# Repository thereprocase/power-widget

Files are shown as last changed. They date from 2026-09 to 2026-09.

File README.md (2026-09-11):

# Power Widget

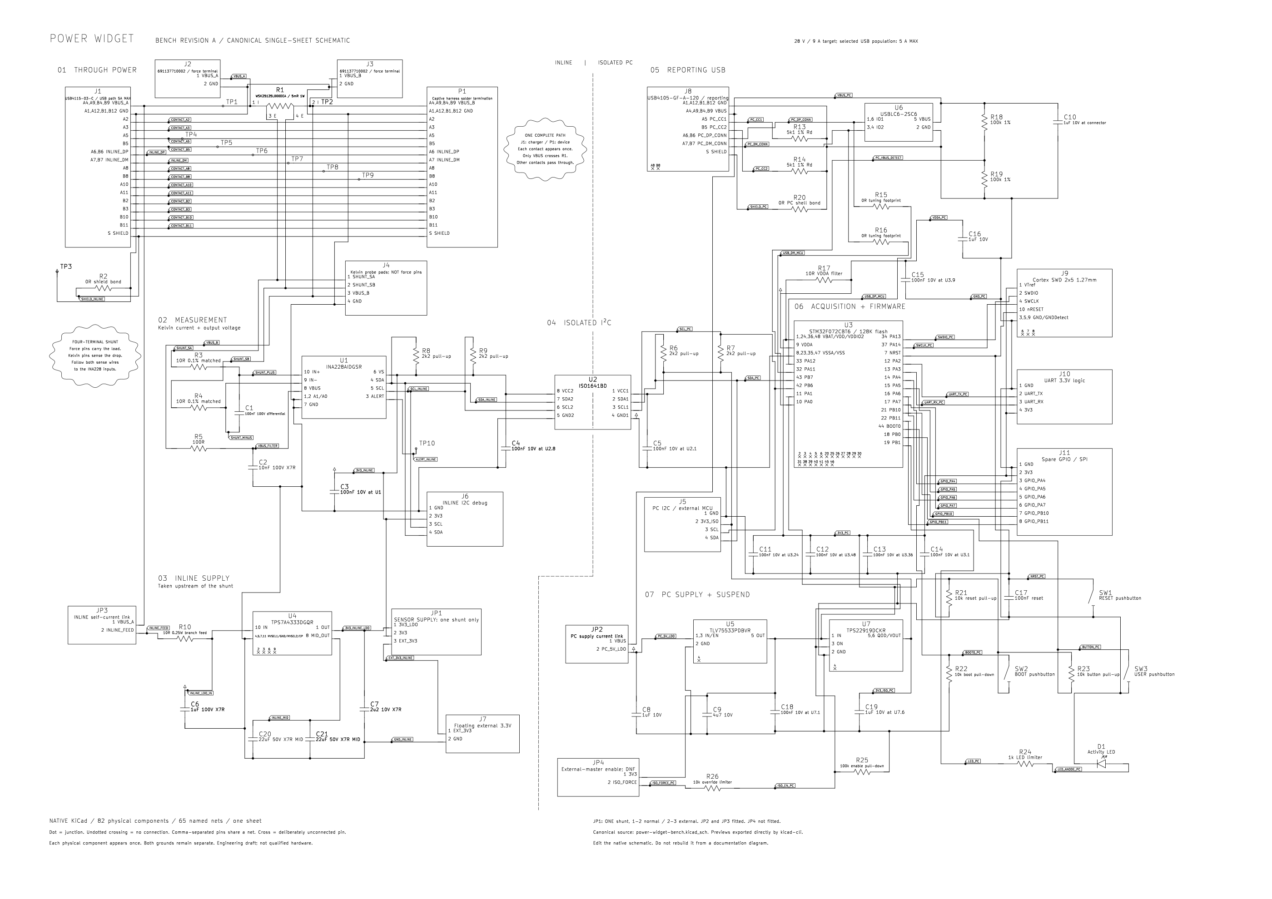
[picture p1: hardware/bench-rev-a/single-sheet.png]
Canonical single-sheet KiCad schematic: complete connectors, continuous wiring, Kelvin shunt and isolated USB reporting


**Canonical KiCad schematic.** This image is exported from the [native editable schematic](hardware/bench-rev-a/power-widget-bench.kicad_sch). The [earlier drawing was a layout mockup](hardware/bench-rev-a/layout-mockup.svg), not a KiCad export or the design authority.

**Reusable agent prompt, including the original inspiration:**

> think through the layout and topology from the perspective of a brilliant 1980s electrical engineer who stayed current on everything straight through to 2026. use his brain to architect the sheet and make it gorgeous
>
> Create a complete, flat, single-sheet schematic from this project's authoritative circuit data. Make the page explain the circuit: power and signal flow, measurement branches, isolation boundaries, supplies and service controls. Use traditional electrical symbols, continuous wires, explicit junction dots and unambiguous crossings: wire hops where supported, otherwise the native tool’s undotted-crossing convention. Keep every component and numbered pin accounted for; annotate wires with net names instead of replacing connections with labels. Preserve the circuit exactly. Use deliberate placement, readable typography and restrained color, with the clarity of a classic service-manual foldout. Verify connectivity against the source, export a zoomable SVG and printable PDF, put the image at the top of the README, and commit and push the result.
>
> Use conventional schematic symbols that engineers recognize on sight: ANSI-style zigzag resistors; parallel-plate nonpolarized capacitors and explicitly marked polarized capacitors; coil inductors; diode anode/cathode symbols with the cathode bar; LEDs with outward light arrows and photodiodes with inward light arrows; normally open or normally closed switch contacts shown in their unactuated state; connector pins, jumper links and test points; four-terminal Kelvin shunts with separate force and sense terminals; and, where present, BJT base/collector/emitter and emitter arrows, MOSFET gate/drain/source and body diodes, and op-amp triangles with +/− inputs. Use functional IC rectangles with named and numbered pins. Distinguish signal common, chassis ground and protective earth; preserve separate isolated returns. Use these symbols only for the devices and functions actually present. Verify each symbol's device type, terminal mapping, polarity, arrow direction and default state against the circuit data and the manufacturer's pinout. Rotate or mirror symbols only while preserving their electrical meaning. A wire crossing is not a junction unless explicitly dotted; a graphic must never imply an unintended connection. Check the rendered drawing as well as its underlying netlist.
>
> Implement the layout in the canonical, editable source of the design system this project actually uses: for KiCad, the native schematic in the existing KiCad project. Preserve component identities, footprints, pin mappings and PCB associations. Export the README image and PDF directly from that native source, and run the design system's electrical checks plus schematic-to-PCB consistency checks. Ensure the normal regeneration workflow cannot overwrite the native design with a competing source of truth. A separately drawn SVG or diagram is only a mockup, even if its netlist matches; label any intermediate mockup explicitly and do not present it as the canonical schematic.
>
> Make component identity and wire continuity obvious. Prefer one physical component in one location. If splitting a component improves the page, use the convention of a civil-engineering matchline: ghost the omitted portion at each location, mark the matchline, and add explicit reciprocal notes naming the other section and exactly where to look. Never leave the reader to infer that two symbols are one part or guess where a connection went. Use small cloud callouts to explain potentially confusing features; keep annotations visually distinct from electrical symbols and wires.
>
> Keep all lettering clear of conductors: never run a wire through a net name, reference, value, pin label or note. Place ordinary wire labels above or beside the wire with visible clearance; put boxed net tags on short annotation stubs in open space. Preserve the continuous main wire and use an explicit junction at each stub. Check the actual native export, not just the underlying coordinates or netlist. Visually inspect every functional section at readable magnification, including both ends of each connection, pin numbers, component values, junctions, crossings, polarity, symbol orientation and callouts. Then review the whole sheet for flow and consistency. Keep lettering clear of other lettering, symbol graphics (including LED arrows), and dashed graphical boundaries too. Add automated rendered-text/wire and text/text overlap checks where possible, and fix every collision before publishing.

**The whole circuit on one sheet:** [native SVG export](hardware/bench-rev-a/single-sheet.svg) · [printable A2 PDF](hardware/bench-rev-a/single-sheet.pdf) · [drawing notes and reproduction](hardware/bench-rev-a/README.md#single-sheet-schematic). All 82 physical components and 65 named nets. Each component appears once, including the complete J1 and P1 connectors. Dots identify connections; undotted crossings do not connect. Cloud notes explain the through path and Kelvin sensing.

An inline USB-C power monitor with isolated PC reporting. Preserve the original charger and cable negotiation while measuring voltage, current, watts and Wh.

**Newest design: [bench revision A native KiCad project](hardware/bench-rev-a/README.md).** It includes the sensing circuit, isolated USB reporting, STM32 firmware/debug access, assigned footprints and a routed bench PCB. Native KiCad checks report **zero ERC violations, DRC violations, unconnected items and schematic/PCB mismatches**. See the [layout review](docs/layout-review.md) for evidence and open gates. **The selected USB population is 5 A maximum; the project’s 9 A USB assembly is still a sourcing and qualification gate.**

## Board preview and drawings

Bench revision A: top copper, front silkscreen and board outline

Actual KiCad 2D plot of the **125 × 107 mm** bench PCB. The reporting USB-C port is on the lower long edge. This is an unbuilt prototype design; no 3D assembly render or hardware photographs are available yet.

| View | Contents |
|---|---|
| [PCB views](hardware/bench-rev-a/README.md#pcb-views) | Top and bottom copper plots from the routed board |
| [Circuit drawings](hardware/bench-rev-a/README.md#circuit-drawings) | Canonical single-sheet KiCad schematic, native exports and layout notes |
| [Architecture diagram](docs/architecture.md#two-power-domains-and-a-passive-main-path) | Transparent power path, sensing and isolated PC reporting |
| [Editable KiCad project](hardware/bench-rev-a/power-widget-bench.kicad_pro) | Schematic, PCB and local symbol/footprint libraries in the same directory |

## Design target

| Item | Requirement |
|---|---|
| Voltage | 28 V DC; at least 33.6 V component design margin |
| Continuous current | **9 A target: documented laptop maximum 8.5 A + 0.5 A** |
| Current design margin | **10.8 A: 1.20 × the 9 A target** |
| Inline data | USB 2.0; retain other contacts for charging transparency |
| Power accuracy | ±1% of reading at ≥5 W; ±5% from 0.5 W to below 5 W |
| Acquisition | About 58 fresh pairs/s, time-weighted one-second V/A/W reports and accumulated Wh |
| Reporting | Isolated USB-C on a long edge; timestamped serial, optional PC MQTT/HTTP forwarding |
| Product | Cheap but good; no display, battery or standalone logger required |

The selected [Apple/Dell/Lenovo laptop roster](docs/manufacturer-modes.md) drives the target. Extreme proprietary phone charging is excluded. The original 10 A/full-EPR and later 6 A specifications are superseded; voltage remains 28 V. No physical assembly is qualified yet.

## Early open question: captive male or two receptacles?

**Captive male is the bench baseline; final product topology remains open.** The original charger cable enters one receptacle, and a short custom captive plug extends its contacts to the device. The separate PC receptacle is on a long edge. OEM MagSafe/slim-tip cables may require charger-side placement and different energy accounting.

Two inline receptacles remain an allowed outcome if their orientation and cable-discovery behavior can be made transparent. Fixed CC wiring between two ordinary C-to-C cables fails some orientations; the [contact map and truth table](docs/connector-routing.md) explain the constraint. A generic cut cable is not a qualified captive assembly.

## Bench circuit and calculated feasibility

INA228 measures a 5 mΩ four-terminal high-side shunt. An inline LDO powers sensing; a PC-powered STM32F072CBT6 communicates through isolated I²C. The board includes SWD, UART, GPIO, force/Kelvin access and selectable floating sensor power. Dedicated links support measuring board consumption. Original charging contacts have no inline PD controller or substituted contract.

| Calculation | Preliminary result |
|---|---|
| Largest one-second DC error allocation, ≥5 W | **0.874%**, at 28 V / 5 W |
| Largest one-second DC error allocation, 0.5–<5 W | **4.539%**, at 28 V / 0.5 W |
| Sensor window / reporting | **17.28 ms / one second** |
| Added hot loop resistance, captive study | **14.879 mΩ** against a 15 mΩ target |
| Shunt heat at 9 A / 10.8 A | **0.405 W / 0.583 W** nominal |

These are engineering allocations, not measured specifications. One-second noise, dynamic energy accuracy, thermal behavior and connector performance require physical validation. A board-output reading needs a downstream cable correction before being called laptop-input energy.

## Design package

| Read | Purpose |
|---|---|
| [Design brief](docs/design-brief.md) | Current requirements and assumptions |
| [Bench hardware](hardware/bench-rev-a/README.md) | Circuit sheets, component schedule, jumpers and bring-up |
| [Manufacturer modes](docs/manufacturer-modes.md) | Primary laptop evidence and rating rule |
| [Connector wiring](docs/connector-routing.md) | Contact map and orientation proof |
| [Architecture](docs/architecture.md) / [decisions](docs/decisions.md) | Components, domains and unresolved gates |
| [Calculated budgets](analysis/results.md) / [method](docs/budgets.md) | Accuracy, loss, timing and assumptions |
| [Firmware contract](firmware/README.md) | MCU pins, sensor registers, timestamped serial and integration plan |
| [Energy comparison](docs/energy-comparison.md) | Matching intervals, board consumption, cable correction and uncertainty |
| [Validation](docs/validation-plan.md) / [cost and build](docs/cost-and-build.md) | Prototype qualification and planning allowances |
| [Research record](docs/sources.md) / [progress](docs/progress.md) | Sources, evidence gaps and checkpoints |

## Reproduce

```sh
python tools/budgets.py --check
python tools/orientations.py --check
python tools/capture_bench.py --check
python tools/draw_flat_schematic.py --check
```

Omit `--check` to regenerate. The budget and orientation tools use the Python standard library. Native schematic export/check commands require KiCad 9+ and librsvg; see [CAD reproduction](hardware/bench-rev-a/README.md#single-sheet-schematic). The budget sweep covers 19,635 settled operating points at the 9 A target. `capture_bench.py` exports and validates native pin/net data; `draw_flat_schematic.py` also runs KiCad ERC and PCB DRC with schematic parity.

## Next gate

Review the routed PCB against a fabricator's stack and capabilities, finalize the orderable BOM and captive strain relief, and resolve protection/overrange behavior before fabrication release. Source and qualify the required 9 A USB assembly; the selected USB parts support only the 5 A bench population. Firmware can start on the documented interfaces while these gates close. Physical validation must establish thermal capacity, measurement accuracy and OEM charging compatibility. Earlier designs remain in commit history.

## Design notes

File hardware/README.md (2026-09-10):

# Hardware status

The newest design is [bench revision A](bench-rev-a/README.md): a complete proposed circuit and routed **125 × 107 mm, four-layer PCB** with sensing, isolation, reporting USB, STM32F072, SWD/UART/GPIO, force terminals and selectable sensor power. It is intended for firmware work and connector experiments on one accessible board.

The package includes a root KiCad schematic, five child sheets, [connection-sheet previews](bench-rev-a/README.md#circuit-drawings), [top and bottom PCB plots](bench-rev-a/README.md#pcb-views), assigned footprints with local libraries, a draft component schedule and machine-readable connections. Native KiCad checks report **zero ERC violations, DRC violations, unconnected items and schematic/PCB mismatches**; see the [layout review](../docs/layout-review.md). There are no fabrication-release Gerbers, purchase-ready BOM, tested assembly or 3D assembly renders.

The design target is 28 V / 9 A continuous with 10.8 A margin. **The selected USB population is limited to 5 A; the 9 A USB assembly remains unsourced and unqualified.** Captive male is the bench baseline; the final product topology remains open. See the [connector map](../docs/connector-routing.md), [architecture](../docs/architecture.md), [open decisions](../docs/decisions.md) and [validation gates](../docs/validation-plan.md).

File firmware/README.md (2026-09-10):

# Firmware and PC reporting contract

Bench A uses **STM32F072CBT6, LQFP48, 128 KB flash / 16 KB RAM**, on the PC side of the isolation barrier. [board_contract.h](board_contract.h) provides register settings, pin constants and raw-value decoding to start implementation. There is no MCU application, USB stack, INA228 hardware driver, logger or tested binary yet.

## Board interface

| Function | MCU connection | Configuration |
|---|---|---|
| USB full-speed device | PA11 pin 32 D−, PA12 pin 33 D+ | HSI48 with USB CRS; native USB CDC ACM |
| INA228 I²C through U2 | PB6 pin 42 SCL, PB7 pin 43 SDA | I²C1 AF1, open drain, 100 kHz; external switched pull-ups |
| Isolator supply enable | PA1 pin 11 | High enables U7; default low via R25 |
| PC VBUS sense | PA0 pin 10 | 100k/100k divider; ADC input, no internal pull |
| Debug UART | PA2 pin 12 TX, PA3 pin 13 RX | USART2 AF1; start at 115200 8N1 |
| SWD | PA13 pin 34 / PA14 pin 37 | Leave debug active during bring-up |
| User button / LED | PB0 pin 18 / PB1 pin 19 | Button active low; LED active high |
| Boot / reset | BOOT0 pin 44 / NRST pin 7 | Physical buttons; boot defaults low |
| Spare headers | PA4–PA7, PB10–PB11 | Leave high impedance until configured |

VDDIO2 pin 36, VDD pins 24/48 and VBAT pin 1 all receive PC 3.3 V; VDDA pin 9 is filtered locally. Use a 64-bit monotonic microsecond clock, for example by extending a 1 MHz TIM2 counter. Handle rollover explicitly. Nominal 48 MHz is not a calibrated timebase: log host/device clock mapping and validate drift. USB suspend stops acquisition, preserves covered energy in RAM and records a gap on resume. A power reset starts a new session.

Before enabling I²C, enable U7 and allow its rail/isolator to settle; start with a conservative 5 ms bench delay and verify it physically. Before suspend, finish or cancel I²C, make PB6/PB7 high impedance with internal pulls disabled, turn PA1 off, extinguish the LED and enter an appropriate MCU low-power state. JP4 must be absent. Verify full reporting-port current; a software sleep call alone does not prove USB suspend compliance. The inline power and charging contacts do not depend on firmware execution.

## Acquisition contract

Use the INA228 at 7-bit address 0x40. Read and validate its identity before configuration. Register payloads are MSB-first; confirm whether the platform I²C API expects a 7-bit or shifted address. Read back configuration and surface discrepancies.

| Setting | Value / intent |
|---|---|
| CONFIG | 0x0000 after reset: wide shunt range, no temperature compensation |
| ADC_CONFIG, normal | 0xB922: continuous shunt + bus, 540 µs per channel, 16 averages |
| ADC_CONFIG, diagnostic | 0xBB6D: 1052 µs per channel, 256 averages |
| DIAG_ALRT configuration | 0x8000: latch status; poll CNVRF bit 1, require MEMSTAT bit 0 healthy |
| Raw VSHUNT | Register 0x04, signed 20-bit value in bits 23:4 of three bytes, 312.5 nV/count |
| Raw VBUS | Register 0x05, positive 20-bit value in bits 23:4, 195.3125 µV/count |

Normal sensor cadence is nominally 17.28 ms, about 57.87 fresh pairs/s. Poll readiness frequently enough to collect each result; begin with a roughly 2 ms poll interval and characterize overhead. Read ready/status, then both raw registers, then status again. If another completed conversion arrived during those reads, discard the potentially mixed pair and retry from the newly completed result; bound retries and flag overruns. A ready flag is not a sample counter, so delayed servicing cannot reveal exactly how many updates were missed. Retain an estimated missed count and mark uncertain coverage.

Calibrate shunt gain/offset and bus gain/offset against the declared PCB_B reference plane. Convert the signed shunt reading to current using calibrated resistance/gain, then multiply each calibrated voltage/current pair. Do not clamp small negative currents to zero or silently auto-zero against an attached laptop. Sensor absence, overflow, calibration failure and a legitimate zero-current reading are distinct states. The wide ADC span is not the board's physical rating.

The baseline uses MCU integration of calibrated readings. Do not treat the on-chip ENERGY register as meaningful without configuring SHUNT_CAL, reviewing its sign/overflow/timebase and applying compatible calibration. It is a useful dynamic-energy comparison during validation because its accumulation differs from multiplying output averages. Temperature conversion is disabled in normal mode; enabling it changes acquisition timing. Die temperature is not contact or shunt temperature.

## One-second reports and energy

Implement the time-weighted averaging, boundary splitting, coverage and integration rules in [energy-comparison.md](../docs/energy-comparison.md). Report V, I, the mean of per-pair watts and cumulative Wh. Keep signed net energy and separate to-B/from-B totals, splitting a reconstructed segment at a zero crossing when necessary. Use sufficient accumulator range and fractional precision; avoid repeated rounding of small energy increments. Never integrate through an unobserved sensor interval without an explicit, separately labeled estimate.

Use UTF-8 JSON Lines over USB CDC ACM. UART can expose the same protocol for bench debugging. Provisional protocol version 1 fields:

| Field | Meaning |
|---|---|
| `version`, `serial`, `boot_id`, `seq` | Protocol, instrument, session identity and monotonic record sequence |
| `mode` | Normally `logging_1s`; diagnostic modes have different noise/cadence |
| `window_start_us`, `window_end_us` | Monotonic one-second report boundaries |
| `covered_us`, `sample_count`, `missed_samples_est` | Coverage and acquisition health; estimated misses may be unknown |
| `plane` | `pcb_b` for primary measurements |
| `voltage_uV`, `current_uA`, `power_uW` | Time-weighted calibrated values; A-to-B current is positive |
| `energy_net_uWh`, `energy_to_b_uWh`, `energy_from_b_uWh` | Cumulative integrals over covered time, with fractional internal state |
| `uncovered_total_us`, `energy_complete` | Cumulative gaps and whether the total covers the whole session interval |
| `valid`, `status`, `calibration_id`, `time_uncertainty_us` | Quality, traceability and acquisition timing bound |
| `self_power_est_uW`, `self_model_id` | Optional characterized inline consumption estimate; otherwise null |

Use null values for unavailable measurements and explicit partial-window status for incomplete averages. A dropped host packet must not reset onboard energy. `reset_energy` starts a new energy epoch identified in records; MCU reset starts a new boot ID and never pretends to continue an old total. Store calibration identity, coefficients and checksum in protected flash; energy stays in RAM without frequent flash writes.

Proposed commands: `info`, `start`, `stop`, `set_mode`, `reset_energy`, `read_calibration`, and a request/reply clock-sync command returning device receive/transmit times. Calibration writes belong to an explicit fixture workflow. Use an authorized VID/PID arrangement before distributing a USB product; none is invented here.

## PC logger and implementation order

The first logger should preserve JSONL records, export CSV, show V/A/W/Wh and gaps, and reconnect by instrument and boot identity. Save host receive UTC plus device-to-UTC mapping and uncertainty. Optional MQTT publication or HTTP posting forwards records from the PC; transport latency must not replace acquisition timestamps. Keep wall-plug records and calibration metadata alongside the meter stream.

Bring up SWD/USB and the timer first, then U7/I²C/raw sensor reads, calibration and the one-second integrator, then serial logging and wall-energy comparison. Verify decoding/sign/range, constant-power integration, irregular timestamps, boundary splitting, power reversal, gaps, rollover and reboot behavior with deterministic vectors as implementation is added. Validate pulsed-load energy on hardware separately; synthetic tests cannot establish ADC fidelity.

Primary references: [ST STM32F072](https://www.st.com/resource/en/datasheet/stm32f072cb.pdf), [TI INA228](https://www.ti.com/lit/ds/symlink/ina228.pdf), [TI ISO1641](https://www.ti.com/lit/ds/symlink/iso1641.pdf), [TI TPS22919](https://www.ti.com/lit/ds/symlink/tps22919.pdf).

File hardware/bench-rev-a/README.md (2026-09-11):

# Bench revision A — native schematic and PCB

**28 V / 9 A continuous design target, 10.8 A design margin. No physical assembly is qualified.** This is the accessible prototype for connector experiments, calibration and MCU firmware development. It contains the complete proposed sensing, reporting, supply and debug circuits rather than a separate continuity fixture.

Open [power-widget-bench.kicad_pro](power-widget-bench.kicad_pro) in KiCad 9. The project includes the [native schematic](power-widget-bench.kicad_sch), [editable PCB](power-widget-bench.kicad_pcb), project symbols, and a snapshot of all 23 used footprint types. Native checks report **zero [ERC violations](erc.rpt), [DRC violations, unconnected items and schematic/PCB mismatches](drc.rpt)**. Read the [layout review](../../docs/layout-review.md) for board status and release gates. There are no fabrication-release Gerbers.

## PCB views

These are actual 2D plots exported from the checked-in KiCad PCB. No 3D assembly render or physical prototype photograph is available yet.

Top copper, front silkscreen and board outline

[Open top view](pcb-top.svg) — front copper with front silkscreen and outline.

<details>
<summary>Show bottom copper view</summary>

Bottom copper, front silkscreen and board outline, viewed from the top

[Open bottom copper view](pcb-bottom.svg) — bottom copper with front silkscreen and outline, **viewed from the top**. This is not a mirrored bottom assembly drawing.

</details>

## Circuit drawings

### Single-sheet schematic

Canonical single-sheet KiCad schematic

[Native SVG export](single-sheet.svg) · [A2 PDF](single-sheet.pdf) · [Editable schematic](power-widget-bench.kicad_sch) · [Native checks](single-sheet-check.json)

**This is the canonical KiCad schematic, not a separately drawn diagram.** The SVG and PDF are direct `kicad-cli` exports. The README PNG is only a white-background rasterization of that SVG so it remains readable in light and dark themes. The [earlier layout mockup](layout-mockup.svg) is retained as a reference, explicitly not the design authority. The former five-sheet schematic is superseded and remains available in Git history.

The force path runs left to right through R1, with its Kelvin measurement branch directly beneath it. Every J1 and P1 contact is visible in its **one complete connector symbol**. Isolated I²C crosses the marked boundary into the PC-powered reporting circuit. Cloud callouts explain the through path and the shunt's separate force and sense terminals. Every connection is wired continuously. Each net is named once on a short annotation stub, with visible clearance between the tag and conductors. The main wire remains continuous and the stub has an explicit junction. Dots mean junctions; undotted crossings are not connected. Unconnected pin numbers and their no-connect crosses appear inside the relevant packages. There are no off-sheet connections or split component units in this version.

KiCad reports **82 physical components, 65 named nets, 288 connected numbered pins and 30 unconnected numbered pins**. Six additional nonphysical power flags stay in the native schematic for ERC. The [migration comparison](native-migration-check.json) verifies unchanged pin/net connectivity, values, footprints and component UUIDs against the previous native design. PCB edits only flatten the 82 schematic association paths; copper, placement and all other PCB content are unchanged. Native [ERC](erc.rpt), [DRC and schematic/PCB parity](drc.rpt) pass with zero violations or unconnected items.

**Edit `power-widget-bench.kicad_sch` in KiCad.** The local `Bench.kicad_sym` library contains editable native symbol geometry; symbols are also embedded in the schematic. Reference, Value and Footprint are native fields. The auxiliary Domain, Section, CircuitKind, SourceFootprint and Notes fields supply metadata for the JSON and component-schedule exports. The historical JSON `sheet` field now identifies a functional placement group, not a separate schematic sheet.

The normal workflow flows in one direction: **native schematic → native netlist / JSON / schedule / SVG / PDF / PNG**. Neither export script writes a schematic, library or PCB. There is no separate Python circuit definition that can overwrite edits made in KiCad.

```sh
python tools/capture_bench.py             # export JSON and component schedule from KiCad
python tools/draw_flat_schematic.py       # run ERC/DRC/parity and export drawings
python tools/capture_bench.py --check     # verify native data exports are current
python tools/draw_flat_schematic.py --check
```

Use KiCad 9.0.9 and librsvg (`rsvg-convert`) to reproduce the checked-in exports. `KICAD_CLI` can name a local CLI executable. If no local KiCad CLI is found, the tools use Docker and the pinned [official KiCad container](https://gitlab.com/kicad/packaging/kicad-docker) for 9.0.9 in [kicad_native.py](../../tools/kicad_native.py); only the project directory is mounted, and the container runs as the invoking user without network access. `KICAD_DOCKER_IMAGE` can select another installed image. The exporter checks the actual plotted glyph bounds of all visible lettering—including all 65 net labels, references, values, pin labels and notes—against every native wire and against other lettering, rejecting wire/text and text/text collisions. Visual review additionally covers symbol graphics, dashed boundaries, and every functional section at readable magnification. The SVG check ignores only KiCad's export timestamp; the PDF, PNG and native reports have recorded hashes. Print the PDF at A2 or enlarge it, or zoom the vector files on screen.

These are CAD consistency results, not hardware qualification. The existing component, connector and fabrication gates still apply.

## Bench arrangement

The bench PCB is **125 × 107 mm**, four layers, with a candidate 2 oz outer / 1 oz inner stack. The force path runs across the upper portion. The PC receptacle sits on the bottom long edge, and a 3 mm copper keepout separates PC and inline domains across every layer. U2 bridges the gap; the ground plane is split by domain. This is functional isolation, not a certified insulation rating. Fabricator capability, thermal behavior and USB signal integrity require qualification.

J1 is the selected GCT inline receptacle; P1 is the board-side solder termination for a custom captive harness. Its individual contact wiring is defined in [connector-routing.md](../../docs/connector-routing.md). All CC-contact, SBU and SuperSpeed contact paths are retained; only USB 2.0 data performance is in scope. No inline PD controller, new e-marker, or charger-identification termination is fitted. The selected GCT USB population is limited to **5 A**. See [connector selection](../../docs/connector-selection.md); the 9 A USB assembly remains unsourced. Final product topology remains open.

| Access | Connections / use |
|---|---|
| J2 / J3 | Two-pin force connections: 1 = VBUS_A / VBUS_B, 2 = GND_INLINE. Electrically parallel with USB ports; use qualified terminals and short heavy leads. |
| J4 | 1 = upstream shunt Kelvin, 2 = downstream shunt Kelvin, 3 = PCB_B voltage, 4 = quiet inline ground. Sense only. |
| TP4 / TP5 | Separate A5 / B5 contact probes. Use suitable high-impedance, low-capacitance isolated probes; no grounded PC wire. |
| J5 | PC-side I²C: 1 = GND_PC, 2 = switched 3.3 V reference, 3 = SCL, 4 = SDA. External open-drain master supported with U3 held in reset and JP4 fitted. |
| J6 | Inline I²C: 1 = GND_INLINE, 2 = 3V3_INLINE, 3 = SCL, 4 = SDA. Floating instruments only. |
| J7 | Floating external supply: 1 = 3.3 V input, 2 = GND_INLINE. Current limit for initial bring-up; never tie to PC ground. |
| J9 | Cortex 10-pin SWD, 1.27 mm, keyed pin 7 absent. Pin 1 is target-voltage reference; pin 6 has no SWO. |
| J10 | 3.3 V UART: 1 = GND_PC, 2 = board TX, 3 = board RX, 4 = supply reference. |
| J11 | GPIO: GND_PC, 3V3_PC, PA4, PA5, PA6, PA7, PB10, PB11 in pin order. |

Header supply pins are references/outputs except the explicitly identified J7 input. External debug probes must not inject supply power. Grounded bench supplies, scopes and electronic loads can externally join the domains even when the board itself is isolated.

## Jumpers and power accounting

| Link | Normal state | Bench purpose |
|---|---|---|
| JP1 | One shunt on 1–2 | Selects inline LDO. Move the single shunt to 2–3 for floating external J7 supply; never fit both. |
| JP2 | Fitted | Replace with an ammeter to characterize PC-domain consumption. Input capacitor, ESD and VBUS divider are ahead of this link; use a USB input-current measurement for total PC-port draw. |
| JP3 | Fitted | Replace with a floating ammeter to measure the inline regulator/sensor branch. R10 remains in circuit. |
| JP4 | Not fitted | Forces isolator PC supply on for an external I²C master. Remove for normal firmware/suspend testing. R26 limits conflict with PA1. |

U4 derives sensor power from VBUS_A before the shunt. JP3 measures the main self-consumption branch; output-sense loading remains a separate small burden. The current 8 mA allocation is **not** a measured correction. Characterize actual draw over voltage, activity and temperature, including the measuring instrument's burden. See [energy comparison](../../docs/energy-comparison.md).

U7 switches U2 side 1 and its pull-ups using MCU PA1. The ISO1641 side-1 high-state maximum is 3.2 mA at 3.3 V, so simply sleeping the MCU would leave an excessive suspend burden. Before disabling U7, firmware releases PB6/PB7 and removes internal pull-ups; resume enables the rail and waits for settling before I²C. This circuit addresses the identified load; total USB suspend current still needs measurement.

## Bring-up sequence on this board

1. Close the documented PCB/connector/protection release gates, then inspect the assembly unpowered. Verify PC/inline isolation, both independent CC paths and no supply shorts. Leave OEM equipment disconnected.
2. Power J8 only. Establish 3V3_PC, reset/boot/SWD and USB enumeration. Verify PA1 can switch the isolator rail and that suspend removes its load. Sensor absence is a valid diagnostic state.
3. Use current-limited floating 3.3 V at J7 with JP1 on 2–3. Verify INA228 ID, raw readings, calibration commands and logging while VBUS is zero. This permits firmware work before an inline charger is attached.
4. Apply current-limited 5 V through qualified J2/J3 force wiring and a small known load. Verify polarity, the B voltage reference, one-second statistics and energy. Return JP1 to 1–2 and repeat with normal sensor power. Compare the JP3 measurement with the supply budget.
5. Sweep voltage and load for calibration. Increase core current toward 9 A only with rated force connections, monitored temperatures and an appropriately limited supply/load. The 10.8 A point needs an explicit continuous-capacity thermal test; it is not a brief survival pulse.
6. Qualify the actual captive assembly electrically and thermally, then compare direct versus inserted OEM charging across all orientations. Keep the controlled bench at known ≤28 V until overrange handling is resolved.

## Before PCB release

J1 and the force terminals now have selected parts and footprints; P1 has a board-side captive-harness termination. The shunt's four terminals and native pad/net mapping have been reviewed. Complete the orderable BOM, passive voltage/power and capacitor bias/stability review, actual captive assembly and strain relief. The selected USB parts remain limited to 5 A; sourcing a qualified 9 A USB assembly is a separate open gate.

Review the routed board against the fabricator's stack, copper weight, fine clearances and USB impedance requirements. Resolve inline ESD/overrange protection without compromising CC or low-power leakage. Review unpowered behavior, USB timing/current and regulator thermals; physical tests must establish measurement accuracy, current capacity and charging compatibility. See the [layout](../../docs/layout-review.md), [connector](../../docs/connector-selection.md) and [protection](../../docs/protection-review.md) reviews for the remaining work.

Export circuit data from the native schematic with `python tools/capture_bench.py`; use `--check` to detect stale exports. Its assertions check independent CC nets, no shared PC/inline nets and the MCU supply pins. These checks do not replace ERC, impedance/thermal layout work or hardware tests.

## Physical-design reproduction

With KiCad 9 Python `pcbnew` available:

```sh
python tools/capture_bench.py
python tools/footprint_bench.py
python tools/layout_bench.py
python tools/fanout_bench.py
# Route the generated DSN with a compatible Specctra router; use one optimization thread.
python tools/finish_bench.py --session hardware/bench-rev-a/power-widget-bench.ses
# The retained session requires these reviewed manual repairs:
python tools/review_route_bench.py
python tools/finish_bench.py
kicad-cli sch erc --exit-code-violations -o hardware/bench-rev-a/erc.rpt hardware/bench-rev-a/power-widget-bench.kicad_sch
kicad-cli pcb drc --schematic-parity --exit-code-violations -o hardware/bench-rev-a/drc.rpt hardware/bench-rev-a/power-widget-bench.kicad_pcb
```

`layout_bench.py` rebuilds the initial placement and constrained power routes; it overwrites the PCB. Preserve hand edits before regenerating. The checked-in PCB is the review artifact. The routing session and reports record subsequent routing/review, not hardware test results. Set `KICAD_FOOTPRINT_DIR` when the KiCad library is outside `/usr/share/kicad/footprints`. See [footprint provenance](footprint-provenance.md), [connector selection](../../docs/connector-selection.md), and [protection review](../../docs/protection-review.md).

Current native results: **ERC 0; DRC 0; unconnected items 0; schematic/PCB parity mismatches 0.** These are CAD results, not a current/voltage or charging-compatibility rating. [Top PCB view](pcb-top.svg) · [Bottom copper view](pcb-bottom.svg).

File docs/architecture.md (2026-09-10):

# Bench architecture

2026-09-10 — [bench A schematic and routed PCB](../hardware/bench-rev-a/README.md), not a fabrication release.

## Two power domains and a passive main path

```mermaid
flowchart TD
  A["Inline port A"] -->|VBUS| R["5 mΩ Kelvin shunt"]
  R --> B["Inline port B"]
  A <-->|"CC contacts / USB 2.0 / other contacts"| B
  A --> L["85 V regulator"]
  L --> S["INA228 sensor"]
  R -. "Kelvin voltage" .-> S
  B -. "Output voltage" .-> S
  S <-->|"Isolated I²C"| I["ISO1641 barrier"]
  I <-->|I²C| M["USB MCU"]
  P["PC reporting USB-C"] -->|"5 V and USB data"| M
```

Inline ground and appropriate inline shielding continue between A and B. The PC ground, PC shield network, supply, and USB data remain on their own island. The diagram is functional; the [bench circuit](../hardware/bench-rev-a/circuit.json) gives numbered connections. A fault-disconnect circuit remains unresolved.

## Charging and data path

| Signal group | Design intent | Required proof |
|---|---|---|
| VBUS contacts | Parallel rated power contacts into wide copper, through the shunt, to output contacts | Current sharing, contact rise, drop, overload behavior |
| GND contacts | Continuous low-resistance return; no sensing shunt | Return-path resistance; no reporting ground connection |
| CC/VCONN contacts | Preserve endpoint and original-cable signaling without added PD terminations | All orientations, attach/detach, e-marker discovery, VCONN and power-role changes |
| D+/D− | DC-coupled USB 2.0 differential path, no MCU tap, no charger-identification resistors | USB 2.0 data plus analog charging signatures; correct handling of duplicated receptacle pins |
| SBU | Preserve A8 and B8 as separate contact paths through the captive assembly | Determine whether any target charger/device needs them; no unexplained short or termination |
| SuperSpeed contacts | High-speed data/video outside required scope | Retain individual contact continuity in this bench assembly; qualify charging without claiming USB 3/video performance |
| Shields | Inline shields stay in the inline domain | Enclosure, screws, test points, and PC receptacle shell must not bridge the isolation barrier |

Manufacturer precedent exists for passive observation: Infineon's [CY4500](https://www.infineon.com/evaluation-board/CY4500) passes power and signal traffic while observing CC. It is an older, discontinued reference, not evidence that our topology supports EPR, the revised current envelope, or every OEM.

Favor a short custom pigtail with explicitly documented contact continuity. Do not select a stock USB 2.0 cable solely because it is thick or advertised for high power. Its internal e-marker and VCONN wiring can change the circuit we are trying to observe. The captive contact map is the bench baseline; final topology remains open through procurement and physical validation.

## Measurement circuit candidate

| Block | Candidate | Design purpose |
|---|---|---|
| U1 | TI INA228, DGS 10-pin | High-side shunt and bus-voltage conversion |
| R1 | Vishay WSK2512, 5 mΩ, 0.5% grade; candidate code WSK25125L000DEA | 9 A / 10.8 A target; thermal and footprint qualification pending |
| U2 | TI ISO1641BD, SOIC-8 | Bidirectional SDA, PC-to-sensor SCL |
| U3 | ST STM32F072CBT6, LQFP48 | USB device, I²C master, calibration, timing, reporting |
| U4 | TI TPS7A4333DGQR, fixed 3.3 V | Inline-side low-current supply |
| U5 | TI TLV75533PDBVR | MCU and isolator PC side |
| U6 | ST USBLC6-2SC6 | Reporting USB ESD network |
| U7 | TI TPS22919DCKR | Switch PC isolator supply and pull-ups for suspend |
| J1 / P1 | Selected 5 A bench receptacle / custom captive termination | Required 9 A USB assembly remains a procurement gate |

INA228 input limits and resolution come from its [datasheet](https://www.ti.com/lit/ds/symlink/ina228.pdf). The [WSK2512 specification](https://www.vishay.com/docs/30108/wsk2512.pdf) supports the four-terminal 5 mΩ candidate; use the **35 ppm/°C finished-part TCR**, not the lower resistive-alloy headline. Calibrate after assembly because a 0.5% nominal shunt is not a 0.1% calibrated system.

Provisional U1 nets, subject to schematic review:

| U1 pin | Net/function |
|---|---|
| 10 IN+ | Upstream shunt Kelvin sense through symmetric input filter |
| 9 IN− | Downstream shunt Kelvin sense through symmetric input filter |
| 8 VBUS | Output-side PCB voltage sense |
| 7 GND | Quiet reference at output-side PCB ground sense point |
| 6 VS | 3V3_INLINE; local decoupling |
| 5 SCL / 4 SDA | Isolator side 2 with local pull-ups |
| 3 ALERT | Inline test pad; poll status initially, no direct PC wire |
| 1 A1 / 2 A0 | Local ground; candidate I²C address 0x40 |

Start input-filter evaluation at two matched 10 Ω sense resistors and 100 nF differential capacitance. This is about 79.6 kHz differential RC bandwidth before ADC filtering. Check transient behavior and any gain correction from loading; calibration and the layout residual budget include this network. Keep Kelvin traces away from power-current constrictions. Choose voltage-rated capacitors and protection from the eventual fault envelope, not normal differential voltage alone.

The revised current rule requires the wider ±163.84 mV ADC range. At 5 mΩ it permits approximately ±32.8 A of conversion range; that is not the hardware current rating. The model recalculates quantization and noise for this range. At 9 A the shunt dissipates 0.405 W; at a 10.8 A design point it dissipates 0.583 W. The excluded phone-current scenario no longer sizes this build.

Use raw shunt voltage and bus voltage for signed calculations: current = calibrated shunt voltage / calibrated resistance; power = current × calibrated bus voltage. This keeps the reference plane explicit and avoids mistaking an IC full-scale error specification for percent-of-reading accuracy. Treat the on-chip power/energy registers as optional cross-checks until signed behavior, scale, and timebase are reviewed.

## Isolation and self-consumption

[ISO1641](https://www.ti.com/lit/ds/symlink/iso1641.pdf) is the provisional barrier. Side 1 faces the PC MCU; side 2 faces U1. Both sides use their own 3.3 V rail and 2.2 kΩ pull-ups. The side-1 output-low maximum of 0.710 V fits the selected MCU's conservative 0.3 × VDD input-low limit at 3.3 V; verify actual levels and timing. Start at 100 kHz. Validate hot-plug and unpowered states. U7 and PA1 switch side 1 plus its pull-ups off during USB suspend; PB6/PB7 must first become high impedance. The isolator's 3.2 mA maximum idle PC-side current motivates this switch; total USB-port suspend draw still needs testing.

Power U1 and isolator side 2 from an **A-side tap before the shunt** through the [TPS7A43 regulator](https://www.ti.com/lit/ds/symlink/tps7a43.pdf). PC VBUS powers U3, U5, and isolator side 1. Independent local supplies provide supply isolation without a transformer. Budget 8 mA inline draw initially, or 224 mW at 28 V. This is a planning allocation including bus activity, not a measured or guaranteed worst-case consumption figure. Heat and source perturbation remain validation items.

In the normal A-to-B direction, the A-side supply tap is excluded from the shunt reading. Output-voltage sensing and output-side leakage still contribute a small measured burden and are included in the low-power error model. With reverse current, the meter supply becomes part of what the B-side source delivers toward A. Report signed power at the fixed B measurement plane; do not relabel it as pure external-load power in both directions. If symmetric external-load accounting becomes mandatory, reconsider isolated PC-fed sensing or separately measure self-consumption.

JP3 permits a floating ammeter to measure the inline supply branch; JP2 measures the main PC supply branch. Full PC-port consumption also includes the circuits ahead of JP2. JP1 selects normal inline power or a floating external 3.3 V input for zero-VBUS firmware work. Use measured consumption or a characterized model with uncertainty in the [energy comparison](energy-comparison.md).

The routed bench board places the PC receptacle on the lower long edge with a physically separate ground area and a **3 mm all-layer copper keepout** between domains. This supersedes the initial 4 mm layout allocation; see the [layout review](layout-review.md). Verify package, board, pollution assumptions and test voltage. Isolation here is for the low-voltage measurement application; a component's kV withstand rating is not an instrument mains rating. A system can also connect the two domains externally—for example when the same laptop is both load and reporting host.

## Reference plane and mechanics

The primary reported voltage is at the B-side PCB sense pads. After the current-rule change, the resistance study uses a 75 mm captive cable and approximately 18 AWG copper area per polarity; neither is a final cable specification. Its resistance lies beyond that plane. Do not silently estimate laptop-terminal power from those pads: either label the plane clearly, add remote Kelvin sense conductors, or qualify a correction and its uncertainty.

The routed bench board is **125 × 107 mm**, expanded from the initial 100 × 80 mm allocation for accessible headers and routing. Its candidate four-layer stack uses 2 oz outer and 1 oz inner copper. Production miniaturization is deferred. Power entry, shunt and exit occupy the upper portion, with the sensor near the shunt and the MCU near the reporting edge. Review thermal gradients at Kelvin junctions and validate widths, copper weights, necks and vias against the resistance and temperature-rise budget. Mechanical strain relief must carry pigtail loads independently of solder pads.

## Remaining circuit gates

A numbered bench circuit, logical connector map and native KiCad board now exist. KiCad 9 ERC passes with zero violations. See the current bench review for PCB DRC and the remaining connector, protection and qualification gates. The same board's force and floating-supply connections support core testing while connector qualification proceeds. Resolve these gates before fabrication release.

## Sampling and firmware

The STM32 reads fresh INA228 results at nominal 17.28 ms cadence and forms time-weighted one-second V/A/W reports and cumulative Wh. The older 0.54 s precision mode remains diagnostic only. The final one-second noise allocation and dynamic energy response must be measured. USB CDC serial is the baseline; a PC logger can bridge to MQTT/HTTP. See the [firmware pin/register contract](../firmware/README.md) and [measurement/time boundaries](energy-comparison.md).

The user's [TPS25751 reference](https://www.ti.com/product/TPS25751) describes a negotiating PD controller. It is background for CC/PD behavior, not a component inserted into our transparent path; the original endpoints retain negotiation.

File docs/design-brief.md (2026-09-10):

# Design brief

Revision 0.5 — 2026-09-10. Laptop scope, full firmware-capable bench prototype and matched-interval energy logging.

## Purpose

Measure power flowing between an original USB-C charger and device, and report it to a PC through a separate, galvanically isolated USB-C connection. Preserve the charging behavior that would occur with the original charger and cable. Target a small, inexpensive, reliable instrument.

## Requirements

| ID | Requirement | Status |
|---|---|---|
| R01 | 28 V DC; 9 A continuous target = documented laptop maximum 8.5 A + 0.5 A | Selected for the dated Apple/Dell/Lenovo roster; physical rating unqualified |
| R02 | At least 20% electrical margin: 33.6 V and 10.8 A | Retained; the 0.5 A allowance is added before the 20% multiplier |
| R03 | Original source and load negotiate directly; no substitute PD contracts, charger identity, or cable-capability claims | User requirement |
| R04 | Preserve standard and vendor-specific charging communications, including Apple, Dell, Lenovo, and other relevant combinations | User requirement; compatibility must be demonstrated |
| R05 | USB 2.0 inline data; no requirement for higher-speed data or video | User requirement |
| R06 | Separate USB-C reporting receptacle on a long edge | User requirement |
| R07 | Galvanic isolation of reporting data, supply, ground, and unintended shield paths from the inline circuit | User requirement |
| R08 | Measured voltage/current, calculated watts and accumulated Wh; prefer signed bidirectional readings | User requirement |
| R09 | Power error within ±1% of reading at 5 W and above; ±5% from 0.5 W to below 5 W, within the rated envelope | User requirement |
| R10 | Measurement may require both inline power and a PC connection | User requirement |
| R11 | Cheap but good; no display, battery, or standalone logging required | User requirement |
| R12 | Checkpoint requirements, analysis, decisions, and progress to this repository | User requirement |
| R13 | Frequent fresh acquisitions feeding time-weighted one-second averages, with explicit coverage and gaps | Latest user requirement; nominal 57.87 fresh pairs/s candidate |
| R14 | Timestamped serial output; MQTT/HTTP can be PC-side bridges | Latest user requirement; USB serial baseline |
| R15 | Low insertion loss and accounted board consumption; compare wall and laptop-input energy over matching intervals | Latest user requirement; define measurement plane and combined uncertainty |
| R16 | First board includes onboard MCU, isolated sensing, force connections and accessible firmware/debug interfaces | User replaces the small fixture with a complete bench prototype |

The original 10 A/full-EPR request and subsequent 6 A/168 W requirement were superseded. Voltage remains 28 V. The rectangular design envelope is 252 W, without implying an OEM offers 28 V / 9 A. R02 is design reserve, not an operating rating. Extreme proprietary phone modes are excluded. See the [manufacturer survey](manufacturer-modes.md) for the evidence and remaining physical tests.

## Early open question: connector topology

**Keep both outcomes available. The user leans toward a short captive male pigtail on the load side.**

| Option | Physical arrangement | Decision basis |
|---|---|---|
| A — preferred candidate | Original charger cable into one receptacle; short captive USB-C male output; PC receptacle on long edge | Known added wiring, one external charger cable, fewer mating interfaces |
| B — allowed alternative | Two inline receptacles on opposing short edges; PC receptacle on long edge | Serviceability and no captive lead, weighed against two independent cable/marker/orientation states |

Captive male is the bench baseline after the [logical contact/orientation analysis](connector-routing.md); final product topology remains open through assembly sourcing and physical tests. A generic cut USB-C cable is not automatically a suitable pigtail: its second CC/VCONN contact, marker, terminations, and other conductors must be known. Do not freeze pin routing on the assumption that matching pin labels are sufficient.

## Engineering assumptions to validate

- Initial accuracy qualification: 5–28 V, 0.5 W up to rated current × voltage, 15–35°C ambient, after warm-up. Operation elsewhere may be explored, but is not yet an accuracy promise.
- The initial OEM survey focuses on Apple, Dell, Lenovo, and other laptop chargers identified for compatibility. The user's wording is broad; extreme proprietary phone modes are now excluded. The initial laptop roster is now bounded and documented; physical compatibility remains unqualified.
- The 9 A / 10.8 A design target follows the documented 8.5 A laptop maximum. Excluded phone-current studies remain in history.
- Accuracy applies initially to settled one-second DC reports at the defined plane. Frequent sampling and integration are required; pulsed-load energy accuracy and one-second noise need separate validation.
- Initial measurement plane is the output-side PCB Kelvin points. A captive cable adds loss beyond that plane; laptop-terminal power requires additional sensing or a qualified correction.
- Power pass-through should remain available during MCU reset or PC disconnection. This is a proposed transparency target, distinct from standalone measurement.
- 28 V is a nominal charging level; permitted source tolerance, overshoot, and the eventual overvoltage threshold need explicit treatment.
- Budget figures are planning allowances until actual suppliers, quantities, and assembly charges are checked.

Use matched energy intervals, clock/coverage metadata, characterized self-consumption and an explicit downstream cable correction; see [energy-comparison.md](energy-comparison.md).

## Required design outputs

1. Connector and charging feasibility assessment with explicit decision gates.
2. Provisional architecture, candidate parts, and measurement reference plane.
3. Reproducible error, voltage-drop, heating, and cost calculations.
4. PC reporting, calibration, prototype, and acceptance-test plans.
5. A complete bench circuit draft and firmware pin/register contract, with force, calibration and debug access.
6. A maintained next-step handoff. PCB/fabrication release follows schematic/ERC, footprint, connector and protection review.

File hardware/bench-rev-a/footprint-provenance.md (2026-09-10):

# Footprint provenance

Upstream KiCad footprint snapshots are licensed CC-BY-SA 4.0 with the KiCad library exception. See https://www.kicad.org/libraries/license/. Custom bench terminations are project designs. No USB assembly is rated above its manufacturer rating by this file.

- **USB_C_Receptacle_GCT_USB4115-03-C**: KiCad 9.0.9 snapshot: Connector_USB:USB_C_Receptacle_GCT_USB4115-03-C; shell pads renamed S where applicable
- **Captive_Termination**: Custom board-side wire solder pads; harness signal map mandatory; no claimed mating-connector footprint
- **WSK2512_5mR**: KiCad 9.0.9 snapshot: Resistor_SMD:R_Shunt_Vishay_WSK2512_6332Metric_T1.19mm; pad remap {'1': '1', '4': '2', '2': '3', '3': '4'}
- **Force_5mm_2pin**: Custom: Wurth 691137710002, 5.00 mm pitch / 1.30 mm drill; body clearance conservative, mechanical first article required
- **PinHeader_1x04_P2.54mm_Vertical**: KiCad 9.0.9 snapshot: Connector_PinHeader_2.54mm:PinHeader_1x04_P2.54mm_Vertical; shell pads renamed S where applicable
- **TestPoint_Pad_D2.0mm**: KiCad 9.0.9 snapshot: TestPoint:TestPoint_Pad_D2.0mm; shell pads renamed S where applicable
- **R_0805_2012Metric**: KiCad 9.0.9 snapshot: Resistor_SMD:R_0805_2012Metric; shell pads renamed S where applicable
- **VSSOP-10_3x3mm_P0.5mm**: KiCad 9.0.9 snapshot: Package_SO:VSSOP-10_3x3mm_P0.5mm; shell pads renamed S where applicable
- **SOIC-8_3.9x4.9mm_P1.27mm**: KiCad 9.0.9 snapshot: Package_SO:SOIC-8_3.9x4.9mm_P1.27mm; shell pads renamed S where applicable
- **C_0805_2012Metric**: KiCad 9.0.9 snapshot: Capacitor_SMD:C_0805_2012Metric; shell pads renamed S where applicable
- **HVSSOP10_DGQ**: KiCad 9.0.9 snapshot: Package_SO:HVSSOP-10-1EP_3x3mm_P0.5mm_EP1.83x1.89mm_ThermalVias; shell pads renamed S where applicable
- **PinHeader_1x02_P2.54mm_Vertical**: KiCad 9.0.9 snapshot: Connector_PinHeader_2.54mm:PinHeader_1x02_P2.54mm_Vertical; shell pads renamed S where applicable
- **C_1210_3225Metric**: KiCad 9.0.9 snapshot: Capacitor_SMD:C_1210_3225Metric; shell pads renamed S where applicable
- **PinHeader_1x03_P2.54mm_Vertical**: KiCad 9.0.9 snapshot: Connector_PinHeader_2.54mm:PinHeader_1x03_P2.54mm_Vertical; shell pads renamed S where applicable
- **SOT-23-5**: KiCad 9.0.9 snapshot: Package_TO_SOT_SMD:SOT-23-5; shell pads renamed S where applicable
- **SOT-363_SC-70-6**: KiCad 9.0.9 snapshot: Package_TO_SOT_SMD:SOT-363_SC-70-6; shell pads renamed S where applicable
- **USB_C_Receptacle_GCT_USB4105-xx-A_16P_TopMnt_Horizontal**: KiCad 9.0.9 snapshot: Connector_USB:USB_C_Receptacle_GCT_USB4105-xx-A_16P_TopMnt_Horizontal; shell pads renamed S where applicable
- **LQFP-48_7x7mm_P0.5mm**: KiCad 9.0.9 snapshot: Package_QFP:LQFP-48_7x7mm_P0.5mm; shell pads renamed S where applicable
- **SOT-23-6**: KiCad 9.0.9 snapshot: Package_TO_SOT_SMD:SOT-23-6; shell pads renamed S where applicable
- **PinHeader_2x05_P1.27mm_Vertical**: KiCad 9.0.9 snapshot: Connector_PinHeader_1.27mm:PinHeader_2x05_P1.27mm_Vertical; shell pads renamed S where applicable
- **PinHeader_1x08_P2.54mm_Vertical**: KiCad 9.0.9 snapshot: Connector_PinHeader_2.54mm:PinHeader_1x08_P2.54mm_Vertical; shell pads renamed S where applicable
- **SW_SPST_TL3342**: KiCad 9.0.9 snapshot: Button_Switch_SMD:SW_SPST_TL3342; shell pads renamed S where applicable
- **LED_0805_2012Metric**: KiCad 9.0.9 snapshot: LED_SMD:LED_0805_2012Metric; shell pads renamed S where applicable

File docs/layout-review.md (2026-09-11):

# Bench A physical-design review

**2026-09-11 schematic presentation update:** the [canonical schematic](../hardware/bench-rev-a/power-widget-bench.kicad_sch) is now one continuously wired native KiCad sheet. The [migration comparison](../hardware/bench-rev-a/native-migration-check.json) verifies identical pin/net sets, values, footprints and component UUIDs. Only the 82 schematic association paths changed in the PCB; all other PCB bytes are identical. Fresh native ERC, DRC and schematic/PCB parity checks pass with zero issues. See the [native export report](../hardware/bench-rev-a/single-sheet-check.json).

The repository now contains an editable, routed **125 × 107 mm, four-layer bench PCB**, the native KiCad project, project symbol/footprint libraries, and reproduction scripts. It is an engineering prototype design, **not a fabrication release or a qualified 9 A USB product**.

## Native check results

KiCad **9.0.9**, checked with errors, warnings and exclusions included:

| Check | Result |
|---|---|
| Schematic ERC | **0 errors, 0 warnings** |
| PCB DRC | **0 violations** |
| PCB connectivity | **0 unconnected items** |
| Schematic/PCB parity | **0 mismatches** |
| Independent pin/net comparison | All **82 circuit footprints / 65 named circuit nets** agree with `circuit.json` |
| Retained routing replay | Import retained SES, apply documented manual repairs, refill: native DRC/parity remain clean |

Evidence: [ERC](../hardware/bench-rev-a/erc.rpt), [DRC including schematic parity](../hardware/bench-rev-a/drc.rpt), [pin/net review](../hardware/bench-rev-a/board-connectivity-review.json). Six mechanical footprints are board-only mounting/strain-relief holes. Six schematic supply flags are nonphysical. No electrical or physical rule violations are hidden by exclusions.

The native schematic was opened/exported and visually reviewed. Fixes included escaped root-sheet text, on-grid pin/wire endpoints, project library resolution and left-side net-label alignment. The PCB's top and bottom plots were inspected after routing. These checks establish CAD consistency; they do not measure accuracy, insertion loss, temperature or charging compatibility.

## Board arrangement and routing

- The upper domain contains the inline receptacle, captive-wire termination, 5 mΩ four-terminal shunt, force terminals, INA228 and its local supply. Force connections allow core testing without USB equipment.
- The lower domain contains USB reporting, STM32F072, SWD, UART/GPIO headers and RESET/BOOT/USER buttons. Current links and floating sensor-power selection remain accessible.
- A **3 mm copper keepout across every copper layer** separates the two domains. U2 is the only signal bridge. Ground pours remain separate; this is a functional isolation design, without a certified creepage/withstand claim.
- Candidate stack: 70 µm outer copper, 35 µm inner copper, nominal 1.6 mm total including mask. In1 carries the split reference plane with routed exceptions; B has separate ground pours, and the inline F layer has ground fill. The fabricator must approve the actual stack and tolerances.
- The force/shunt VBUS routes use 3 mm trunks with 1.8 mm transitions into the current pads. The return has a 4 mm trunk plus ground pours. The USB branch uses independent short fanouts from all four VBUS contacts; its narrower copper is for the **5 A populated USB variant**, not permission to operate the selected connector at 9 A.
- J1's communication signals use explicit 0.4 mm / 0.2 mm drilled via escapes. Their net class permits **0.1 mm inter-signal clearance**; ordinary nets retain 0.15 mm clearance and 0.15 mm tracks. Hole-to-copper clearance is 0.2 mm and copper-to-edge clearance 0.25 mm. Confirm these capabilities specifically with **2 oz outer copper** before ordering. This is a real fabrication constraint, not a DRC exemption.
- Four 3.2 mm mounting holes and two 3 mm captive-cable strain-relief holes are provided. Cable restraint and the selected force-terminal body still require mechanical first-article checks.

The retained routing session was produced with Freerouting 1.9.0 and single-threaded optimization. Native KiCad checks, rather than the router's completion message, determined acceptance. Manual repairs move two signal routes clear of J1's locating hole and remove a redundant ground-via stub; ground fills complete that connection. The commands are recorded in the [bench README](../hardware/bench-rev-a/README.md).

## Open release gates

1. **9 A USB assembly sourcing:** the selected GCT socket and candidate captive plug are rated 5 A aggregate VBUS. No primary-source-backed 9 A mating assembly has been selected. The exact captive plug drawing, both CC/VCONN paths, wiring and strain relief need review. See [connector selection](connector-selection.md).
2. **Power and measurement qualification:** test the force path at 9 A and its 10.8 A margin, including shunt derating, contact sharing and copper temperature. Reconcile measured insertion loss with the budget; the existing 14.879 mΩ hot-loop figure is an allocation, not extracted PCB resistance or a measurement. Establish the defined voltage plane, downstream conductor loss and board self-consumption.
3. **Voltage/protection and passive BOM:** the 85 V sensing regulator removes the former supply-voltage concern, but there is no qualified universal surge clamp, hardware current cutoff or full-EPR rating. Select actual capacitor MPNs using DC-bias/tolerance data and verify regulator stability, start-up and thermal performance. See [protection review](protection-review.md).
4. **USB behavior and fabricator review:** conductor continuity is captured and routed. USB 2.0 impedance, skew, return paths, hot-plug/ESD and actual OEM negotiation are not qualified by DRC. Review/tune the routing against the fabricator's stack and test USB performance and all required orientations before release.

The firmware pin contract is now tied to a native board suitable for further bench development planning. Firmware implementation, fabrication, assembly and physical tests have not been performed in this checkpoint.

## Views

[Top copper with component labels](../hardware/bench-rev-a/pcb-top.svg) and [bottom copper with top-side labels for location reference](../hardware/bench-rev-a/pcb-bottom.svg). Both views look from the top; the bottom plot is not mirrored and is not an assembly drawing.

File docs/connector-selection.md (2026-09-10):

# Bench connector and harness selection

The project target remains **28 V / 9 A continuous, 10.8 A current design margin**. The selected catalog USB population is a **5 A maximum bench variant**. It does not meet the project's 9 A USB assembly requirement. Force terminals permit separate current-limited core testing with all USB power equipment disconnected.

| Interface | Selection | Published rating / decision |
|---|---|---|
| J1 inline receptacle | GCT USB4115-03-C | 24 contacts, vertical SMT, 48 V DC / 5 A aggregate VBUS; use at 5 A maximum |
| Captive plug candidate | GCT USB4155-03-C | Full-contact PCB-edge plug, 48 V DC / 5 A aggregate VBUS; drawing and harness construction are procurement gates |
| P1 on bench PCB | Custom wire solder termination | Board-side interface only; **not** the mating plug footprint or a purchased cable assembly |
| J8 reporting | GCT USB4105-GF-A-120 | USB 2.0, 16 contacts, 48 V DC / 5 A catalog rating; reporting port uses ordinary USB power limits |
| J2/J3 force connections | Würth 691137710002 | Two poles, **5.00 mm** pitch, 1.30 mm recommended holes, 16 A UL / 24 A VDE; 0.4 Nm terminal torque |

Primary sources: [GCT USB4115](https://gct.co/connector/usb4115), [GCT USB4155](https://gct.co/connector/usb4155), [GCT USB4105](https://gct.co/connector/usb4105), [Würth terminal drawing and ratings](https://www.we-online.com/components/products/datasheet/691137710002.pdf).

## Captive assembly drawing requirements

P1 uses four separate plated wire holes for VBUS and four for return, plus 15 smaller signal/shield holes. The cavity/pad labels in `circuit.json` are the electrical reference. Wire each correspondingly named plug contact; omit the plug's duplicate B6/B7 contacts as specified in the logical plug map. Maintain A5 and B5 independently. Preserve SBU, the eight other signal contacts and shield continuity. No new CC pull resistors, PD controller, e-marker or inline D+/D− charger-signature network is fitted.

The small pads form three rows of five: A2 A3 A5 A6 A7; A8 A10 A11 B2 B3; B5 B8 B10 B11 S. The two larger columns carry VBUS A4/A9/B4/B9 and GND A1/A12/B1/B12 respectively. This is a wiring interface, not permission to swap USB pin labels based on a visual plug view. Verify contact continuity against the actual plug drawing before power. Keep USB 2.0 D+/D− as a short pair, maintain shielding and add independent cable strain relief; solder joints must not take cable pull loads.

No orderable 9 A USB mating assembly has been established from primary manufacturer evidence. A 240 W advertisement establishes neither 9 A nor adequate contact temperature. Larger wires and parallel PCB copper cannot increase the mating contacts' published rating. Qualification must cover both possible CC/VCONN paths, contact current sharing, insertion loss, repeated mating, temperature and the target OEM chargers/laptops. The final topology question remains open, with captive male preferred. The vertical J1 is an accessible bench choice, not a commitment to the final enclosure.

## Force fixture limitations

The terminal's 20 mΩ maximum contact-resistance specification means fixture losses cannot be assumed negligible. Measure at the PCB Kelvin planes and de-embed terminal/wire losses when comparing instruments. The low insertion-loss allocation for the USB product does not include force-fixture terminal loss. Perform 9 A and 10.8 A core tests only with current-limited bench source/load, sized leads and independently monitored contact/PCB temperature; the PCB's current rating is not yet established by measurement.

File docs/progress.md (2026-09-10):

# Progress and handoff

## 2026-09-10 — Requirements and design planning

The user requested questions first, then a design brief before research. They replaced the original 10 A/full-EPR scope with 28 V / 6 A plus 20% margin, specified USB 2.0, isolated PC reporting, low-power accuracy, and a cheap-but-good build. They added vendor-specific charging transparency. Connector topology remains open: they lean toward captive male and explicitly allow either that or two receptacles.

The user authorized initialization and ongoing checkpoints in this repository. The existing repository was empty. Its visibility was private and has been retained.

- Requirements checkpoint: `3717ae99631b06e8b059001d02c9f6f5ece083c5`.
- Primary-source checks established a provisional INA228 / 5 mΩ / isolated-I²C architecture.
- Connector topology, higher-current OEM modes, and overrange behavior remain release gates.
- Initial research could not establish exact OEM proprietary signaling or source connector assemblies. Those gaps are explicitly recorded in `sources.md`.

## Requirement change during planning

The user replaced the 6 A rating with **half an amp above the applicable manufacturer current modes**. The retained 20% margin is applied after adding 0.5 A. Numeric OEM maximum remains unresolved; current manufacturer retrieval did not establish it. The analysis now uses explicit scenarios, principally 9 A continuous / 10.8 A design, without presenting that as a verified requirement.

The larger current scenarios changed the proposed ADC range to ±163.84 mV, prompted a shorter/thicker pigtail resistance allocation, and exposed the 1 W shunt's limit in the 12.5 A / 15 A-design scenario. The current sensor and isolated-I²C architecture remain provisional.

Architecture checkpoint: `3a62ac91781fd497afed0c893fcbd64117126e75`.

## Planning package

- Deterministic budget tool and generated Markdown/JSON/CSV results; all assumptions are explicit.
- Manufacturer-current rule and evidence gaps; both connector outcomes remain available.
- Calibration, qualification, prototype sequence, protocol draft, and cost allowances.
- No schematic, PCB, firmware binary, or tested hardware exists at this stage.
- Numerical verification: 19,635 points in the provisional 9 A study; worst allocated precision errors 0.874% at 5 W and 4.539% at 0.5 W, both at 28 V. Deterministic outputs reproduce; local document links resolve; no whitespace errors found.
- A lower-than-5 V measurement range remains an explicit supply/qualification question; the initial sweep does not claim to cover every programmable charger voltage.

## Historical handoff after checkpoint 3 (superseded below)

1. Obtain current-mode evidence for exact target OEM combinations and close the numeric rating; no global maximum has been claimed.
2. Build the connector feasibility fixture and verify CC/VCONN/e-marker behavior across orientations. Prefer captive male if it passes; retain two receptacles as an allowed outcome.
3. Resolve fault handling and measurement-plane choices.
4. Evaluate the sensing core with a current-limited source/load, then capture a schematic after the gates close.

## Checkpoint 4 — Laptop scope and contact routing

2026-09-10: user requested a full firmware-capable bench prototype in place of the tiny test coupon, then explicitly excluded extreme proprietary phone charging. Verified Dell 165 W output modes, Lenovo 140 W embedded output specification, and Lenovo C170's official 8.5 A maximum. Selected 28 V / 9 A continuous target with 10.8 A design margin for the laptop roster. Apple still needs an actual unit label/trace; no universal compatibility is claimed.

Added the captive contact map and reproducible four-case CC topology model. Fixed two-receptacle wiring fails two local orientations. Captive is the bench baseline; procurement, cable-discovery traces, current qualification, and final topology remain open. Next: capture the full bench sensing/MCU/debug circuit and bring-up plan.

## Checkpoint 5 — Full bench draft and interval energy measurement

2026-09-10: captured the complete bench circuit with 82 components and 65 named nets across five child sheets. Added native KiCad draft files, independently generated SVG connection sheets, component schedule, machine-readable connectivity and a reproducible generator. No native KiCad/ERC, PCB layout, physical build or hardware test is claimed.

The board now specifies STM32F072CBT6, SWD/UART/GPIO, reset/boot/user controls, isolated INA228 sensing, force/Kelvin access and floating external sensor power. Separate current links support board-consumption characterization. Added TPS22919 switching of the PC isolator supply after its idle-current maximum exposed a USB suspend problem; total suspend behavior remains a bench gate.

The user added frequent sampling, one-second averages, timestamped serial/MQTT/HTTP output and a matched wall-versus-laptop energy diagnostic. Normal logging now uses nominal 17.28 ms sensor windows and one-second software reports. The ±1 µV final-average noise allocation is provisional; no automatic averaging improvement or dynamic energy accuracy is claimed. Serial is the board baseline; MQTT/HTTP are optional host bridges.

Added a firmware pin/register contract and raw signed decoding, plus time-weighted power/Wh, coverage, clock mapping, board self-consumption and downstream cable-correction rules. Native firmware/USB drivers and the PC logger are still to be implemented. The current numerical envelope stays 28 V / 9 A with 10.8 A margin; removed excluded phone scenarios from active calculation outputs.

Verification: all three generators reproduce their outputs; 19,635 DC budget points retain 0.874% / 4.539% worst allocations. Circuit domain/CC assertions pass, all five SVG previews were visually inspected, local document links resolve, and JSON parses. The C header compiles with strict host-GCC warnings and passes signed decoding endpoint vectors. These are design-file/software checks, not KiCad ERC or physical validation.

Next physical-design work: review native schematic/footprints/ERC, source the captive and force assemblies, resolve inline overrange/ESD behavior and route the accessible PCB. Begin firmware on the documented interfaces, then validate DC/noise/energy through force connections before qualifying OEM cables and orientations.

## 2026-09-10 — Native circuit review and routed firmware bench

Selected GCT USB4115-03-C inline receptacle, USB4155-03-C captive plug candidate and USB4105-GF-A-120 reporting receptacle, with Würth 691137710002 force terminals. The GCT USB population is explicitly 5 A maximum; a qualified 9 A USB assembly is still a sourcing gate, not a downgraded project target.

Replaced the inline supply with TPS7A4333DGQR (85 V), revised branch resistance/capacitors and documented the overrange/clamp decision and its limits. All 82 circuit footprints are assigned; project symbols and 23 footprint types are included with provenance. Native schematic parsing, label orientation, grid and supply declarations were corrected.

Created and routed a 125 × 107 mm four-layer bench PCB with force connections, captive termination/strain relief, isolated long-edge PC USB, MCU, SWD/UART/GPIO, current links and buttons. Explicit power buses and connector fanouts, split ground pours and all-layer isolation keepout are included. Smaller signal vias and 0.1 mm signal-net clearance require fabricator approval for the proposed 2 oz copper.

KiCad 9.0.9: **ERC 0 errors/0 warnings; PCB DRC 0 violations, 0 unconnected items, 0 schematic-parity mismatches**. Independent pad/net mapping agrees for 82 circuit footprints and 65 circuit nets. Replaying the retained routing session and manual clearance repairs reproduces a clean native DRC. Native schematic and PCB plots were inspected. Budget/orientation/circuit generation checks still pass.

See [layout review](layout-review.md), [connector selection](connector-selection.md), and [protection review](protection-review.md) for remaining gates. No fabrication, firmware implementation, physical current rating or OEM interoperability result is claimed.

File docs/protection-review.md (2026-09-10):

# Bench voltage and protection review

## Decision

Use an **85 V TPS7A4333DGQR fixed 3.3 V regulator** for the inline sensing branch instead of TPS7A1601. Preserve a passive main power path. Do not fit a 33 V/36 V TVS across VBUS: it can conduct during an otherwise valid higher-voltage PD contract, which this monitor must not interfere with. No main-path cutoff or PD renegotiation circuit is introduced.

This resolves the schematic architecture choice; it does **not** establish qualified surge protection or full EPR operation. The target for accuracy/continuous operation remains 5–28 V. The selected USB connector population's published 48 V rating must not be treated as a verified 50.4 V or transient rating. Higher-contract, hot-plug and source-fault testing remain release gates.

## Circuit changes and checks

- U4: TPS7A4333DGQR, 4–85 V input, fixed 3.3 V output. EN is intentionally floating, using the datasheet's internal pull-up. **Do not connect EN directly to high VBUS**; its operating limit is lower than IN.
- MVSEL1 and MVSEL2 tied to inline ground select a nominal 15 V intermediate rail. Both NC pins and the unused PG output remain unconnected. Exposed pad 11 is inline ground.
- R10: 10 Ω / 0.25 W branch resistor. At the provisional 8 mA inline draw its drop is 80 mV and dissipation is 0.64 mW, leaving supply headroom at a 5 V input.
- C6: 1 µF / 100 V X7R input reservoir; C2: 10 nF / 100 V VBUS-filter capacitor. These see the high-voltage supply. C1 is 100 nF / 100 V differential, without a connection to PC ground.
- C7: 2.2 µF / 10 V output. C20/C21: two 22 µF / 50 V X7R intermediate-rail capacitors. The datasheet requires effective intermediate capacitance at least three times the effective total OUT-connected capacitance. Verify chosen capacitor tolerance/DC-bias curves, all downstream decoupling and start-up behavior before BOM release. Nominal capacitance alone is insufficient evidence.
- INA228's bus/common-mode operating range is up to 85 V. All ordinary MCU/reporting components remain on their own low-voltage PC domain.
- The 8 mA inline self-consumption allowance remains provisional. At 28 V it implies approximately 198 mW dissipated between the inline regulator stages, plus sensor/isolator dissipation. At 50.4 V the regulator estimate rises to approximately 377 mW. These are allocation calculations, not thermal qualification or permission to operate the USB assembly above its rating.

Primary references: [TI TPS7A43 datasheet, including DGQ package drawing](https://www.ti.com/lit/ds/symlink/tps7a43.pdf), [TI INA228 datasheet](https://www.ti.com/lit/ds/symlink/ina228.pdf).

## Why no blanket TVS claim

The [Vishay SMBJ table](https://www.vishay.com/docs/88392/smbj.pdf) lists SMBJ48A at 48 V stand-off and 77.4 V clamp at the specified 7.8 A pulse. That does not prove an 85 V device is protected under arbitrary cable inductance, source current, temperature or overshoot. A 48 V contract's allowed source tolerance also needs coordination with stand-off/leakage and connector ratings. SMBJ51A leaves still less clamp margin. Neither is fitted or presented as a resolved universal solution.

For the first bench build, use controlled, current-limited sources within the qualified range; no hardware overcurrent cutoff is present. No source-independent hot-plug, ESD, reverse-polarity or surge rating is claimed. Test those conditions with fixtures before OEM equipment is attached. The PC port retains USBLC6-2SC6 data/5 V protection. Verify supply sequencing, USB suspend behavior and both isolation domains before firmware bring-up with external instruments.

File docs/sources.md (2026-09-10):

# Research record

Checked 2026-09-10. Primary manufacturer and standards-body material only. Links are references, not redistributed copies of third-party documents. Calculated budgets and architecture choices are our engineering analysis.

| ID | Source | What it establishes / limitation |
|---|---|---|
| S01 | [USB-IF Type-C release 2.5 landing page](https://www.usb.org/document-library/usb-type-cr-cable-and-connector-specification-release-25) | Current page identifies release 2.5, dated April 2026. The full downloadable text was not retrieved; exact current normative topology clauses remain an open research item. |
| S02 | [TI Type-C and PD primer, SLYY109B](https://www.ti.com/lit/wp/slyy109b/slyy109b.pdf) | CC orientation and termination roles, VCONN powering cable electronics, and USB 2.0/PD paths. Legacy discussion is not the source for current EPR limits. |
| S03 | [TI TPS26750 datasheet](https://www.ti.com/lit/ds/symlink/tps26750.pdf) | EPR includes 28, 36, and 48 V and AVS. This negotiating controller is a protocol reference, not a selected inline component. |
| S04 | [TI INA228 datasheet, SLYS021A](https://www.ti.com/lit/ds/symlink/ina228.pdf) | Tables/sections 6.5, 8.1.3, 8.1.4: offset and drift, bus error, quantization, noise versus timing, and input filtering. |
| S05 | [TI INA228 product page](https://www.ti.com/product/INA228) | Active product, packaging, INA238/INA229 alternatives. No usable current unit-price quote was returned. |
| S06 | [TI INA238 datasheet](https://www.ti.com/lit/ds/symlink/ina238.pdf) | Lower-cost performance comparison; larger offset and coarser resolution must be re-budgeted. |
| S07 | [TI INA226 datasheet](https://www.ti.com/lit/ds/symlink/ina226.pdf) | 36 V sensor alternative; little voltage headroom above 33.6 V and less attractive low-power budget. |
| S08 | [Vishay WSK2512 datasheet, document 30108](https://www.vishay.com/docs/30108/wsk2512.pdf) | Four-terminal resistor, value/tolerance ordering, finished-part TCR, derating and land-pattern ranges. Supplier stock for the proposed code is not verified. |
| S09 | [TI ISO164x datasheet, SLLSFC2D](https://www.ti.com/lit/ds/symlink/iso1641.pdf) | Supply separation, channel direction, I²C logic constraints, supply-current data, and package-specific insulation. |
| S10 | [TI TPS7A16 datasheet](https://www.ti.com/lit/ds/symlink/tps7a16.pdf) | 60 V regulator family, adjustable output, supply current, thermal and stability constraints. |
| S11 | [ST STM32F042x4/x6 datasheet](https://www.st.com/resource/en/datasheet/stm32f042f6.pdf) | Earlier MCU study, superseded by the F072 bench choice in S20. |
| S12 | [TI SN6505B datasheet](https://www.ti.com/lit/ds/symlink/sn6505b.pdf) | Transformer-driver alternative if sensing is powered across an isolation barrier; not the baseline. |
| S13 | [Infineon CY4500](https://www.infineon.com/evaluation-board/CY4500) | Historical passive PD-observer design precedent. Product page identifies end-of-life status; this is not an EPR/6 A qualification source. |
| S14 | [TI USB PD power negotiations, SLVA842](https://www.ti.com/lit/an/slva842/slva842.pdf) | Source/sink negotiation and trace comparison methodology; predates EPR. |
| S15 | [Lenovo Legion Slim 140W GX21M50625](https://www.lenovo.com/us/en/p/accessories-and-software/chargers-and-batteries/chargers/gx21m50625) | Public HTML's embedded specification was subsequently retrieved: 20 V / 7 A, 19.95 V / 5 A, and 5/9/15 V / 3 A. |
| S16 | [Lenovo Legion 5 15IRX10 PSREF](https://psref.lenovo.com/syspool/Sys/PDF/Legion/Legion_5_15IRX10/Legion_5_15IRX10_Spec.pdf) | Separates USB-C input from higher-power slim-tip adapter offerings; do not infer USB-C current from bundled adapter wattage. |
| S17 | [Bourns CSS4J-4026](https://www.bourns.com/docs/product-datasheets/css4j-4026.pdf) | Higher-power four-terminal shunt alternative; 5 mΩ is on-request and has a different TCR. Not selected; the active design retains WSK2512 for laptop scope. |
| S18 | [Dell 165 W USB-C GaN 450-BFTY](https://www.dell.com/zh-cn/shop/-165w-usb-c-gan-/apd/450-bfty/) | Manufacturer output table: 28 V / 5.893 A and 20 V / 6.5 A; separate fault current limit is not an operating mode. |
| S19 | [Lenovo C170 / LA170 official description](https://www.lenovo.com.cn/wiki/product-doc-46691.html) | 20 V / 8.5 A maximum and marked C-Slim cable; verify regional unit/AC-input conditions. |
| S20 | [ST STM32F072 datasheet DS9826 Rev 6](https://www.st.com/resource/en/datasheet/stm32f072cb.pdf) | F072CB LQFP48 pinout, USB/HSI48, I²C/UART/debug and 128 KB flash / 16 KB RAM. Bench pin map checked against figure 8 and alternate-function tables. |
| S21 | [TI TLV755P](https://www.ti.com/lit/ds/symlink/tlv755p.pdf) | PC 3.3 V regulator candidate and DBV pinout. |
| S22 | [ST USBLC6-2](https://www.st.com/resource/en/datasheet/usblc6-2.pdf) | SC6 paired USB data pins and reporting-port ESD topology. |
| S23 | [TI TPS22919](https://www.ti.com/lit/ds/symlink/tps22919.pdf) | SC70-6 load switch, ON control, output discharge and low off current; switches PC isolator supply. |
| S24 | [TI TPS25751](https://www.ti.com/product/TPS25751) | User-provided PD reference; this is a negotiating controller, not a selected transparent inline part. |
| S25 | [KiCad schematic format](https://dev-docs.kicad.org/en/file-formats/sexpr-schematic/) | Native draft serialization reference; native KiCad 9 loading and ERC now pass; see bench reports. |
| S26 | [Apple 140 W adapter MW2M3AM/A](https://www.apple.com/shop/product/mw2m3am/a/140w-usb-c-power-adapter) | Adapter/cable recommendation; retrieved page did not expose an output-mode table. |

## Unresolved evidence

- Dell and Lenovo primary current-mode evidence now establishes the bounded laptop design target; exact Apple output modes need a unit label/trace. No OEM compatibility or private signaling implementation has been physically verified.
- Obtain exact charger/device/cable identifiers and original connection baselines. Label photographs plus OEM documentation and analyzer captures should establish the current and voltage actually in use.
- No connector or cable assembly has been qualified for the revised manufacturer-current rule and its margin. Generic 5 A parts remain unqualified for larger-current scenarios.
- No supply-chain price, inventory, or assembly quote is presented as verified. Cost tables are explicit planning allowances.
- No full current USB-C standard, OEM private schematic, physical-unit test, waveform capture, thermal image or calibration result is present. Manufacturer component datasheets were consulted for circuit capture. Model outputs and connection sheets are not bench evidence.

## Bench physical-design source additions

- [TI TPS7A43](https://www.ti.com/lit/ds/symlink/tps7a43.pdf): selected 85 V regulator, pin table, stability and DGQ land pattern. Supersedes S10 for U4.
- [GCT USB4115](https://gct.co/connector/usb4115), [USB4155](https://gct.co/connector/usb4155), [USB4105](https://gct.co/connector/usb4105): 48 V / 5 A ratings; **not 9 A**. Individual plug drawing retrieval was unsuccessful, so no mating-plug footprint is claimed.
- [Würth 691137710002](https://www.we-online.com/components/products/datasheet/691137710002.pdf): force-terminal ratings, pitch and drill.
- [Vishay SMBJ](https://www.vishay.com/docs/88392/smbj.pdf): clamp-coordination review; no TVS selected as universally protective.
- [Vishay WSK2512](https://www.vishay.com/docs/30108/wsk2512.pdf): 5 mΩ uses 1.19 mm termination variant; project pin mapping separates current and Kelvin pads.

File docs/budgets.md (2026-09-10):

# Budget method and limits

The [generated results](../analysis/results.md) and [input assumptions](../analysis/assumptions.json) are the numerical design record. Run `python tools/budgets.py` to reproduce them; `--check` verifies that committed outputs match the inputs. Python's standard library is sufficient.

The documented laptop-roster maximum is 8.5 A, setting a **9 A continuous design target / 10.8 A margin**. The sweep checks that target. A physical assembly rating and vendor compatibility remain unqualified.

## Low-power accuracy

The demanding point is low power at high voltage: at 28 V / 0.5 W, current is 17.857 mA and a 5 mΩ shunt produces only 89.286 µV. The 5 W transition requires a stricter relative error while its signal is ten times larger. This is why offset, noise, and calibration matter more than the nominal number of ADC bits.

The model uses a conservative arithmetic sum of terms, followed by the multiplicative voltage/current cross-term. It does not use root-sum-square statistics to make the budget smaller:

`E_power = (1 + E_current) × (1 + E_voltage) − 1 + bounded_output_burden / P × (1 + E_voltage)`

| Term | Treatment |
|---|---|
| Current gain after calibration | 0.10% allocated residual, including initial shunt/sensor/filter gain; not the nominal resistor tolerance |
| Voltage gain after calibration | 0.05% allocated residual |
| Sensor offset | Retain the factory maximum conservatively even though calibration is planned |
| Temperature | Allocate up to 25°C sensor change and 35°C shunt change from calibration; these need thermal evidence |
| Shunt TCR | Finished-part 35 ppm/°C for the provisional WSK2512 value |
| Gain drift, offset drift, common-mode and supply effects | Explicit terms from the sensor data; test endpoints do not eliminate these terms |
| Quantization | Half-LSB bounds using the revised wider ADC range |
| Noise | ±1 µV shunt allocation after one-second software averaging, plus a bus-voltage noise allocation |
| Thermal EMF / offset from layout | ±0.5 µV allocation, not a measured value |
| Residual layout gain | 0.05% current and 0.02% voltage allocations |
| Loading and leakage | Full bus-input load plus an additional 10 µA output-leakage allocation; pre-shunt electronics supply excluded in forward use |

Initial factory gain terms are not added again after they have been included in calibrated gain residuals. The model intentionally retains several factory offset and drift terms, so it does not assume perfect calibration. A sensitivity case retains an additional original shunt tolerance to show why unit calibration matters.

See [TI INA228](https://www.ti.com/lit/ds/symlink/ina228.pdf), particularly its electrical and noise tables, and [Vishay WSK2512](https://www.vishay.com/docs/30108/wsk2512.pdf). The noise table is typical characterization, not a system-level guarantee. The selected allocations must be demonstrated across units; a typical ENOB figure cannot certify our product.

## Timing

Normal logging: 540 µs per channel, two channels, 16 averages, giving nominal 17.280 ms sensor windows and about 57.87 fresh pairs/s. Software forms time-weighted one-second reports. The ±1 µV shunt-noise allocation applies to the final one-second result, not each pair. Correlated noise, drift and offsets do not automatically average away. Diagnostic precision remains 1052 µs per channel with 256 averages, or 538.624 ms. Adding temperature conversions changes cadence.

Bus voltage and current are converted sequentially. The budget covers settled DC, not instantaneous multiplication during a load edge or PD voltage transition. Changes within or between windows require characterization. Mark transition-contaminated records where detectable; simple settled endpoint agreement cannot rule out every in-window event. Do not claim guaranteed transient power accuracy from this sensor arrangement.

Reporting more often does not create new independent measurements. Every record needs its actual sample window, sequence number, and validity status. The raw trend stream uses a separately modeled ±3 µV noise allowance and does not meet the low-power precision target; the one-second aggregation allocation remains a hardware validation gate. See [energy-comparison.md](energy-comparison.md) for integration and timestamp rules.

## Loss and temperature

The captive-pigtail study targets **15 mΩ maximum added hot loop resistance**, including positive and return paths, relative to the same charger cable plugged directly into the device. The model allocates PCB copper, one additional mating interface, shunt, and a short pigtail separately. Contact resistance is an assumed procurement/qualification target; it is not a known part rating.

The revised study uses 75 mm of cable with 0.823 mm² copper per polarity, 1.5 mΩ PCB loop resistance, and a 3 mΩ extra mating-interface loop at the cold reference. Ordinary copper temperature scaling and a separate contact-aging/hot multiplier produce the study's hot estimate. Exact cable stranding, crimping, contacts, copper weights, vias, and terminations will replace these allocations.

Loss follows `P = I²R`. This predicts generated heat, **not temperature rise**. Do not convert watts into a claimed connector or enclosure temperature without a thermal model or measurements. The 8 mA inline electronics allowance adds 224 mW at 28 V, most of it in the regulator. It is outside the forward shunt reading but still affects the source and thermal budget.

The two-receptacle topology requires a new resistance model using the actual second cable. It cannot inherit the captive-pigtail result. A longer output cable also moves actual load voltage farther from the PCB measurement plane.

## What the calculations do not establish

- Physical current capacity, charging transparency, cable identity or 28 V overrange behavior. The numeric current target comes from the separate OEM roster.
- Actual noise tails, thermoelectric offsets, assembly variation, long-term drift, contact wear, and temperature-rise limits.
- Transient current fidelity, AC power accuracy, or dynamic energy accuracy with sequential voltage/current sampling.
- Fault clearing, TVS coordination, EMI/ESD performance, or USB signal integrity.
- A mains isolation category or an independent safety protection function.

The modeling gate passes only **conditional feasibility of the measurement budget and selected resistance allocations**. Hardware remains unqualified.

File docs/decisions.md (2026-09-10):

# Decisions and open questions

2026-09-10. “Provisional” means a design candidate; “open” means the outcome is deliberately uncommitted.

## D01 — Captive baseline selected for bench; final topology OPEN

| Consideration | Captive male output | Two inline receptacles |
|---|---|---|
| Added cable | Controlled short assembly | Second user-selected cable |
| Cable discovery | Preserve the original cable's behavior; do not add an unexamined marker | Two cable identities and their power paths must be reconciled |
| Orientation | Carry both relevant CC/VCONN contact paths through the added assembly | Active CC contacts on the two cables may land on different receptacle contacts |
| Resistance | One fewer mating interface than the two-cable arrangement | Additional contacts and cable contribute loss |
| Service | Replace complete pigtail or its internal termination | Replace an external cable |
| Present preference | First bench prototype | Retained if proven practical and economical |

TI describes the roles of CC orientation, Rp/Rd, Ra, and VCONN in its [Type-C primer](https://www.ti.com/lit/wp/slyy109b/slyy109b.pdf). **Engineering inference:** joining two standard C-to-C cables is more involved than extending the contacts of one plug. Fixed CC1-to-CC1 routing cannot be assumed to connect the active CC conductor through every two-cable orientation. Sharing a CC bus between two independent marked cables also needs a cable-discovery analysis; do not presume there is a transparent way to merge their responses.

Close D01 only after producing an orientation truth table, checking actual pigtail wiring, comparing source/sink/cable PD traces with a direct baseline, and finding a buildable connector assembly. No shorting CC1 to CC2 as a workaround. No new inline Rp/Rd/Ra networks or e-marker impersonation. If option B needs a PD proxy that replaces the original negotiation, it fails the transparency requirement rather than quietly redefining it.

## D02 — Laptop current ceiling: 9 A TARGET / 10.8 A DESIGN

The user excluded extreme proprietary phone charging. The [dated laptop roster](manufacturer-modes.md) includes Lenovo's documented C170 20 V / 8.5 A mode. Apply the accepted rule: 8.5 + 0.5 = 9 A continuous; ×1.20 = 10.8 A design margin. Do not confuse Dell's separate fault current-limit figure with a charging mode.

This closes the numeric target for this roster, not physical qualification or universal brand compatibility. The 5 mΩ / 1 W shunt remains the baseline; 12.5 A phone-derived sizing is excluded. No generic USB-C connector receives a 9 A rating through this decision.

## D03 — Overrange behavior: OPEN before final hardware

A transparent device does not get to tell the endpoints its 28 V/current limit. EPR includes higher voltages; see TI's [TPS26750 EPR support](https://www.ti.com/lit/ds/symlink/tps26750.pdf). The instrument may encounter a higher contract without having requested it.

Evaluate an independent analog disconnect for overvoltage/overcurrent/overtemperature against the loss, cost, and power-role implications. Alternatively, qualify a wider survival envelope and document controlled bench use. A software alert is not protection; a shunt fuse rating is not a precise current ceiling. A low-voltage TVS must not become a sustained crowbar on a legitimate higher-voltage contract. No arbitrary protection component values are frozen yet. R01 remains unchanged in either case.

## D04 — Measurement: PROVISIONAL

INA228 with one 5 mΩ four-terminal shunt on VBUS. Use the **±163.84 mV ADC range** after the current-rule change; the narrower range clips at about 8.2 A and does not cover the larger design scenarios. Direct raw conversion and per-unit calibration retain useful low-current margin without autoranging. The 1 W WSK2512 candidate must be thermally qualified at 9 A and the 10.8 A margin point. INA238 remains a cost-down comparison conditional on a new error budget. No low-side shunt: keep inline ground continuous.

## D05 — Isolation and supply: PROVISIONAL

PC-powered USB MCU; inline-powered sensor; isolate I²C between them with ISO1641. No supply conductor crosses the barrier, so a dedicated isolated DC/DC is not required. An isolated PC-fed sensor supply remains an alternative if inline self-consumption, reverse-power accounting, or sequencing proves troublesome. No USB isolator in the main charging/data path.

## D06 — Accuracy and bandwidth: PROVISIONAL

Use nominal 17.28 ms fresh acquisitions and one-second software averages for normal logging, as requested. Allocate ±1 µV shunt noise at the final one-second DC result; demonstrate this on hardware without assuming correlated errors average away. The 0.54 s mode remains a calibration/diagnostic option. Validate pulsed-load energy separately because voltage and current are sequentially sampled. Confirm ambient range and the PCB_B reference plane before release.

## D07 — Product scope: PROVISIONAL

No built-in PD decoder or trigger. A separate suitably rated analyzer is a development instrument for compatibility validation. Preserve low-frequency/DC charging signatures as well as digital messages; do not attach the MCU to inline D+/D−. The bench retains SBU and each high-speed contact's continuity without claiming USB 3/video performance. Include USB-C-to-other-connector OEM cables in the survey: a captive USB-C output cannot physically mate with a MagSafe end, so some assemblies may require placing the monitor at the charger side. Recheck reference-plane and self-consumption accounting in that placement.

## D08 — Minimum VBUS / low-voltage programmable modes: OPEN

The 5–28 V accuracy study is an engineering assumption, not a user-imposed 5 V minimum. If the qualified charger roster includes operation below 5 V, extend the accuracy and supply-startup study. The present 3.3 V inline LDO output cannot be assumed to remain regulated down to an equally low VBUS. Evaluate a lower sensor-side rail within INA228/isolator limits, a different supply, or isolated PC-fed sensing. Passive communications may continue while sensing is unavailable; that does not satisfy a promised measurement range. Close this before releasing the operating-voltage specification.

## D09 — Full bench prototype: SELECTED

Replace the standalone continuity coupon with an accessible board containing the passive inline path, INA228, isolated I²C, PC reporting USB, an onboard USB MCU, SWD/UART/I²C access, force terminals, Kelvin probe points, and a selectable floating sensor supply. Firmware can start with a current-limited supply/load before high-current USB assemblies are qualified. Production size and enclosure constraints do not apply to this board. See the [captured bench circuit and bring-up sequence](../hardware/bench-rev-a/README.md).

## D10 — Energy diagnostic and transport: SELECTED baseline

Report measured V/I, calculated W and Wh using frequent samples and one-second time-weighted reports over USB serial. The PC may bridge to MQTT or HTTP. Preserve boot identity, time mapping, gaps and calibration provenance. Compare wall and laptop-input energy over matching intervals, accounting for downstream cable loss, board consumption and wall-plug uncertainty. PCB_B energy must not be mislabeled laptop-terminal energy. See [energy-comparison.md](energy-comparison.md).

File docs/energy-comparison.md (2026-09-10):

# Measuring the upstream losses

The instrument will report measured voltage and current, calculated watts, and accumulated Wh. Frequent acquisitions feed one-second reports over timestamped USB serial; a PC logger can forward those same records to MQTT or HTTP. There is no network radio on the bench board.

## Define the boundary before subtracting energy

For a normal A-to-B setup, use the same interval [t0, t1] for every term:

`E_wall − E_laptop_input = E_charger_loss + E_cables_loss + E_board_loss`

This is the user's intended diagnostic. A difference large enough to resolve after uncertainty places the missing energy upstream of the laptop input. It does not separate charger loss from cable loss without further measurements. Use intervals long enough that changes in stored energy in the charger and measurement circuit are negligible, or include those boundary terms during startup/voltage changes.

The present board measures **PCB_B**, before the captive lead. Its uncorrected subtraction is:

`E_wall − E_pcb_b ≈ charger + upstream cable + board losses before PCB_B`

Consequently, `E_laptop_input = E_pcb_b − E_path_after_b`. The latter correction includes both positive and return conductor losses and contacts between the B sense pads and the laptop terminals. For a short captive assembly it can be characterized as the integral of `I² × R_path(T)`, with uncertainty for contact variation, temperature and load-dependent effects. Prefer a reference measurement at the actual laptop input for calibration. If the board must sit at the charger end of an OEM MagSafe/slim-tip cable, the entire downstream OEM cable is beyond PCB_B. Do not silently apply the short-pigtail correction there.

The shunt also sees the small B-side sensing burden. Include its measured/calibrated contribution or its uncertainty when translating the board reading to external load energy. The simple equations assume positive A-to-B operation; reverse or charger-side placement needs an explicit boundary diagram and accounting before using them.

| Quantity | How obtained | Reporting rule |
|---|---|---|
| `energy_pcb_b` | Calibrated sensor samples integrated by elapsed time | Primary measured-plane estimate |
| `energy_path_after_b` | Separate reference or qualified resistance model | Identify assembly, temperature assumption and correction uncertainty |
| `energy_laptop_input` | PCB_B energy less downstream path/burden corrections | Publish only when the correction is available; otherwise leave unavailable |
| Inline electronics energy | Characterize JP3 branch plus separate sense/leakage burdens | An 8 mA design allowance is not a measurement |
| PC/reporting energy | Measure full reporting-port current separately | Outside the inline shunt; do not hide it inside charger efficiency |

The board's upstream self-consumption and resistance losses already appear in wall-minus-PCB_B. **Do not subtract them twice.** Characterizing them lets us assign the difference among the board, charger and cable. Keep the reporting PC and unrelated equipment outside the wall meter's circuit, or meter their contribution separately. The same laptop acting as the PC host can also create an external ground path and alter the energy boundary.

## Frequent samples, one-second results

Normal `logging_1s` mode uses nominal 17.28 ms acquisition windows, about 57.87 fresh voltage/current pairs per second. Firmware timestamps conversion readiness with a monotonic timer and records its timing uncertainty. Polling/I²C/USB work must keep pace; reading the same conversion twice does not count as two samples.

Compute calibrated `p_i = v_i × i_i` for each valid pair. Report time-weighted mean V, mean I and mean P separately. **Mean P is not the product of one-second mean V and mean I.** Accumulate `E_Wh = integral(P dt) / 3600`, using real elapsed time rather than a nominal loop period. Preserve fractional energy in the accumulator so small increments do not round to zero.

Assign each pair an estimated acquisition midpoint from successive ready timestamps, retaining the observation interval and uncertainty. A proposed software integrator joins adjacent valid midpoint samples with linear power segments, splits segments at exact one-second boundaries, and emits a completed window once the next bracketing sample arrives. Integrate V and I similarly for their displayed means. Interpolation is a reconstruction assumption, not an additional measurement. Initial/final unbracketed portions and outages stay uncovered; do not extend a sample indefinitely.

On a missed acquisition, sensor reset, supply loss or communication fault, mark the affected interval incomplete. Do not fill it with zero power, silently carry stale readings forward, or claim complete session energy. Keep cumulative energy over covered time and cumulative uncovered time. For a partial second, report averages over covered time plus coverage; do not imply that partial mean describes a full second. Host packet loss is distinct from sensor loss: onboard totals can survive the former, but only while the MCU remains powered and acquiring.

The INA228 converts voltage and shunt sequentially and averages them internally. Software multiplication of the 16-sample means cannot recover their within-window covariance. Load pulses and PD voltage changes therefore need energy-reference testing; the settled DC error calculation does not guarantee dynamic energy accuracy. If this fails the diagnostic's uncertainty requirement, compare the calibrated on-chip energy accumulator or revise acquisition before claiming performance.

## Timestamp and interval contract

Records carry instrument ID, boot/session ID, sequence, monotonic window start/end, covered microseconds, sample count, calibration ID and quality flags. The host estimates a device-time-to-UTC mapping with repeated request/reply timestamps, retains round-trip bounds and clock drift, and stores receive time separately. Host arrival time alone is not the measurement timestamp. The wall plug's reporting latency, integration boundaries and cumulative-counter resolution need their own characterization.

Prefer differences in cumulative wall-energy counters at matched boundaries if the plug exposes them. If it only reports watts, retain each source timestamp and integrate according to its documented sampling semantics; occasional snapshots can miss pulses. Do not claim the plug's display precision as its measurement accuracy.

Compute the residual together with an uncertainty interval. A conservative bound is:

`u_residual ≤ u_wall + u_board_energy + u_downstream_correction + u_time_alignment`

Use uncertainty quantities in Wh with consistent coverage/definitions. Add calibration bias, counter quantization, clock-scale error, start/end alignment and gap handling explicitly. Root-sum-square is appropriate only where statistical independence and uncertainty type are justified. Longer intervals reduce the relative impact of quantization and uncertain boundaries; they do not remove calibration bias or missing samples. If the residual is no larger than its uncertainty, the location of the missing watts remains unresolved.

## Validation cases

Use a steady reference load, a two-level pulsed load and a controlled voltage transition, then compare energy over identical intervals. Include the 0.5 W and 5 W regions, clock drift, one-second boundary crossings, dropped host records, sensor outages and reconnects. Characterize JP3 current at 5/9/15/20/28 V with idle and active I²C and after warm-up. Validate the downstream resistance correction cold/hot and after mating/flex cycles. Record actual wall-plug specifications before assigning a numerical combined energy-accuracy claim.

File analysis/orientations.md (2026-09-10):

# CC orientation connectivity

Generated by `python tools/orientations.py`. Contact mapping only; no PD, VCONN supply, e-marker, or analog simulation.

| Cable flip a | Endpoint / second-cable flip b | Active J_A CC | Captive endpoint CC | Fixed F-F CC path | Crossed F-F CC path |
|---|---|---|---|---|---|
| 0 | 0 | CC1 | CC1 | yes | NO |
| 0 | 1 | CC1 | CC2 | NO | yes |
| 1 | 0 | CC2 | CC2 | NO | yes |
| 1 | 1 | CC2 | CC1 | yes | NO |

An F-F CC path does not establish cable-identity or VCONN correctness. Each fixed F-F map fails two local orientations. The captive extension keeps both contacts separate in all four cases.

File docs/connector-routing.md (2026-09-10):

# Connector routing for bench revision A

## Decision

Use **one inline receptacle and a short custom captive male assembly** as the bench baseline. Keep the two-receptacle outcome open for a later proven topology. A fixed passive two-receptacle board with two ordinary C-to-C cables fails the independent-orientation requirement; it is not an interchangeable assembly option for this revision.

This resolves the logical baseline, not procurement or USB qualification. The pigtail needs two independent CC-contact conductors, no new marker, and no local CC terminations. An ordinary cut C-to-C cable is not a substitute: its VCONN contacts and marker circuitry need not form the required contact extension.

Contact functions and orientation are documented in [TI's Type-C primer, figures 13–14](https://www.ti.com/lit/wp/slyy109b/slyy109b.pdf). The map and conclusions below are our circuit analysis. No current USB-IF extension-cable compliance claim is made.

## Contact map

`J_A` is the inline receptacle; `P_B` the captive plug. Names are connector contact designations, **not mirrored solder-pad coordinates**. Verify mating-face drawings before assigning PCB pads.

| J_A contacts | Path | P_B contacts |
|---|---|---|
| A4, A9, B4, B9 | VBUS_A → four-terminal shunt → VBUS_B; parallel power contacts | A4, A9, B4, B9 |
| A1, A12, B1, B12 | Continuous low-resistance inline ground | A1, A12, B1, B12 |
| A5 / CC1 | Independent `CONTACT_A5` | A5 |
| B5 / CC2 | Independent `CONTACT_B5` | B5 |
| A6 and B6 | Join locally at receptacle; `INLINE_DP` | A6 / D+ |
| A7 and B7 | Join locally at receptacle; `INLINE_DM` | A7 / D− |
| A8 / SBU1 | Separate conductor | A8 |
| B8 / SBU2 | Separate conductor | B8 |
| A2, A3 | Preserve each contact as a pair | A2, A3 |
| A10, A11 | Preserve each contact as a pair | A10, A11 |
| B2, B3 | Preserve each contact as a pair | B2, B3 |
| B10, B11 | Preserve each contact as a pair | B10, B11 |
| Shell | Inline shield; separate from PC shell | Shell |

A normal plug has one USB 2.0 pair; P_B B6/B7 are not extra signal wires. Document any proposed nonstandard assembly before substituting it. Retaining the four SuperSpeed pairs preserves contact continuity; USB 3.x, video, and USB4 signal integrity are not promised. Route USB 2.0 at 90 Ω differential and keep observation pads small.

Neither `CONTACT_A5` nor `CONTACT_B5` has a permanently assigned CC-versus-VCONN role: original-cable orientation can exchange them. Route both for VCONN current and PD signaling. Do not connect them together, to VBUS, to an MCU, or to new Rp/Rd/Ra resistors. Do not add an e-marker. Original cable electronics and DC-coupled D+/D− signatures remain in circuit.

## Orientation analysis

Let `a` be the original cable plug's flip at J_A, and `b` the captive plug's flip at the endpoint. The active CC reaches endpoint CC1 if `a XOR b = 0`, otherwise CC2. The other contact remains separate; both endpoint CC positions are legitimate attachment orientations.

| a | b | Active J_A | Active endpoint | Other contact |
|---|---|---|---|---|
| 0 | 0 | CC1 | CC1 | Separate |
| 0 | 1 | CC1 | CC2 | Separate |
| 1 | 0 | CC2 | CC2 | Separate |
| 1 | 1 | CC2 | CC1 | Separate |

A detachable source-end plug adds another independent flip: eight physical combinations for a detachable C-to-C cable plus extension; four for a fixed charger lead. At charger-side placement, interchange endpoint roles and repeat VCONN-source and power-role checks. This proves connectivity only, not attach thresholds, marker power paths, cable discovery, or proprietary behavior.

For fixed F-F CC1→CC1 and CC2→CC2 wiring, both ordinary cable plugs must land their longitudinal CC conductors on the same contact. Two of four local flip combinations fail. A crossed map exchanges the failures. Manually switching them does not solve duplicated marked-cable identities or VCONN paths. No automatic mux or PD proxy is silently inserted.

The reproducible [orientation model](../analysis/orientations.md) enumerates the cases. It is not a USB-PD simulator.
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

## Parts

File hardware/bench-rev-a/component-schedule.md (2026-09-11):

# Bench component schedule

**Exported from the canonical native KiCad schematic. Draft, not an orderable BOM.**
The group column is a functional placement group, not a separate schematic sheet.

| Reference | Value / candidate | Domain | Group |
|---|---|---|---|
| C1 | 100nF 100V differential | INLINE | 02-sensing |
| C2 | 10nF 100V X7R | INLINE | 02-sensing |
| C3 | 100nF 10V at U1 | INLINE | 02-sensing |
| C4 | 100nF 10V at U2.8 | INLINE | 02-sensing |
| C5 | 100nF 10V at U2.1 | PC | 02-sensing |
| C6 | 1uF 100V X7R | INLINE | 03-supplies |
| C7 | 2u2 10V X7R | INLINE | 03-supplies |
| C8 | 1uF 10V | PC | 03-supplies |
| C9 | 4u7 10V | PC | 03-supplies |
| C10 | 1uF 10V at connector | PC | 03-supplies |
| C11 | 100nF 10V at U3.24 | PC | 04-usb-mcu |
| C12 | 100nF 10V at U3.48 | PC | 04-usb-mcu |
| C13 | 100nF 10V at U3.36 | PC | 04-usb-mcu |
| C14 | 100nF 10V at U3.1 | PC | 04-usb-mcu |
| C15 | 100nF 10V at U3.9 | PC | 04-usb-mcu |
| C16 | 1uF 10V | PC | 04-usb-mcu |
| C17 | 100nF reset | PC | 05-debug |
| C18 | 100nF 10V at U7.1 | PC | 03-supplies |
| C19 | 1uF 10V at U7.6 | PC | 03-supplies |
| C20 | 22uF 50V X7R MID | INLINE | 03-supplies |
| C21 | 22uF 50V X7R MID | INLINE | 03-supplies |
| D1 | Activity LED | PC | 05-debug |
| J1 | USB4115-03-C / USB path 5A MAX | INLINE | 01-inline |
| J2 | 691137710002 / force terminal | INLINE | 01-inline |
| J3 | 691137710002 / force terminal | INLINE | 01-inline |
| J4 | Kelvin probe pads; NOT force pins | INLINE | 01-inline |
| J5 | PC I2C / external MCU | PC | 02-sensing |
| J6 | INLINE I2C debug | INLINE | 02-sensing |
| J7 | Floating external 3.3V | INLINE | 03-supplies |
| J8 | USB4105-GF-A-120 / reporting | PC | 04-usb-mcu |
| J9 | Cortex SWD 2x5 1.27mm | PC | 05-debug |
| J10 | UART 3.3V logic | PC | 05-debug |
| J11 | Spare GPIO / SPI | PC | 05-debug |
| JP1 | SENSOR SUPPLY: one shunt only | INLINE | 03-supplies |
| JP2 | PC supply current link | PC | 03-supplies |
| JP3 | INLINE self-current link | INLINE | 03-supplies |
| JP4 | External-master enable; DNF | PC | 03-supplies |
| P1 | Captive harness solder termination | INLINE | 01-inline |
| R1 | WSK25125L000DEA / 5mR 1W | INLINE | 01-inline |
| R2 | 0R shield bond | INLINE | 01-inline |
| R3 | 10R 0.1% matched | INLINE | 02-sensing |
| R4 | 10R 0.1% matched | INLINE | 02-sensing |
| R5 | 100R | INLINE | 02-sensing |
| R6 | 2k2 pull-up | PC | 02-sensing |
| R7 | 2k2 pull-up | PC | 02-sensing |
| R8 | 2k2 pull-up | INLINE | 02-sensing |
| R9 | 2k2 pull-up | INLINE | 02-sensing |
| R10 | 10R 0.25W branch feed | INLINE | 03-supplies |
| R13 | 5k1 1% Rd | PC | 04-usb-mcu |
| R14 | 5k1 1% Rd | PC | 04-usb-mcu |
| R15 | 0R tuning footprint | PC | 04-usb-mcu |
| R16 | 0R tuning footprint | PC | 04-usb-mcu |
| R17 | 10R VDDA filter | PC | 04-usb-mcu |
| R18 | 100k 1% | PC | 04-usb-mcu |
| R19 | 100k 1% | PC | 04-usb-mcu |
| R20 | 0R PC shell bond | PC | 04-usb-mcu |
| R21 | 10k reset pull-up | PC | 05-debug |
| R22 | 10k boot pull-down | PC | 05-debug |
| R23 | 10k button pull-up | PC | 05-debug |
| R24 | 1k LED limiter | PC | 05-debug |
| R25 | 100k enable pull-down | PC | 03-supplies |
| R26 | 10k override limiter | PC | 03-supplies |
| SW1 | RESET pushbutton | PC | 05-debug |
| SW2 | BOOT pushbutton | PC | 05-debug |
| SW3 | USER pushbutton | PC | 05-debug |
| TP1 | VBUS_A | INLINE | 01-inline |
| TP2 | VBUS_B | INLINE | 01-inline |
| TP3 | GND_INLINE | INLINE | 01-inline |
| TP4 | CONTACT_A5 | INLINE | 01-inline |
| TP5 | CONTACT_B5 | INLINE | 01-inline |
| TP6 | INLINE_DP | INLINE | 01-inline |
| TP7 | INLINE_DM | INLINE | 01-inline |
| TP8 | CONTACT_A8 | INLINE | 01-inline |
| TP9 | CONTACT_B8 | INLINE | 01-inline |
| TP10 | ALERT: floating scope only | INLINE | 02-sensing |
| U1 | INA228AIDGSR | INLINE | 02-sensing |
| U2 | ISO1641BD | BARRIER | 02-sensing |
| U3 | STM32F072CBT6 / 128K flash | PC | 04-usb-mcu |
| U4 | TPS7A4333DGQR | INLINE | 03-supplies |
| U5 | TLV75533PDBVR | PC | 03-supplies |
| U6 | USBLC6-2SC6 | PC | 04-usb-mcu |
| U7 | TPS22919DCKR | PC | 03-supplies |

## Assembly notes

- **J1:** 24 contacts, 48 V / 5 A manufacturer rating. This bench population is limited to 5 A via USB; a 9 A assembly remains a procurement gate.
- **J2:** Wurth 16 A UL / 24 A VDE, 5.00 mm pitch, 1.30 mm drills. Force path capacity still requires PCB thermal testing.
- **J3:** Wurth 16 A UL / 24 A VDE, 5.00 mm pitch, 1.30 mm drills. Force path capacity still requires PCB thermal testing.
- **J4:** Use small pads near the defined B-plane. No main current through this header.
- **J5:** 3V3 is switched reference/output. Hold onboard MCU in reset and fit JP4 for another open-drain master; no external pull-ups to an always-on rail.
- **J6:** Only a floating or isolated instrument here; never jumper to J5.
- **J7:** For zero-VBUS/low-voltage bench testing; not connected to PC supply.
- **J8:** Long board edge. USB 2.0 receptacle may omit unused SS/SBU contacts after exact footprint selection.
- **J9:** Key pin 7 absent. No SWO on Cortex-M0. Debug probe must not power this board.
- **J10:** TX/RX named from board viewpoint; 3V3 reference only. Not RS-232 voltage levels.
- **JP1:** Normal 1-2; floating external 3.3 V 2-3. Do not install two shunts.
- **JP2:** Fit shunt normally. Remove to measure reporting-domain supply current; no external power injection.
- **JP3:** Fit shunt normally; insert a floating ammeter to characterize sensor-side self-consumption. Not a main-current connection.
- **JP4:** Fit only for external-master bench use with U3 held reset; remove for USB suspend testing.
- **P1:** Board-side termination, not a USB mating footprint. Candidate USB4155-03-C plug is 48 V / 5 A only; custom harness drawing/qualification remains open.
- **R1:** Project pad numbering 1=I1, 2=I2, 3=E1, 4=E2. 5 mOhm uses T=1.19 mm termination variant; current pads and Kelvin pads mapped from Vishay drawing.
- **TP10:** No pull-up fitted; open drain requires a local pull-up if probing logic. Firmware polls status.
- **U1:** Address 0x40. Wide ADC range. Footprint candidate still requires package drawing review.
- **U2:** Side 1 PC, side 2 inline. SCL is unidirectional; INA228 does not require clock stretching.
- **U3:** Pinout checked against ST DS9826 Rev 6 figure 8. 16 KB RAM. HSI48/CRS USB clock.
- **U4:** 85 V fixed 3.3 V regulator. EN intentionally floating per internal pull-up; never tie EN to high VBUS. MID selected 15 V, with capacitors sized >=3x total OUT capacitance.
- **U6:** Route lines through paired pads with short ground return. PC port only.
- **U7:** Switch U2 side 1 and its pull-ups off in USB suspend. Set PB6/PB7 high impedance first. QOD tied to output.

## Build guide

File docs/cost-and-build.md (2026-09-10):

# Cost and build plan

These are rounded engineering allowances for a small bench batch, **not supplier quotes or verified stock prices**. Custom cable tooling/minimum orders and the unresolved fault circuit can dominate cost.

| Block | Bench candidate | Allowance per board, USD |
|---|---|---|
| Sensor | INA228 | 3.50–7.00 |
| Shunt | Four-terminal WSK2512, 5 mΩ | 1.00–3.00 |
| Isolation | ISO1641 | 2.00–4.00 |
| USB MCU | STM32F072CBT6 | 2.00–5.00 |
| Two local supplies | TPS7A43 / TLV75533 (allowance needs requote) | 1.50–4.00 |
| Isolator supply switch | TPS22919 | 0.20–1.00 |
| Reporting receptacle | USB-C, USB 2.0 | 0.50–1.50 |
| Inline connector and pigtail | Assembly not sourced/qualified | 3.00–12.00 |
| Force/debug connectors and controls | Terminals, SWD, UART, GPIO, jumpers, buttons | 4.00–12.00 |
| ESD and passives | Final packages pending | 2.00–5.00 |
| PCB share | Accessible four-layer bench board | 6.00–15.00 |
| Assembly/rework share | Small prototype batch | 8.00–30.00 |
| Base/strain relief | Simple printed base and hardware | 2.00–6.00 |
| Fault-circuit allowance | Architecture open | 2.00–8.00 |
| **Rounded planning total** | **Conditional on suitable assemblies** | **38–114** |

Exclude shipping, taxes, engineering and calibration labor, reference equipment, analyzer/debug probe, and custom cable tooling. No promise is made that a qualified high-current assembly is available in single quantities within its allowance. Obtain quotes after the component schedule becomes an orderable BOM.

Use one precision shunt path and independent local supplies with isolated I²C. Spend on contacts, Kelvin routing and calibration. The F072's flash/RAM and exposed debug access support firmware iteration. Miniaturize and consider a cheaper sensor only after noise, thermal and energy behavior are measured.

## Work sequence

| Milestone | Deliverable | Completion gate |
|---|---|---|
| M0 — definition | Laptop roster, current rule, logical contact map and budgets | Checkpointed; physical compatibility remains open |
| M1 — bench capture | Complete sensing/MCU/debug circuit, connector specification and firmware contract | Native ERC clean; selected 5 A USB bench population; 9 A assembly sourcing remains open |
| M2 — bench PCB and firmware | Accessible board, INA228 driver, serial logger and calibration workflow | Low-voltage force-input bring-up; one-second/Wh behavior verified |
| M3 — measurement and assemblies | Noise/accuracy/energy results, qualified captive hardware | DC targets and declared dynamic limits supported; added loss and current tested |
| M4 — qualification | Protection, OEM orientations, USB and isolation records | Declared rating and compatibility backed by evidence |
| M5 — practical build | Tagged source, BOM and manufacturing package | Reproducible, reviewed fabrication release linked prominently in README |

The tiny continuity-board milestone is replaced by the full bench prototype. Connector tests and firmware work proceed on that platform; no production enclosure constraint applies yet. Checkpoint each meaningful change and retain previous designs in git history.

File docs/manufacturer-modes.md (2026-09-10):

# Laptop charging envelope

2026-09-10. The user narrowed the scope to practical laptop charging after the phone survey exposed a 12 A mode. **Extreme proprietary phone charging is excluded.** Apple, Dell, and Lenovo laptop setups drive this revision.

## Selected electrical target

**28 V nominal maximum, 9 A continuous design target, 10.8 A current qualification margin.** Voltage component margin remains at least 33.6 V. These are instrument requirements; no connector assembly or built instrument has been qualified yet.

The highest documented mode in this laptop roster is 8.5 A: 8.5 + 0.5 = 9 A; 9 × 1.20 = 10.8 A. At 28 V the rectangular instrument envelope is 252 W. That does not imply an OEM offers 28 V / 9 A. Source tolerance and transients need separate treatment.

## Primary evidence

| Setup | Documented output / evidence | Cable and placement consequence |
|---|---|---|
| Apple 140 W USB-C, MW2M3AM/A | [Apple](https://www.apple.com/shop/product/mw2m3am/a/140w-usb-c-power-adapter) specifies 140 W and recommends MagSafe 3 or a 240 W C-to-C cable. The retrieved page does **not** give its voltage/current table; obtain the actual unit label and PD trace. | Preserve the original cable. Insert at the charger for MagSafe; either end is physically possible for C-to-C. Do not infer proprietary current from watts alone. |
| Dell 165 W USB-C GaN, 450-BFTY, China listing | [Dell output table](https://www.dell.com/zh-cn/shop/-165w-usb-c-gan-/apd/450-bfty/): 28 V / 5.893 A, 20 V / 6.5 A, and 5/9/15 V / 3 A. Its separate <10.5 A current-limit entry is **not** a continuous charging mode. | Retain the original output assembly and negotiation; test charger identification and both higher-current modes with a listed compatible laptop. |
| Lenovo Legion Slim 140 W USB-C, GX21M50625 | [Lenovo product page](https://www.lenovo.com/us/en/p/accessories-and-software/chargers-and-batteries/chargers/gx21m50625), embedded product specification: 20.0 V / 7.0 A; 19.95 V / 5 A; 5/9/15 V / 3 A. Verified from the publicly returned HTML; the text-only page omits the field. | Include a matching Legion laptop and its original output assembly. |
| Lenovo C170 / LA170, Black Myth edition, product 1047372 | [Official Lenovo description](https://www.lenovo.com.cn/wiki/product-doc-46691.html), linked to the [official SKU](https://item.lenovo.com.cn/product/1047372.html): 20 V / 8.5 A maximum, also 20 V / 7 A; matching C-Slim cable contains an E-Mark chip. | Monitor the USB-C **charger end** of the C-to-Slim path. Verify the regional adapter label, AC-input-dependent limits, and exact cable before powered qualification. |

This is a dated, bounded design roster, not an exhaustive guarantee for every product under these brands. The C170 entry is a published maximum, not evidence of continuous laptop draw; the monitor is deliberately sized continuously above it. Physical labels, cable identities, and traces remain acceptance evidence.

## Scope interpretation

- The researched 12 A phone mode no longer drives this design. The excluded phone-current calculations remain in git history.
- Exclude demonstrations, battery-side currents, total multiport wattage, and ordinary barrel/slim-tip adapters whose path contains no USB-C connection.
- Include standards-based laptop PD and the documented Dell/Lenovo modes above. Add exact charger/cable/device entries before extending coverage.
- A USB-C-to-Slim cable still carries its input current through the USB-C source connector. This differs from a fixed slim-tip adapter with no USB-C connection.
- Brand compatibility is a test result; contact continuity alone does not prove authentication, EPR entry, cable identity, or full charging power.

## Bench evidence

Photograph output labels and cable markings; record device and region; compare direct and inserted source capabilities, accepted contracts, cable-discovery responses, charger identification, attained power under equivalent load/battery conditions, orientations, voltage drop, and temperatures. Save captures against the hardware revision. Do not force OEM modes with a substitute trigger.

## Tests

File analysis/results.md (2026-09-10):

# Calculated budgets

Generated by `python tools/budgets.py` from `analysis/assumptions.json`.

**Provisional allocations, not measured performance.** See [method and limitations](../docs/budgets.md).

Current rule: verified OEM maximum + 0.5 A, followed by 20% design margin. **The documented laptop-roster maximum is 8.5 A. The selected continuous design target is 9 A; hardware qualification is pending.**

## One-second logging DC error allocation

| Voltage | Power | Current | Shunt signal | Calculated error bound | Target |
|---|---|---|---|---|---|
| 5 V | 0.5 W | 100.000 mA | 500.000 µV | 1.310% | 5% |
| 5 V | 1 W | 200.000 mA | 1000.000 µV | 0.914% | 5% |
| 5 V | 5 W | 1000.000 mA | 5000.000 µV | 0.598% | 1% |
| 5 V | 45 W | 9000.000 mA | 45000.000 µV | 0.528% | 1% |
| 9 V | 0.5 W | 55.556 mA | 277.778 µV | 1.894% | 5% |
| 9 V | 1 W | 111.111 mA | 555.556 µV | 1.192% | 5% |
| 9 V | 5 W | 555.556 mA | 2777.778 µV | 0.631% | 1% |
| 9 V | 81 W | 9000.000 mA | 45000.000 µV | 0.499% | 1% |
| 15 V | 0.5 W | 33.333 mA | 166.667 µV | 2.765% | 5% |
| 15 V | 1 W | 66.667 mA | 333.333 µV | 1.621% | 5% |
| 15 V | 5 W | 333.333 mA | 1666.667 µV | 0.706% | 1% |
| 15 V | 135 W | 9000.000 mA | 45000.000 µV | 0.485% | 1% |
| 20 V | 0.5 W | 25.000 mA | 125.000 µV | 3.468% | 5% |
| 20 V | 1 W | 50.000 mA | 250.000 µV | 1.970% | 5% |
| 20 V | 5 W | 250.000 mA | 1250.000 µV | 0.771% | 1% |
| 20 V | 180 W | 9000.000 mA | 45000.000 µV | 0.480% | 1% |
| 28 V | 0.5 W | 17.857 mA | 89.286 µV | 4.539% | 5% |
| 28 V | 1 W | 35.714 mA | 178.571 µV | 2.503% | 5% |
| 28 V | 5 W | 178.571 mA | 892.857 µV | 0.874% | 1% |
| 28 V | 252 W | 9000.000 mA | 45000.000 µV | 0.475% | 1% |

The sweep evaluates 19,635 points. Largest precision allocation at ≥5 W: **0.874%** (28 V, 5 W). Below 5 W: **4.539%** (28 V, 0.5 W).

## Timing and noise

| Mode | Sensor window | Fresh updates | Report window | Noise allocation |
|---|---|---|---|---|
| precision | 538.624 ms | 1.86/s | 0.538624 s | ±1 µV |
| trend | 17.280 ms | 57.87/s | 0.01728 s | ±3 µV |
| logging_1s | 17.280 ms | 57.87/s | 1 s | ±1 µV |

Trend-mode allocation at 28 V / 0.5 W: **6.782%**; it does not meet the low-power precision target.

Logging mode uses frequent 17.28 ms sensor windows and one-second software aggregation. Its ±1 µV noise allocation applies to the final one-second average and requires bench validation; do not assume correlated errors average away. The older precision mode remains a calibration/diagnostic option. These DC budgets do not bound transient energy error.

## Added resistance and losses: captive-pigtail candidate

| Current | Shunt drop | Shunt heat | Hot added loop | Hot added drop | Hot passive loss |
|---|---|---|---|---|---|
| 5 A | 25.00 mV | 0.1250 W | 14.879 mΩ | 74.40 mV | 0.372 W |
| 9 A | 45.00 mV | 0.4050 W | 14.879 mΩ | 133.91 mV | 1.205 W |
| 10.8 A | 54.00 mV | 0.5832 W | 14.879 mΩ | 160.69 mV | 1.736 W |

These are sizing scenarios, not qualified cable ratings or instructions to overload generic USB connectors.

Inline supply allocation at 28 V: **0.224 W**, including about 0.198 W in the linear regulator. Add this to passive losses when estimating total heat; it is excluded from the forward shunt reading.

## Manufacturer-current rule sensitivity

| Hypothetical OEM max | Hypothetical rating | Design current | Shunt heat at design current | Within 75% of 1 W allocation? |
|---|---|---|---|---|
| 6.5 A | 7 A | 8.4 A | 0.355 W | Yes |
| 7 A | 7.5 A | 9 A | 0.408 W | Yes |
| 8.5 A | 9 A | 10.8 A | 0.587 W | Yes |

The 75% allocation is an engineering derating target assuming the resistor remains within its 70°C full-power condition. It does not replace thermal qualification.

## Range and calibration sensitivity

- ADC current range with 5 mΩ: ±32.768 A nominal, ±32.565 A at the modeled high resistance.
- Retaining an additional 0.5% shunt tolerance raises the 28 V / 5 W allocation to 1.375%; per-unit calibration is a real requirement.
- Connector qualification, thermal gradients, transient response, and long-term drift remain outside this calculator.

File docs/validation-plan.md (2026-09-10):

# Prototype and validation plan

No physical tests have been run. Keep every result tied to board revision, firmware revision, calibration ID, cable IDs, fixtures, and ambient conditions.

## Stage 0 — Close the requirements that drive hardware

| Gate | Work | Evidence to close |
|---|---|---|
| G0.1 | Numeric laptop target closed: 8.5 + 0.5 = 9 A; ×1.20 = 10.8 A | Primary roster documented; actual unit labels and physical capacity still require checks |
| G0.2 | Compare captive male and two-receptacle topology | Pin/contact map, orientation table, marker/VCONN analysis, purchasable assembly |
| G0.3 | Define overvoltage, overcurrent, and hot-connector response | Concrete protection/survival architecture and component coordination |
| G0.4 | Fix accuracy plane, ambient range, and timing | Clear calibration and acceptance limits; cable loss explicitly assigned |
| G0.5 | Establish minimum VBUS and programmable charging coverage | Regulator/sensor operation and accuracy at the required low-voltage endpoint |

## Stage 1 — Integrated bench board and transparent path

Use the [full bench A circuit](../hardware/bench-rev-a/README.md), including MCU, isolated sensor, force terminals and debug headers. Review native schematic/footprints/ERC before PCB release. Develop firmware with floating sensor power and current-limited force wiring while connector sourcing proceeds. Verify all contact wiring with power absent, then use qualified assemblies for USB/OEM tests.

Capture a direct charger/cable/device baseline, then insert the bench monitor. An external PD analyzer must be rated for the voltage/current under test; older reference analyzers are not automatically suitable. Do not add a trigger board that negotiates in place of the device.

| Test family | Cases | Acceptance |
|---|---|---|
| Orientation | Every independently reversible plug at every receptacle; label each position | Same usable power modes and required data operation as baseline |
| Cable identification | Unmarked low-current cable, appropriate marked cable, EPR cable, OEM-specific cable | Expected identities/responses preserved; no false increase in cable capability |
| Startup | PC before/after power, source before/after sink, dead-battery device | No new attach failure or unintended VBUS source |
| PD behavior | Discovery, contract selection, reset, detach; supported power and VCONN swaps | No altered identity or contract, no introduced persistent failures |
| OEM charging | Exact Apple/Dell/Lenovo and other qualified roster combinations | Original intended charger identification and charging mode retained |
| USB 2.0 | Low/full/high-speed devices as relevant; bulk transfer integrity | Enumeration and transfers comparable to baseline at tested lengths |
| D+/D− charging signatures | Relevant legacy/proprietary charging sources | Analog signatures and successful charging behavior preserved |
| Alternate cable ends | OEM USB-C-to-MagSafe or other power cables, if in roster | Correct physical placement; no unsupported adapter chain |
| Reporting | PC connect/disconnect, MCU reset, USB suspend/resume | Normal inline charging/data continue; logging state changes are explicit |

For a C-to-C source cable plus captive plug there can be three independently reversible mating locations; test all eight binary combinations when each is independently accessible. Two separate C-to-C cables can create four locations and up to sixteen combinations. Derive the actual fixture matrix rather than testing only one “flipped” state. A topology that works only in some orientations does not close G0.2.

## Stage 2 — Sensing core and calibration

Evaluate the same board through J2/J3 current-limited force connections while connector work proceeds; keep USB power paths disconnected during independent injection. Use Kelvin references at the declared B-side plane. Select reference equipment with a combined uncertainty small enough to resolve the target; aim for ≤0.2% reference power uncertainty for the 1% acceptance region. Record actual equipment specifications and ranges.

1. Inspect soldering and sense routing; verify no reporting-to-inline conductive path. Check the main return is continuous and the PC port cannot backfeed VBUS.
2. Verify regulator startup, no-input state, sensor ID, I²C levels, and PC enumeration. Test each domain powered alone; “input unavailable” must not be reported as a valid zero-watt reading.
3. Warm the instrument and calibrate voltage at 5 V and 28 V. Fit and store offset/gain with reference readings.
4. Establish current offset with the external output genuinely open at multiple VBUS values. Account for meter input/protection leakage. Never silently tare while a real load is attached.
5. Calibrate current at low and high reference levels; verify intermediate points rather than fitting every acceptance point. Include both signs if signed operation is released.
6. Verify 0.5 W, 1 W, just below 5 W, exactly 5 W, intermediate load, and rated current at 5/9/15/20/28 V. Do not demand rated power at a lower voltage if it exceeds rated current.
7. Repeat at proposed ambient extremes and after high-current warm-up. Record shunt, sensor, regulator, contact, and enclosure temperatures independently; sensor die temperature is not contact temperature.

Acceptance uses absolute error relative to the reference: ≤1% at ≥5 W; ≤5% from 0.5 W to below 5 W, for settled one-second logging records within the qualified envelope. Guardband for reference uncertainty. Characterize a population of units before turning a design allocation into a guaranteed specification.

## Stage 3 — Current, thermal, and fault qualification

Use connectors/fixtures qualified for the intended test current. Increase current in controlled steps while monitoring each power-contact region. Test normal rated current continuously to thermal equilibrium at the proposed upper ambient. Suggested equilibrium definition: less than 1°C change over ten minutes; extend the run if conditions are still drifting. Record actual criteria rather than claiming a fixed soak time always suffices.

Verify the additional hot loop resistance against the selected topology budget. For the present captive scenario the target is 15 mΩ. Retest after mating cycles and cable flexing. Establish acceptance limits from connector, wire, PCB, resistor, and enclosure specifications, including touch temperature and solder-joint limits.

The 20% current point is a **design-capacity qualification gate**, with duration and component derating set explicitly. A short survival pulse does not establish continuous margin. Fault testing must verify the chosen hardware response with the PC disconnected and MCU stalled. Do not test an unqualified generic USB cable above its rating.

## Stage 4 — Isolation, reporting, and energy

- Check barrier continuity with every shield, enclosure fastener, debug lead, and PC connector installed. Set working/withstand tests after the final insulation geometry and parts are chosen.
- Test USB suspend, reconnect, dropped records, application exit, sensor NACK, and MCU reset. No backfeed or silent energy accumulation across missing intervals.
- Compare steady and pulsed-load energy against a calibrated reference over matched intervals. Test boundary crossings and voltage transitions; characterize sequential-sampling and internal-averaging error.
- Verify approximately 58 fresh pairs/s, one-second time-weighted V/I/P reports, mean-of-products power, fractional Wh integration, complete/partial coverage and signed reversals.
- Measure JP3 self-consumption over voltage/activity/temperature. Use full reporting-port current for PC-domain accounting and suspend validation; JP2 alone excludes front-end loads.
- Verify any downstream cable correction with actual cold/hot assembly resistance and a terminal-level reference. Include the wall plug's energy quantization, sampling behavior and timestamp uncertainty.
- Keep firmware elapsed time independent of host scheduling. Confirm the timebase and timestamp uncertainty. Wh logging and matched-interval comparison are required; no separate numerical dynamic-energy guarantee is yet established.

Follow the [energy accounting and uncertainty method](energy-comparison.md); no subtraction result is conclusive unless it exceeds the combined uncertainty.

## Release conditions

All Stage 0 gates closed; schematics and layout reviewed; reproducible build artifacts; calibration method and compatibility roster published; power/thermal/isolation results attached. Only then label a hardware revision orderable. There are currently no Gerbers, manufacturing files, or purchase-ready BOM.

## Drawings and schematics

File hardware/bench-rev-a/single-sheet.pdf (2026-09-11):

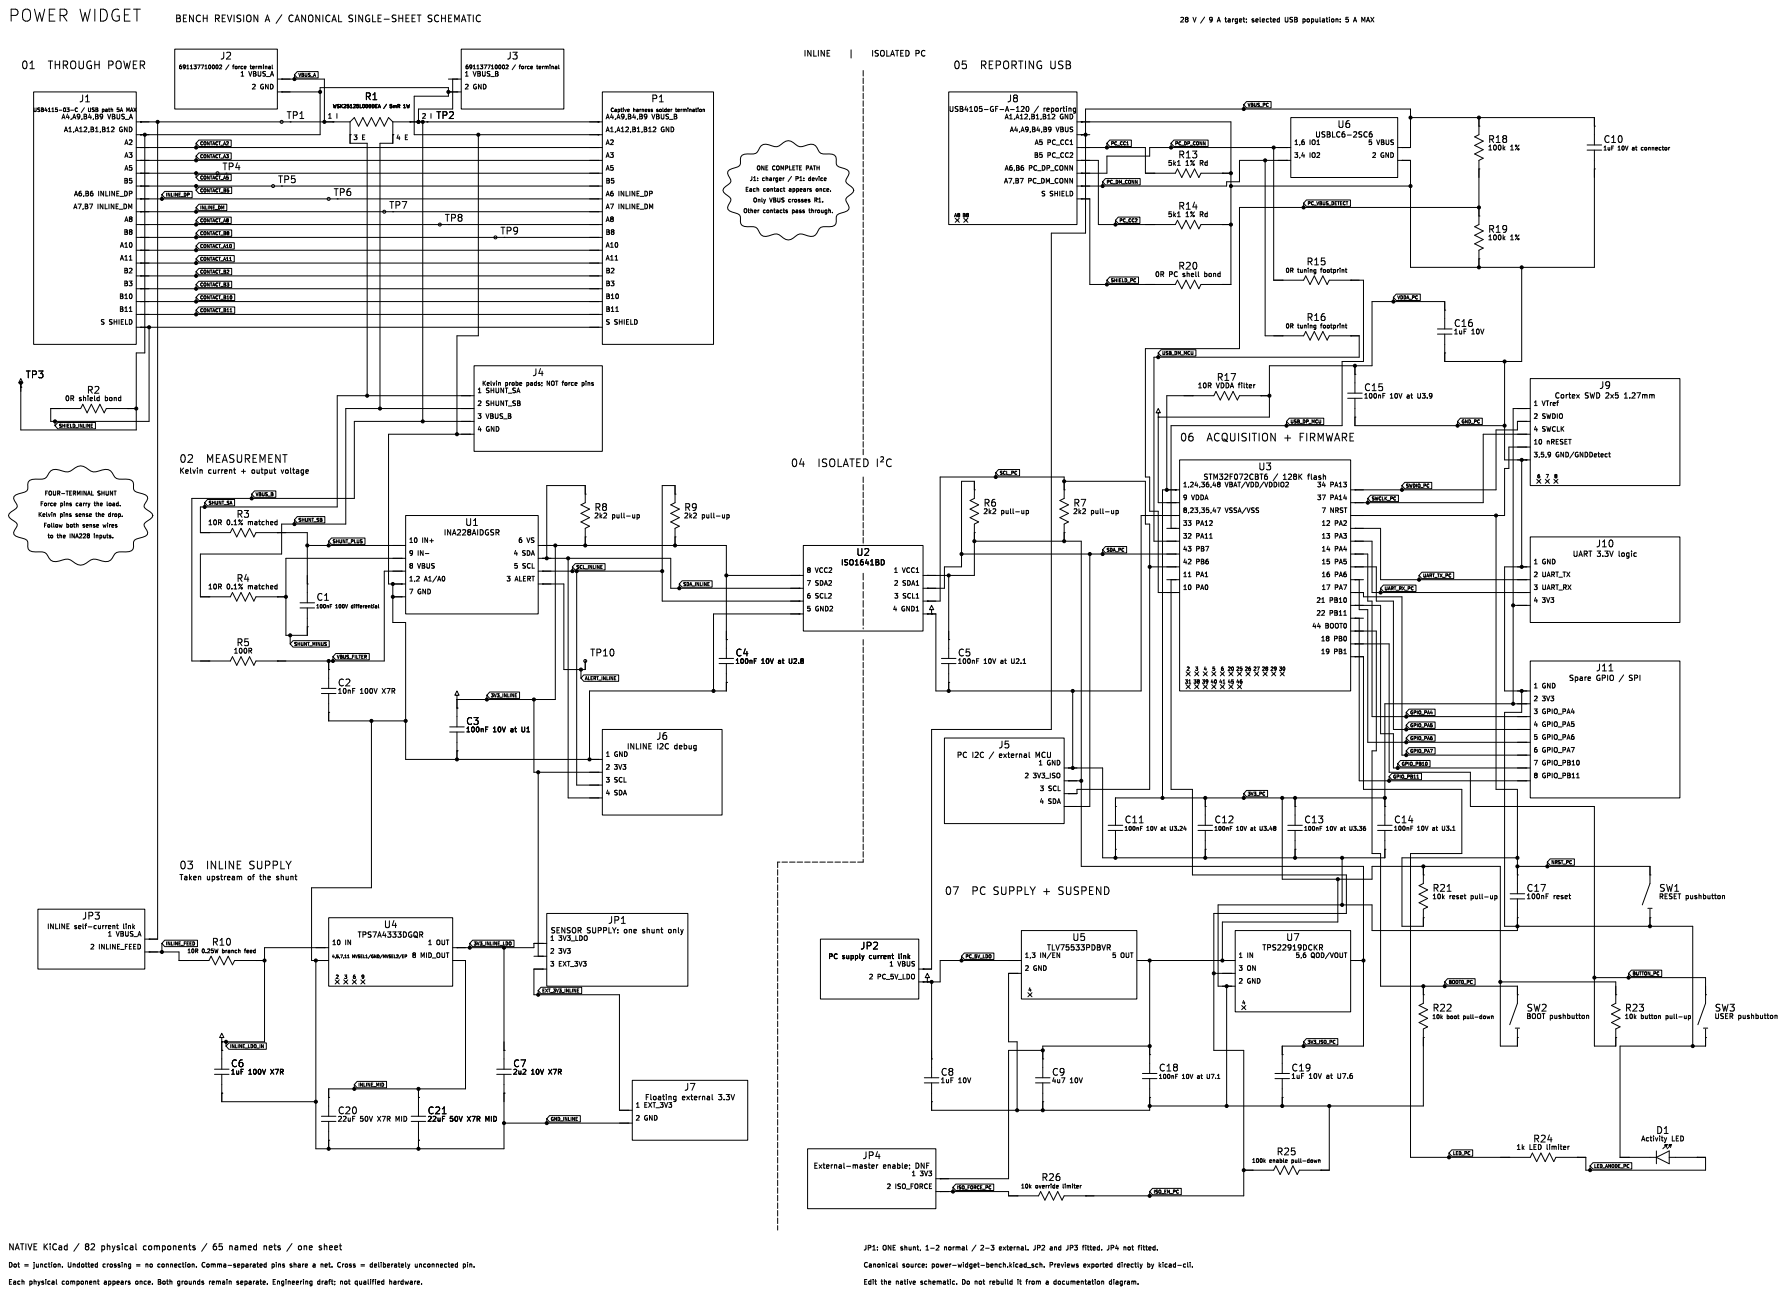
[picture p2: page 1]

BENCH REVISION A / CANONICAL SINGLE-SHEET SCHEMATIC

Captive harness solder termination
1uF 10V at connector A4,A9,B4,B9 VBUS_B
A2A3A5B5A6 INLINE_DP

Only VBUS crosses R1. FOUR-TERMINAL SHUNT

Kelvin current + output voltage

Force pins carry the load. Kelvin pins sense the drop. Follow both sense wires

PC supply current link C6

PC supply current link 1 EXT_3V3

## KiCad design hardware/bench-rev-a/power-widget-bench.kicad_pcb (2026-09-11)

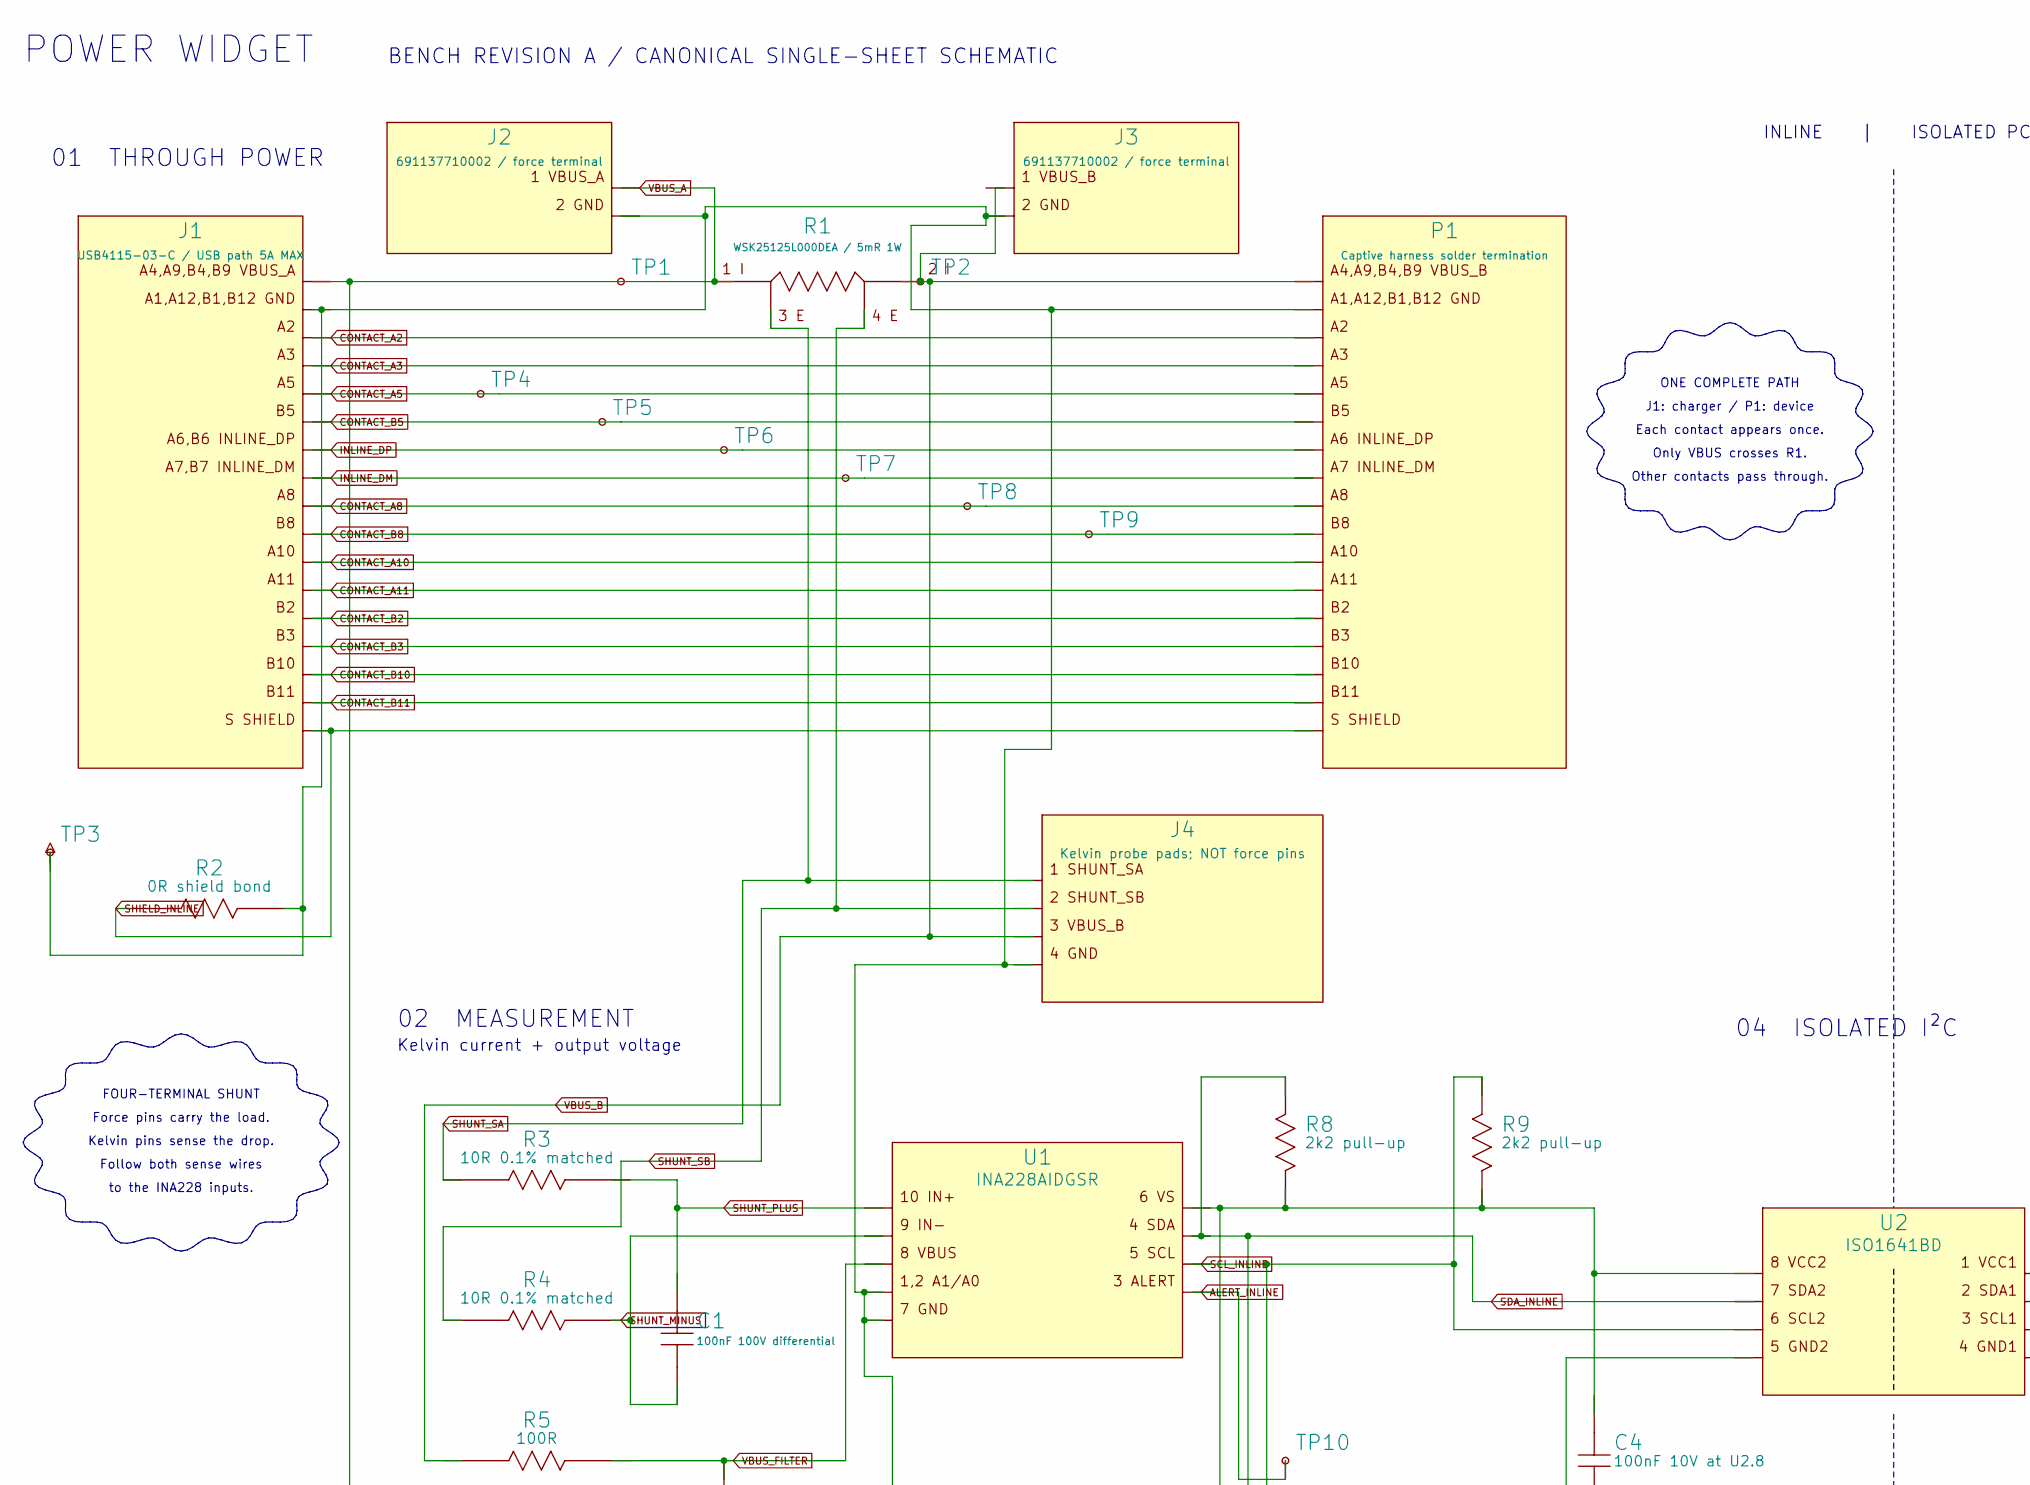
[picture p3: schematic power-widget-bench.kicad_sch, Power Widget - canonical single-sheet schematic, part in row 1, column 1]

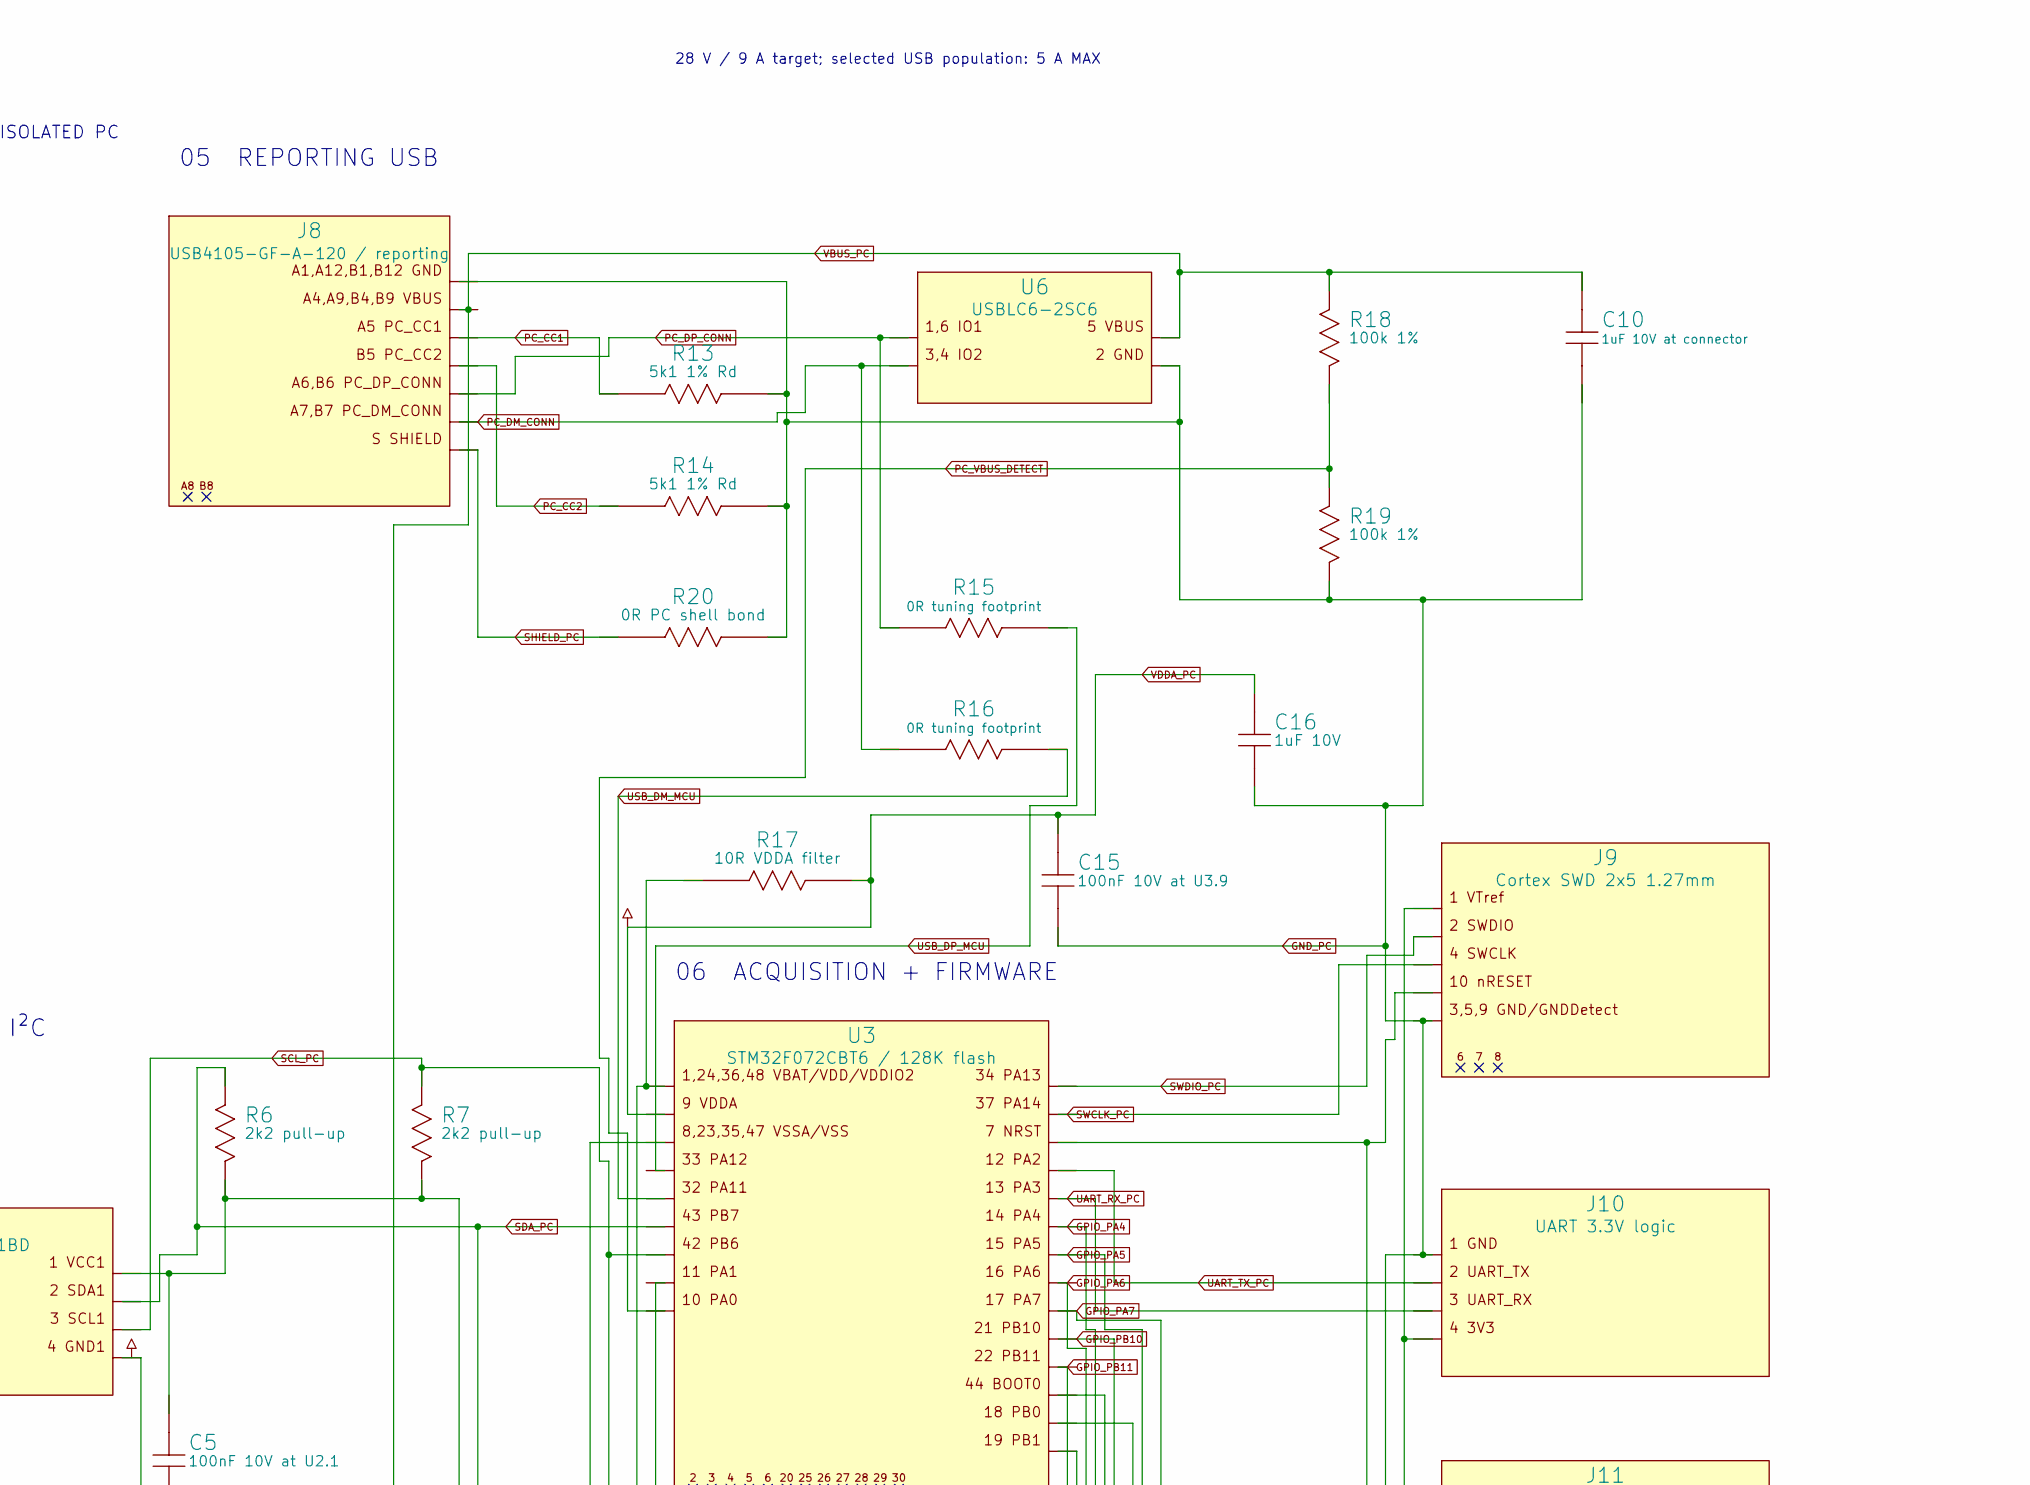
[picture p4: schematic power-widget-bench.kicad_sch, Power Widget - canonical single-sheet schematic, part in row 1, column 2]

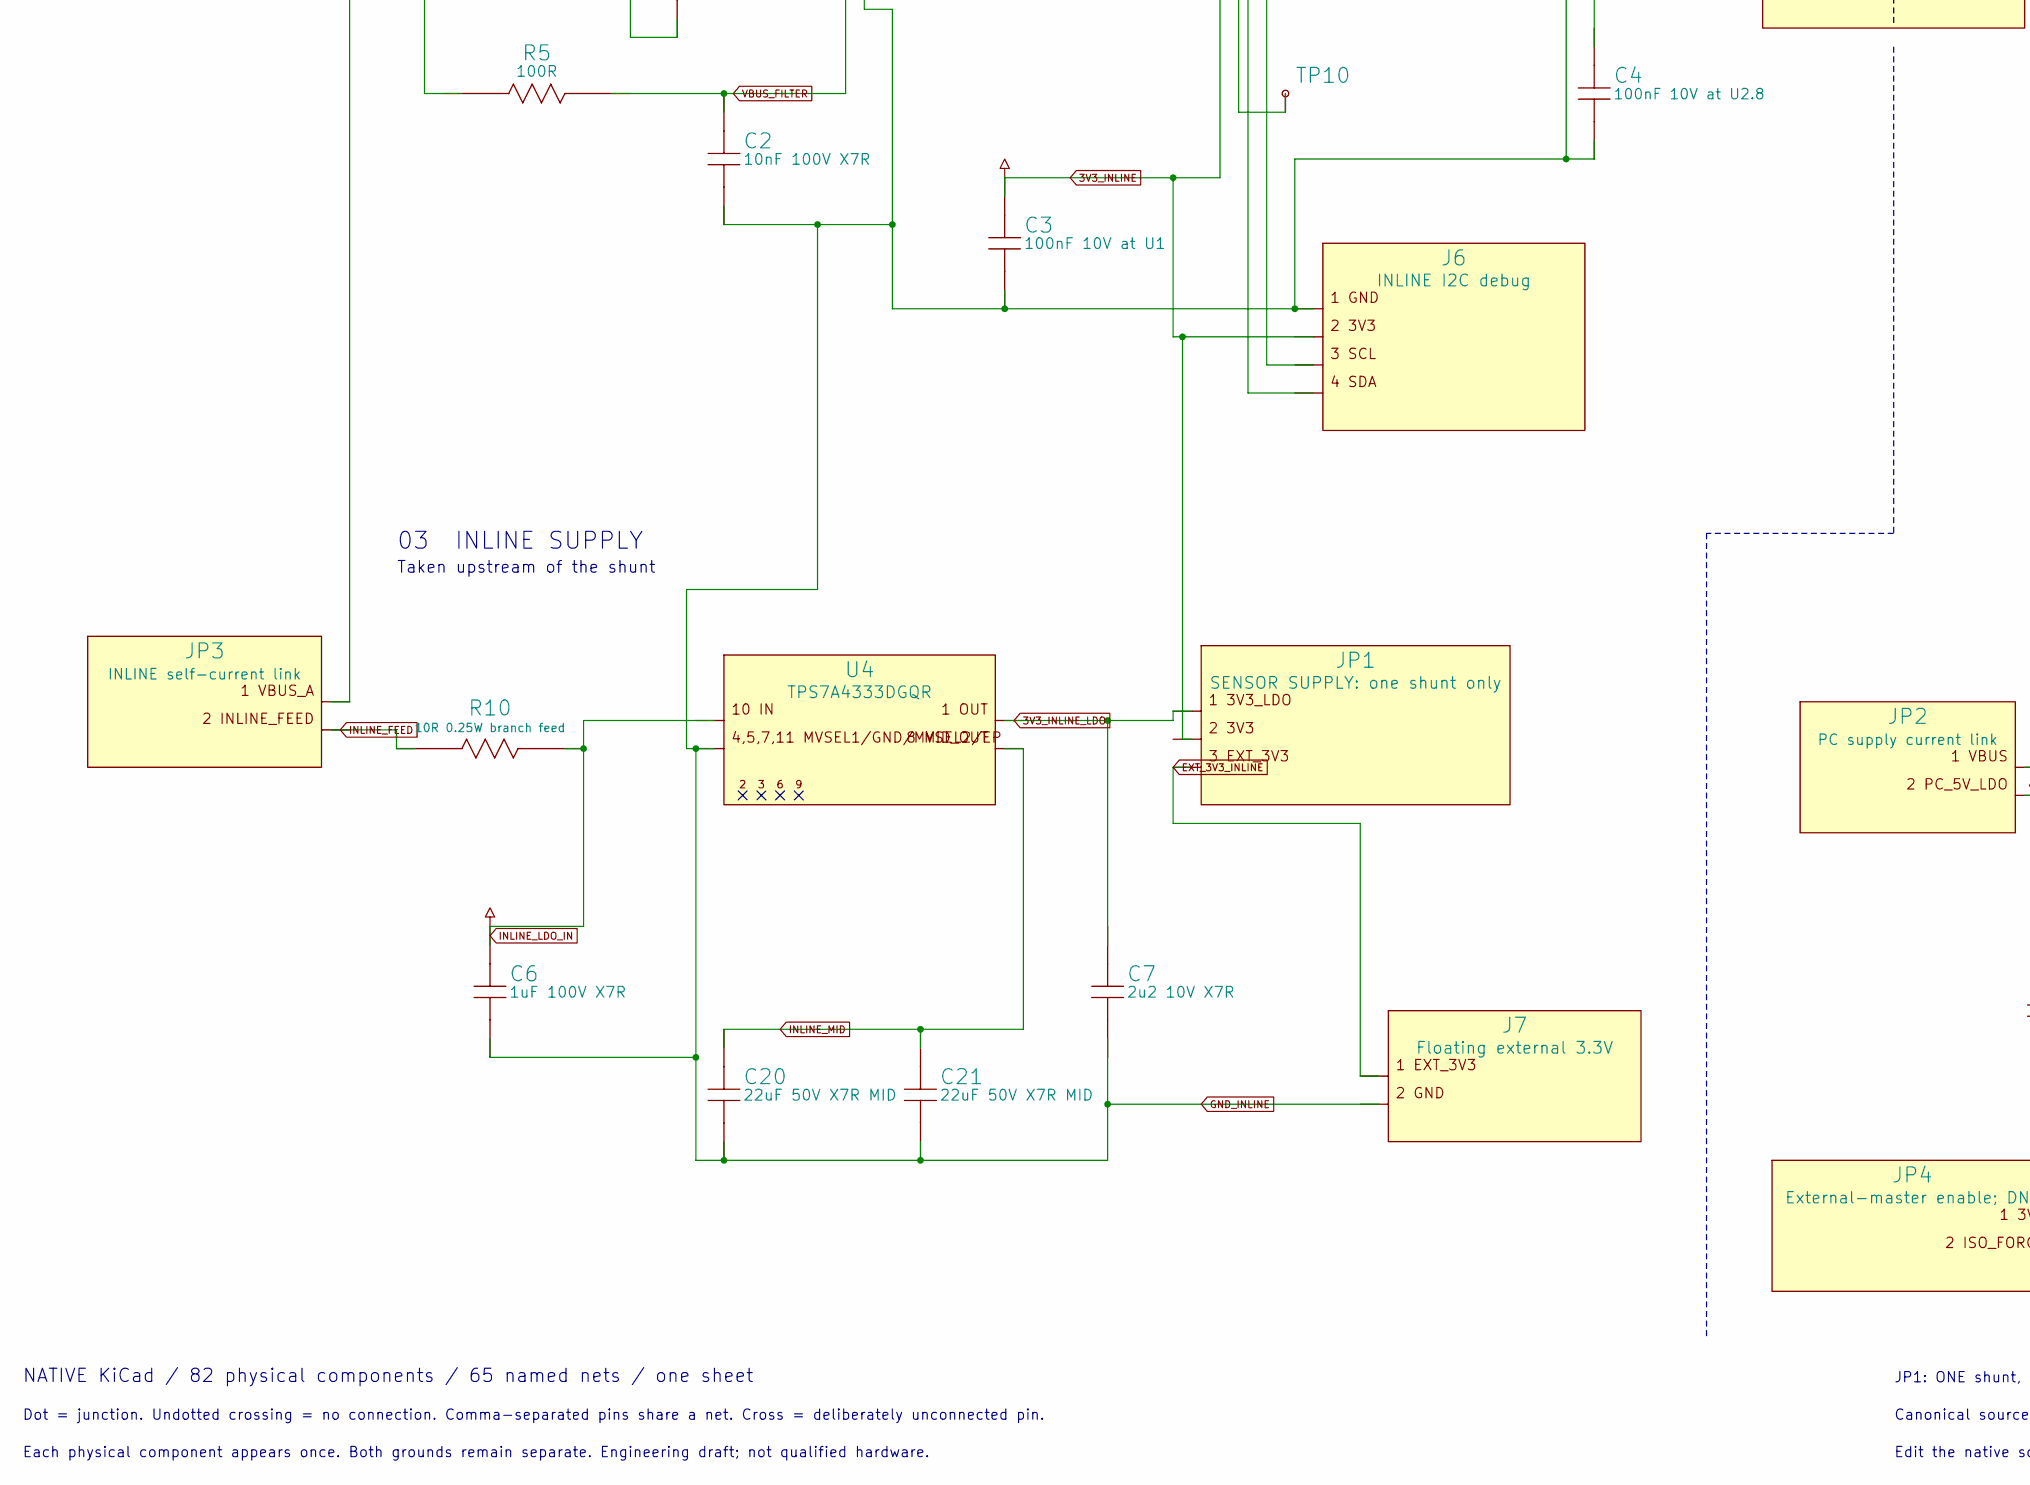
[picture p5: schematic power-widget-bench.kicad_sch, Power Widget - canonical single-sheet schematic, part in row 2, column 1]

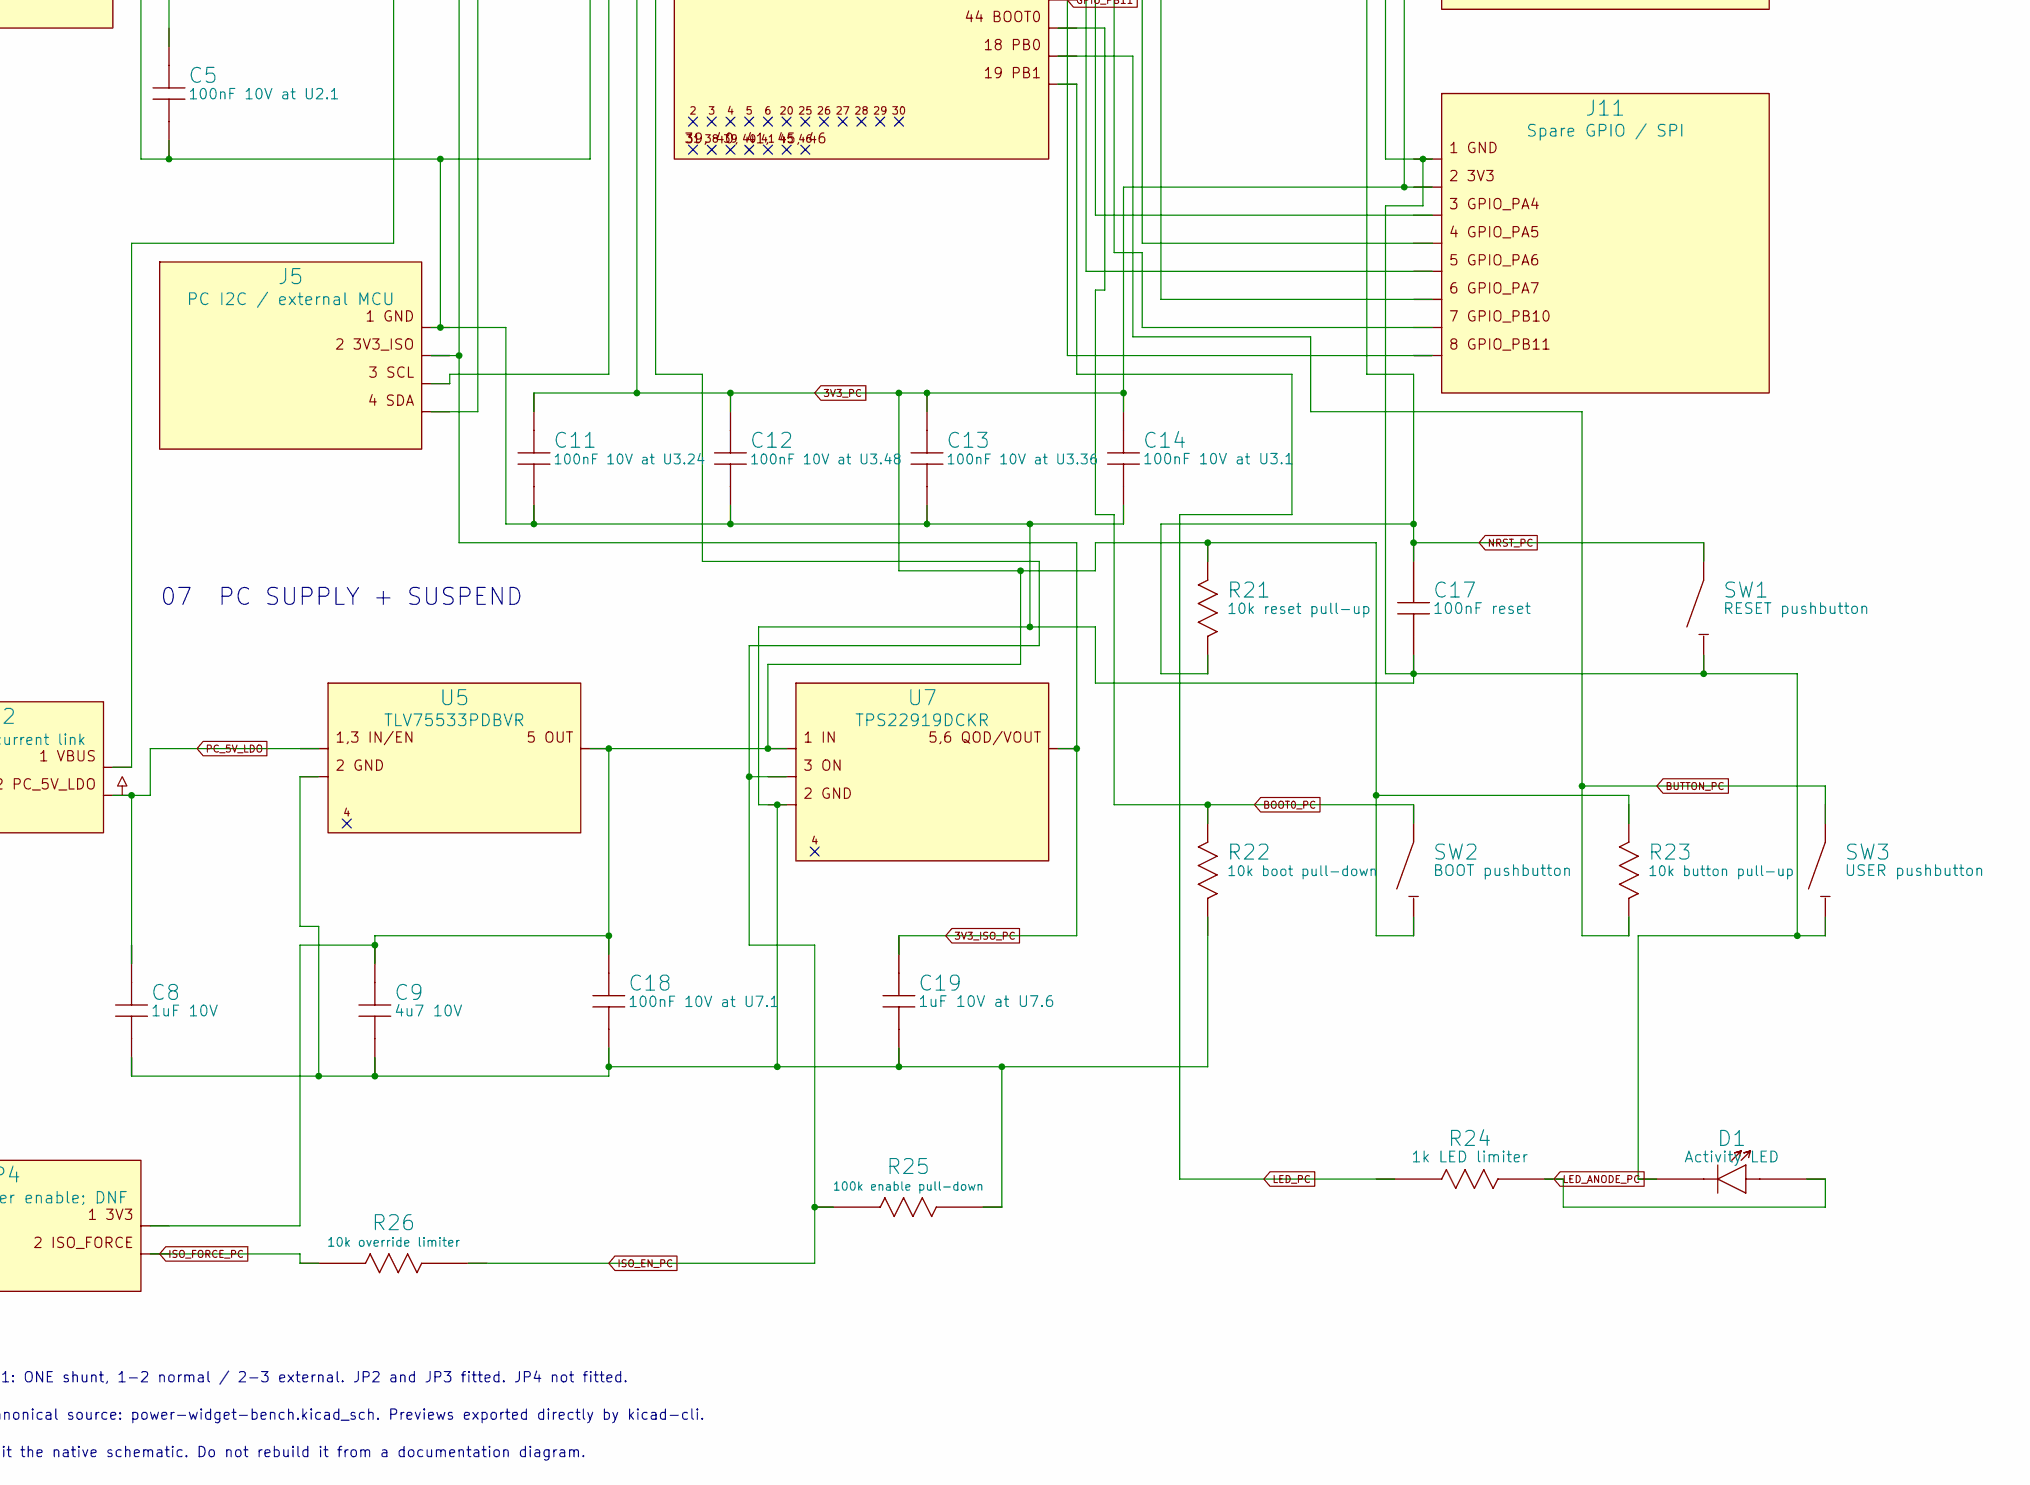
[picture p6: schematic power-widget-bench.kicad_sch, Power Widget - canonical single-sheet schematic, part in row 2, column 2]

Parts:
C1: 100nF 100V differential; C_0805_2012Metric
C2: 10nF 100V X7R; C_0805_2012Metric
C3: 100nF 10V at U1; C_0805_2012Metric
C4: 100nF 10V at U2.8; C_0805_2012Metric
C5: 100nF 10V at U2.1; C_0805_2012Metric
C6: 1uF 100V X7R; C_1210_3225Metric
C7: 2u2 10V X7R; C_0805_2012Metric
C8, C16: 1uF 10V; C_0805_2012Metric
C9: 4u7 10V; C_0805_2012Metric
C10: 1uF 10V at connector; C_0805_2012Metric
C11: 100nF 10V at U3.24; C_0805_2012Metric
C12: 100nF 10V at U3.48; C_0805_2012Metric
C13: 100nF 10V at U3.36; C_0805_2012Metric
C14: 100nF 10V at U3.1; C_0805_2012Metric
C15: 100nF 10V at U3.9; C_0805_2012Metric
C17: 100nF reset; C_0805_2012Metric
C18: 100nF 10V at U7.1; C_0805_2012Metric
C19: 1uF 10V at U7.6; C_0805_2012Metric
C20, C21: 22uF 50V X7R MID; C_1210_3225Metric
D1: Activity LED; LED_0805_2012Metric
J1: USB4115-03-C / USB path 5A MAX; USB_C_Receptacle_GCT_USB4115-03-C
J2, J3: 691137710002 / force terminal; Force_5mm_2pin
J4: Kelvin probe pads; NOT force pins; PinHeader_1x04_P2.54mm_Vertical
J5: PC I2C / external MCU; PinHeader_1x04_P2.54mm_Vertical
J6: INLINE I2C debug; PinHeader_1x04_P2.54mm_Vertical
J7: Floating external 3.3V; PinHeader_1x02_P2.54mm_Vertical
J8: USB4105-GF-A-120 / reporting; USB_C_Receptacle_GCT_USB4105-xx-A_16P_TopMnt_Horizontal
J9: Cortex SWD 2x5 1.27mm; PinHeader_2x05_P1.27mm_Vertical
J10: UART 3.3V logic; PinHeader_1x04_P2.54mm_Vertical
J11: Spare GPIO / SPI; PinHeader_1x08_P2.54mm_Vertical
JP1: SENSOR SUPPLY: one shunt only; PinHeader_1x03_P2.54mm_Vertical
JP2: PC supply current link; PinHeader_1x02_P2.54mm_Vertical
JP3: INLINE self-current link; PinHeader_1x02_P2.54mm_Vertical
JP4: External-master enable; DNF; PinHeader_1x02_P2.54mm_Vertical
P1: Captive harness solder termination; Captive_Termination
R1: WSK25125L000DEA / 5mR 1W; WSK2512_5mR
R2: 0R shield bond; R_0805_2012Metric
R3, R4: 10R 0.1% matched; R_0805_2012Metric
R5: 100R; R_0805_2012Metric
R6, R7, R8, R9: 2k2 pull-up; R_0805_2012Metric
R10: 10R 0.25W branch feed; R_0805_2012Metric
R13, R14: 5k1 1% Rd; R_0805_2012Metric
R15, R16: 0R tuning footprint; R_0805_2012Metric
R17: 10R VDDA filter; R_0805_2012Metric
R18, R19: 100k 1%; R_0805_2012Metric
R20: 0R PC shell bond; R_0805_2012Metric
R21: 10k reset pull-up; R_0805_2012Metric
R22: 10k boot pull-down; R_0805_2012Metric
R23: 10k button pull-up; R_0805_2012Metric
R24: 1k LED limiter; R_0805_2012Metric
R25: 100k enable pull-down; R_0805_2012Metric
R26: 10k override limiter; R_0805_2012Metric
SW1: RESET pushbutton; SW_SPST_TL3342
SW2: BOOT pushbutton; SW_SPST_TL3342
SW3: USER pushbutton; SW_SPST_TL3342
TP1: VBUS_A; TestPoint_Pad_D2.0mm
TP2: VBUS_B; TestPoint_Pad_D2.0mm
TP3: GND_INLINE; TestPoint_Pad_D2.0mm
TP4: CONTACT_A5; TestPoint_Pad_D2.0mm
TP5: CONTACT_B5; TestPoint_Pad_D2.0mm
TP6: INLINE_DP; TestPoint_Pad_D2.0mm
TP7: INLINE_DM; TestPoint_Pad_D2.0mm
TP8: CONTACT_A8; TestPoint_Pad_D2.0mm
TP9: CONTACT_B8; TestPoint_Pad_D2.0mm
TP10: ALERT: floating scope only; TestPoint_Pad_D2.0mm
U1: INA228AIDGSR; VSSOP-10_3x3mm_P0.5mm
U2: ISO1641BD; SOIC-8_3.9x4.9mm_P1.27mm
U3: STM32F072CBT6 / 128K flash; LQFP-48_7x7mm_P0.5mm
U4: TPS7A4333DGQR; HVSSOP10_DGQ
U5: TLV75533PDBVR; SOT-23-5
U6: USBLC6-2SC6; SOT-23-6
U7: TPS22919DCKR; SOT-363_SC-70-6

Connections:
3V3_INLINE: C3.1, C4.1, J6.2, JP1.2, R8.2, R9.2, U1.6 (VS), U2.8 (VCC2)
3V3_INLINE_LDO: C7.1, JP1.1, U4.1 (OUT)
3V3_ISO_PC: C5.1, C19.1, J5.2, R6.2, R7.2, U2.1 (VCC1), U7.5 (QOD), U7.6 (VOUT)
3V3_PC: C9.1, C11.1, C12.1, C13.1, C14.1, C18.1, J9.1 (VTref), J10.4, J11.2, JP4.1, R17.1, R21.1, R23.1, SW2.2, U3.1 (VBAT), U3.24 (VDD), U3.36 (VDDIO2), U3.48 (VDD), U5.5 (OUT), U7.1 (IN)
ALERT_INLINE: TP10.1, U1.3 (ALERT)
BOOT0_PC: R22.1, SW2.1, U3.44 (BOOT0)
BUTTON_PC: R23.2, SW3.1, U3.18 (PB0)
CONTACT_A2: J1.A2, P1.A2
CONTACT_A3: J1.A3, P1.A3
CONTACT_A5: J1.A5, P1.A5, TP4.1
CONTACT_A8: J1.A8, P1.A8, TP8.1
CONTACT_A10: J1.A10, P1.A10
CONTACT_A11: J1.A11, P1.A11
CONTACT_B2: J1.B2, P1.B2
CONTACT_B3: J1.B3, P1.B3
CONTACT_B5: J1.B5, P1.B5, TP5.1
CONTACT_B8: J1.B8, P1.B8, TP9.1
CONTACT_B10: J1.B10, P1.B10
CONTACT_B11: J1.B11, P1.B11
EXT_3V3_INLINE: J7.1, JP1.3
GND_INLINE: C2.2, C3.2, C4.2, C6.2, C7.2, C20.2, C21.2, J1.A1, J1.A12, J1.B1, J1.B12, J2.2, J3.2, J4.4, J6.1, J7.2, P1.A1, P1.A12, P1.B1, P1.B12, R2.2, TP3.1, U1.1 (A1), U1.2 (A0), U1.7 (GND), U2.5 (GND2), U4.4 (MVSEL1), U4.5 (GND), U4.7 (MVSEL2), U4.11 (EP)
GND_PC: C5.2, C8.2, C9.2, C10.2, C11.2, C12.2, C13.2, C14.2, C15.2, C16.2, C17.2, C18.2, C19.2, D1.1 (K), J5.1, J8.A1, J8.A12, J8.B1, J8.B12, J9.3 (GND), J9.5 (GND), J9.9 (GNDDetect), J10.1, J11.1, R13.2, R14.2, R19.2, R20.2, R22.2, R25.2, SW1.2, SW3.2, U2.4 (GND1), U3.8 (VSSA), U3.23 (VSS), U3.35 (VSS), U3.47 (VSS), U5.2 (GND), U6.2 (GND), U7.2 (GND)
GPIO_PA4: J11.3, U3.14 (PA4)
GPIO_PA5: J11.4, U3.15 (PA5)
GPIO_PA6: J11.5, U3.16 (PA6)
GPIO_PA7: J11.6, U3.17 (PA7)
GPIO_PB10: J11.7, U3.21 (PB10)
GPIO_PB11: J11.8, U3.22 (PB11)
INLINE_DM: J1.A7, J1.B7, P1.A7, TP7.1
INLINE_DP: J1.A6, J1.B6, P1.A6, TP6.1
INLINE_FEED: JP3.2, R10.1
INLINE_LDO_IN: C6.1, R10.2, U4.10 (IN)
INLINE_MID: C20.1, C21.1, U4.8 (MID_OUT)
ISO_EN_PC: R25.1, R26.2, U3.11 (PA1), U7.3 (ON)
ISO_FORCE_PC: JP4.2, R26.1
LED_ANODE_PC: D1.2 (A), R24.2
LED_PC: R24.1, U3.19 (PB1)
NRST_PC: C17.1, J9.10 (nRESET), R21.2, SW1.1, U3.7 (NRST)
PC_5V_LDO: C8.1, JP2.2, U5.1 (IN), U5.3 (EN)
PC_CC1: J8.A5, R13.1
PC_CC2: J8.B5, R14.1
PC_DM_CONN: J8.A7, J8.B7, R16.1, U6.3 (IO2), U6.4 (IO2)
PC_DP_CONN: J8.A6, J8.B6, R15.1, U6.1 (IO1), U6.6 (IO1)
PC_VBUS_DETECT: R18.2, R19.1, U3.10 (PA0)
SCL_INLINE: J6.3, R9.1, U1.5 (SCL), U2.6 (SCL2)
SCL_PC: J5.3, R7.1, U2.3 (SCL1), U3.42 (PB6)
SDA_INLINE: J6.4, R8.1, U1.4 (SDA), U2.7 (SDA2)
SDA_PC: J5.4, R6.1, U2.2 (SDA1), U3.43 (PB7)
SHIELD_INLINE: J1.S (SHIELD), P1.S (SHIELD), R2.1
SHIELD_PC: J8.S (SHIELD), R20.1
SHUNT_MINUS: C1.2, R4.2, U1.9 (IN-)
SHUNT_PLUS: C1.1, R3.2, U1.10 (IN+)
SHUNT_SA: J4.1, R1.3 (E1), R3.1
SHUNT_SB: J4.2, R1.4 (E2), R4.1
SWCLK_PC: J9.4 (SWCLK), U3.37 (PA14)
SWDIO_PC: J9.2 (SWDIO), U3.34 (PA13)
UART_RX_PC: J10.3, U3.13 (PA3)
UART_TX_PC: J10.2, U3.12 (PA2)
USB_DM_MCU: R16.2, U3.32 (PA11)
USB_DP_MCU: R15.2, U3.33 (PA12)
VBUS_A: J1.A4, J1.A9, J1.B4, J1.B9, J2.1, JP3.1, R1.1 (I1), TP1.1
VBUS_B: J3.1, J4.3, P1.A4, P1.A9, P1.B4, P1.B9, R1.2 (I2), R5.1, TP2.1
VBUS_FILTER: C2.1, R5.2, U1.8 (VBUS)
VBUS_PC: C10.1, J8.A4, J8.A9, J8.B4, J8.B9, JP2.1, R18.1, U6.5 (VBUS)
VDDA_PC: C15.1, C16.1, R17.2, U3.9 (VDDA)

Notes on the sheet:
01 THROUGH POWER
02 MEASUREMENT
Kelvin current + output voltage
03 INLINE SUPPLY
Taken upstream of the shunt
05 REPORTING USB
06 ACQUISITION + FIRMWARE
07 PC SUPPLY + SUSPEND
04 ISOLATED I²C
POWER WIDGET
BENCH REVISION A / CANONICAL SINGLE-SHEET SCHEMATIC
28 V / 9 A target; selected USB population: 5 A MAX
INLINE | ISOLATED PC
NATIVE KiCad / 82 physical components / 65 named nets / one sheet
Dot = junction. Undotted crossing = no connection. Comma-separated pins share a net. Cross = deliberately unconnected pin.
Each physical component appears once. Both grounds remain separate. Engineering draft; not qualified hardware.
JP1: ONE shunt, 1-2 normal / 2-3 external. JP2 and JP3 fitted. JP4 not fitted.
Canonical source: power-widget-bench.kicad_sch. Previews exported directly by kicad-cli.
Edit the native schematic. Do not rebuild it from a documentation diagram.
ONE COMPLETE PATH
J1: charger / P1: device
Each contact appears once.
Only VBUS crosses R1.
Other contacts pass through.
FOUR-TERMINAL SHUNT
Force pins carry the load.
Kelvin pins sense the drop.
Follow both sense wires
to the INA228 inputs.

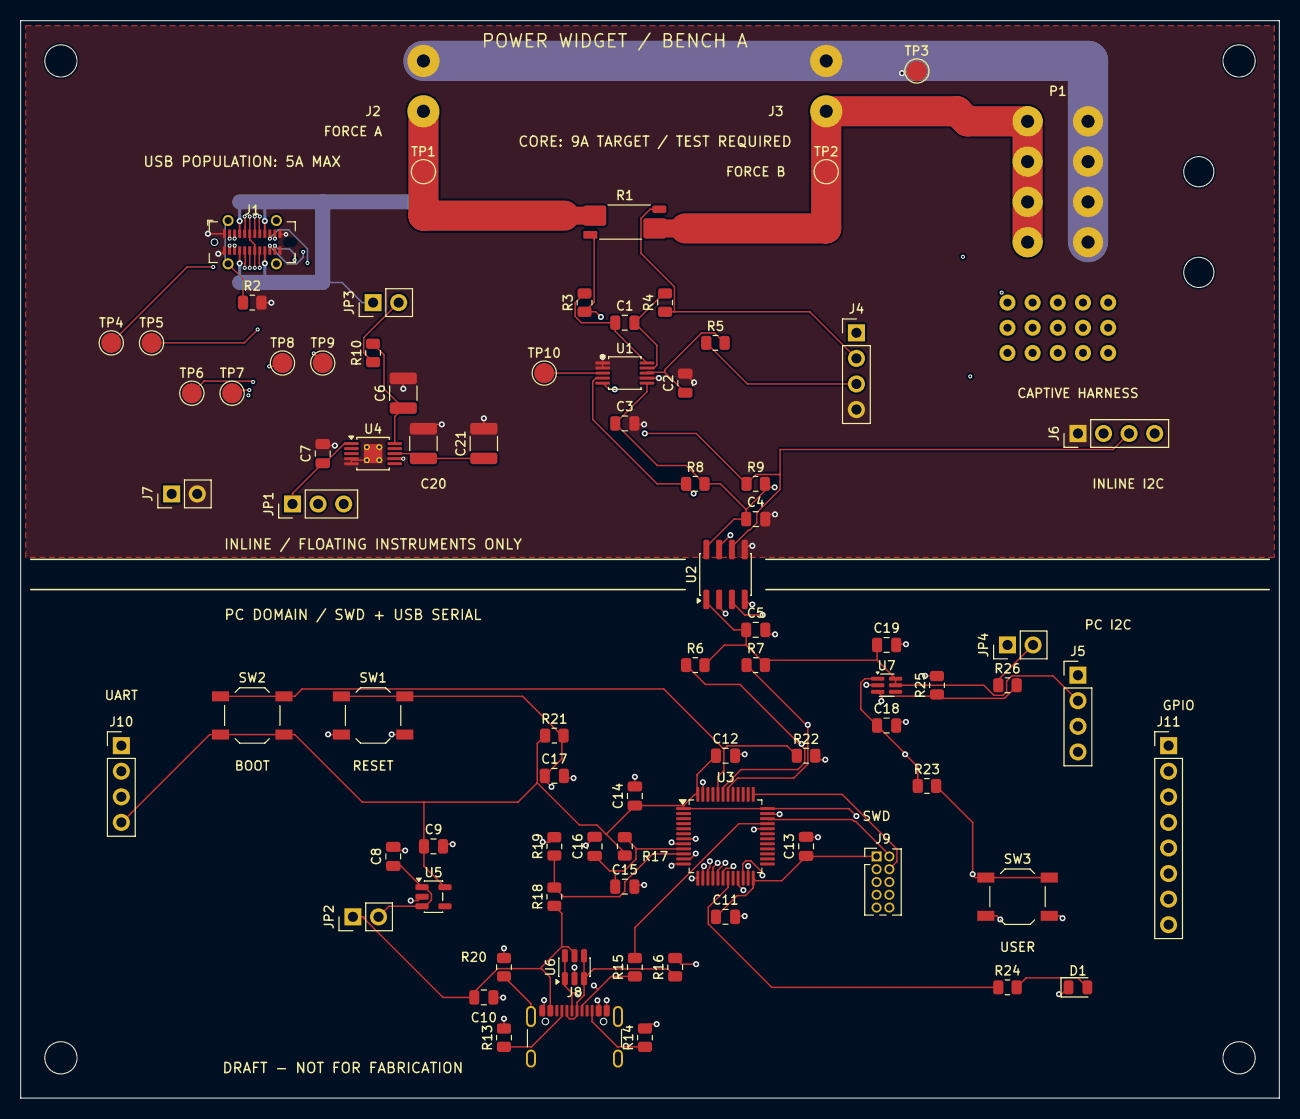
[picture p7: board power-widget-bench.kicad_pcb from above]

Board: 4 copper layers, 125.0 x 107.0 mm, 88 parts (0 on the bottom side), 65 nets.

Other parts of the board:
H99, H1269, H9108, H126108: MountingHole_3.2mm
H12220, H12230: StrainRelief_3mm

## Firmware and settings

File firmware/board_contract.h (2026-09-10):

/* Bench A planning contract; not a hardware driver or firmware binary.
 * Sources: STM32F072 DS9826 Rev 6; INA228 SLYS021A.
 * Pin numbers refer to STM32F072CBT6 LQFP48.
 */
#ifndef POWER_WIDGET_BOARD_CONTRACT_H
#define POWER_WIDGET_BOARD_CONTRACT_H

#include <stdint.h>

#define PW_BOARD_REVISION "A-DRAFT"
#define PW_MCU_PART "STM32F072CBT6"
#define PW_CPU_HZ UINT32_C(48000000)
#define PW_I2C_HZ UINT32_C(100000)
#define PW_REPORT_US UINT32_C(1000000)
#define PW_INA_WINDOW_NOMINAL_US UINT32_C(17280)
#define PW_SHUNT_NOMINAL_UOHM UINT32_C(5000)

/* GPIO port letter, bit and physical pin; peripheral selection is in README. */
#define PW_VBUS_GPIO 'A'
#define PW_VBUS_BIT 0u
#define PW_VBUS_PIN 10u
#define PW_ISO_ENABLE_GPIO 'A'
#define PW_ISO_ENABLE_BIT 1u
#define PW_ISO_ENABLE_PIN 11u
#define PW_I2C_GPIO 'B'
#define PW_I2C_SCL_BIT 6u
#define PW_I2C_SCL_PIN 42u
#define PW_I2C_SDA_BIT 7u
#define PW_I2C_SDA_PIN 43u
#define PW_I2C_AF 1u
#define PW_UART_GPIO 'A'
#define PW_UART_TX_BIT 2u
#define PW_UART_TX_PIN 12u
#define PW_UART_RX_BIT 3u
#define PW_UART_RX_PIN 13u
#define PW_UART_AF 1u
#define PW_USB_DM_PIN 32u
#define PW_USB_DP_PIN 33u
#define PW_SWDIO_PIN 34u
#define PW_SWCLK_PIN 37u
#define PW_USER_BUTTON_PIN 18u
#define PW_ACTIVITY_LED_PIN 19u

#define PW_INA_ADDR_7BIT 0x40u
#define PW_INA_REG_CONFIG 0x00u
#define PW_INA_REG_ADC_CONFIG 0x01u
#define PW_INA_REG_SHUNT_CAL 0x02u
#define PW_INA_REG_VSHUNT 0x04u
#define PW_INA_REG_VBUS 0x05u
#define PW_INA_REG_DIAG_ALRT 0x0bu
#define PW_INA_REG_MANUFACTURER_ID 0x3eu
#define PW_INA_REG_DEVICE_ID 0x3fu

/* ADCRANGE=0: +/-163.84 mV. No die-temperature shunt compensation. */
#define PW_INA_CONFIG 0x0000u
/* Continuous shunt+bus, 540 us each, temperature disabled, 16 averages. */
#define PW_INA_ADC_LOGGING 0xb922u
/* Diagnostic only: 1052 us each, 256 averages (AVG code 5, not 6). */
#define PW_INA_ADC_PRECISION 0xbb6du
/* ALATCH=1 makes the conversion-ready status clear on read; ALERT unused. */
#define PW_INA_DIAG_CONFIG 0x8000u
#define PW_INA_DIAG_READY 0x0002u
#define PW_INA_DIAG_MEMORY_OK 0x0001u
#define PW_INA_DIAG_MATH_OVERFLOW 0x0200u

/* Both data registers are three bytes, MSB first, with data in bits 23:4.
 * Keep calibrated calculations at greater precision than output units.
 * Wide-range shunt LSB = 312.5 nV; bus LSB = 195.3125 uV.
 * Gain/offset calibration is additional, and not implemented in this header.
 */
static inline uint32_t pw_unpack_u20(const uint8_t bytes[3]) {
    return ((uint32_t)bytes[0] << 12) |
           ((uint32_t)bytes[1] << 4) | ((uint32_t)bytes[2] >> 4);
}
static inline int32_t pw_unpack_s20(const uint8_t bytes[3]) {
    uint32_t raw = pw_unpack_u20(bytes);
    return (raw & UINT32_C(0x80000)) ?
           (int32_t)raw - INT32_C(1048576) : (int32_t)raw;
}

#endif

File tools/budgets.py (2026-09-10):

#!/usr/bin/env python3
"""Reproduce preliminary electrical budgets. No hardware or external packages.

Errors add conservatively; there is no RSS reduction. Allocated residuals and
noise are hypotheses to qualify. This is a steady-state model, not a simulation
of PD, thermal gradients, transient waveforms, protection, or USB integrity.
"""

import argparse
import csv
import io
import json
import math
from pathlib import Path

ROOT = Path(__file__).resolve().parents[1]


def accuracy(a, voltage, power, mode="logging_1s", calibrated=True):
    s, r, b = a["sensor"], a["shunt"], a["allocations"]
    current = power / voltage
    shunt_voltage = current * r["resistance_ohm"]
    i_terms = {
        "current_calibration": b["current_calibration_residual_fraction"],
        "shunt_temperature": r["tcr_ppm_per_c"] * 1e-6 * b["shunt_temperature_delta_c"],
        "sensor_gain_temperature": s["current_gain_drift_ppm_per_c"] * 1e-6 * b["chip_temperature_delta_c"],
        "layout_gain": b["current_layout_gain_fraction"],
        "offset": s["offset_v"] / shunt_voltage,
        "offset_temperature": s["offset_drift_v_per_c"] * b["chip_temperature_delta_c"] / shunt_voltage,
        "common_mode": abs(voltage - s["offset_reference_common_mode_v"]) / 10 ** (s["cmrr_db"] / 20) / shunt_voltage,
        "supply": s["shunt_psrr_v_per_v"] * b["regulated_supply_delta_v"] / shunt_voltage,
        "input_filter_bias": 2 * s["input_bias_a"] * b["sense_filter_each_ohm"] / shunt_voltage,
        "layout_thermal_emf": b["thermoelectric_and_layout_offset_v"] / shunt_voltage,
        "noise_allocation": a["modes"][mode]["shunt_noise_absolute_v_allocation"] / shunt_voltage,
        "quantization_half_lsb": 0.5 * s["shunt_lsb_v"] / shunt_voltage,
    }
    if not calibrated:
        # Conservative sensitivity case: add original shunt tolerance to the
        # calibrated model. This is not a substitute complete uncalibrated spec.
        i_terms["additional_uncalibrated_shunt_tolerance"] = r["initial_tolerance_fraction"]
    v_terms = {
        "voltage_calibration": b["voltage_calibration_residual_fraction"],
        "sensor_gain_temperature": s["bus_gain_drift_ppm_per_c"] * 1e-6 * b["chip_temperature_delta_c"],
        "layout_gain": b["voltage_layout_gain_fraction"],
        "offset": s["bus_offset_v"] / voltage,
        "offset_temperature": s["bus_offset_drift_v_per_c"] * b["chip_temperature_delta_c"] / voltage,
        "supply": s["bus_psrr_v_per_v"] * b["regulated_supply_delta_v"] / voltage,
        "bus_filter_loading": b["bus_filter_max_series_ohm"] / s["bus_input_min_ohm"],
        "noise_allocation": b["bus_noise_absolute_v"] / voltage,
        "quantization_half_lsb": 0.5 * s["bus_lsb_v"] / voltage,
    }
    # The main electronics supply is taken before the shunt. VBUS-input and
    # output protection leakage can remain in the reading. Budget full burden.
    output_burden_w = voltage * (voltage / s["bus_input_min_ohm"] + b["extra_output_leakage_a"])
    i_error, v_error = sum(i_terms.values()), sum(v_terms.values())
    # Bound both multiplicative errors and the output burden conservatively.
    power_error = (1 + i_error) * (1 + v_error) - 1
    power_error += output_burden_w / power * (1 + v_error)
    req = a["requirements"]
    limit = req["normal_power_error_percent"] if power >= req["precision_threshold_w"] else req["low_power_error_percent"]
    return {
        "mode": mode, "voltage_v": voltage, "power_w": power,
        "current_a": current, "shunt_uv": shunt_voltage * 1e6,
        "current_error_percent": i_error * 100,
        "voltage_error_percent": v_error * 100,
        "output_burden_w": output_burden_w,
        "power_error_percent": power_error * 100,
        "target_percent": limit,
        "within_allocation": power_error * 100 <= limit,
        "current_terms_fraction": i_terms, "voltage_terms_fraction": v_terms,
    }


def path_loss(a, current):
    r, p, b = a["shunt"], a["passive_path"], a["allocations"]
    copper_factor = 1 + p["copper_alpha_per_c"] * p["hot_conductor_delta_c"]
    cable_r = 2 * p["pigtail_length_m"] * p["copper_resistivity_ohm_m_at_20c"] / (p["pigtail_each_polarity_area_mm2"] * 1e-6)
    cold = {"shunt": r["resistance_ohm"], "pcb_loop": p["pcb_vbus_and_ground_ohm_at_20c"],
            "added_mating_interface_loop": p["additional_mating_interface_loop_ohm_at_20c"], "pigtail_loop": cable_r}
    hot = {"shunt": cold["shunt"] * (1 + r["tcr_ppm_per_c"] * 1e-6 * p["hot_conductor_delta_c"]),
           "pcb_loop": cold["pcb_loop"] * copper_factor,
           "added_mating_interface_loop": cold["added_mating_interface_loop"] * p["contact_hot_multiplier"],
           "pigtail_loop": cold["pigtail_loop"] * copper_factor}
    return {
        "current_a": current, "cold_parts_ohm": cold, "hot_parts_ohm": hot,
        "hot_loop_ohm": sum(hot.values()), "hot_drop_v": current * sum(hot.values()),
        "hot_passive_loss_w": current * current * sum(hot.values()),
        "shunt_nominal_drop_v": current * r["resistance_ohm"],
        "shunt_nominal_loss_w": current * current * r["resistance_ohm"],
        "meter_supply_power_at_28v_w": a["requirements"]["voltage_max_v"] * b["inline_supply_current_a"],
        "regulator_heat_at_28v_w": (a["requirements"]["voltage_max_v"] - b["inline_supply_output_v"]) * b["inline_supply_current_a"],
    }


def main():
    parser = argparse.ArgumentParser()
    parser.add_argument("--check", action="store_true", help="check committed outputs without rewriting")
    args = parser.parse_args()
    a = json.loads((ROOT / "analysis/assumptions.json").read_text())
    req, s, r = a["requirements"], a["sensor"], a["shunt"]
    analysis_current = req["current_analysis_scenario_a"]
    design_current = analysis_current * req["margin_factor"]
    selected = []
    for mode in a["modes"]:
        for voltage in [5.0, 9.0, 15.0, 20.0, 28.0]:
            for power in [0.5, 1.0, 5.0, voltage * analysis_current]:
                selected.append(accuracy(a, voltage, power, mode))
    # Cover voltage endpoints and temperature/offset worst-case terms at fine
    # voltage spacing. Include threshold-neighbor powers and current endpoints.
    grid = []
    for step in range(231):
        voltage = 5 + step / 10
        max_power = voltage * analysis_current
        powers = [0.5, 1, 4.999, 5, 5.001, max_power]
        powers += [0.5 * (max_power / 0.5) ** (j / 80) for j in range(81)]
        grid.extend(accuracy(a, voltage, power) for power in sorted(set(powers)))
    worst_normal = max((x for x in grid if x["power_w"] >= 5), key=lambda x: x["power_error_percent"])
    worst_low = max((x for x in grid if x["power_w"] < 5), key=lambda x: x["power_error_percent"])
    modes = {}
    for name, mode in a["modes"].items():
        period_s = mode["conversion_time_us_per_channel"] * 1e-6 * mode["averages"] * mode["enabled_channels"]
        modes[name] = {
            "nominal_window_s": period_s, "nominal_fresh_updates_hz": 1 / period_s,
            "typical_noise_free_step_uv": 2 * s["shunt_range_v"] / 2 ** mode["datasheet_typical_noise_free_enob"] * 1e6,
            "absolute_noise_allocation_uv": mode["shunt_noise_absolute_v_allocation"] * 1e6,
            "report_window_s": mode.get("software_report_window_s", period_s),
            "noise_scope": mode.get("noise_scope", "one hardware conversion/averaging window"),
        }
    nominal_limit = s["shunt_range_v"] / r["resistance_ohm"]
    resistance_high = r["resistance_ohm"] * (1 + r["initial_tolerance_fraction"]) * (1 + r["tcr_ppm_per_c"] * 1e-6 * a["allocations"]["shunt_temperature_delta_c"])
    loss_rows = [path_loss(a, i) for i in sorted(set([5, analysis_current, design_current]))]
    main_loss = path_loss(a, analysis_current)
    scenarios = []
    for rating in req["current_scenarios_a"]:
        design = rating * req["margin_factor"]
        shunt_heat = design ** 2 * resistance_high
        scenarios.append({
            "hypothetical_oem_max_a": rating - req["manufacturer_allowance_a"],
            "hypothetical_rating_a": rating, "design_current_a": design,
            "rating_power_at_28v_w": rating * req["voltage_max_v"],
            "high_resistance_shunt_heat_at_design_current_w": shunt_heat,
            "within_75_percent_of_1w_shunt_allocation": shunt_heat <= 0.75 * r["rated_power_w_at_70c"],
            "adc_range_covers_design_current": design < s["shunt_range_v"] / resistance_high,
            "hot_passive_loss_at_rating_w": path_loss(a, rating)["hot_passive_loss_w"],
        })
    sensitivity = {
        "retain_shunt_tolerance_28v_5w": accuracy(a, 28, 5, calibrated=False),
        "trend_28v_half_watt": accuracy(a, 28, 0.5, mode="trend"),
    }
    summary = {
        "status": a["status"], "evaluated_grid_points": len(grid),
        "verified_oem_max_current_a": req["verified_oem_max_current_a"],
        "analysis_current_scenario_a": analysis_current,
        "analysis_is_final_current_rating": False,
        "current_scenarios": scenarios,
        "worst_normal_precision": worst_normal, "worst_low_precision": worst_low,
        "nominal_current_adc_limit_a": nominal_limit,
        "high_resistance_current_adc_limit_a": s["shunt_range_v"] / resistance_high,
        "design_voltage_v": req["voltage_max_v"] * req["margin_factor"],
        "scenario_design_current_a": design_current,
        "sense_filter_nominal_corner_hz": 1 / (2 * math.pi * 2 * a["allocations"]["sense_filter_each_ohm"] * a["allocations"]["sense_filter_cap_f"]),
        "modes": modes, "path_loss": loss_rows, "sensitivity": sensitivity,
    }
    # Independent dimensional and boundary sanity checks; these validate the
    # calculator, not hardware. Failing a design allocation is also reported.
    assert math.isclose(6 * .005, .03)
    assert math.isclose(6 ** 2 * .005, .18)
    assert math.isclose(28 * 6, 168)
    assert math.isclose(130 / 20, 6.5)
    assert accuracy(a, 28, 4.999)["target_percent"] == 5
    assert accuracy(a, 28, 5)["target_percent"] == 1
    assert summary["high_resistance_current_adc_limit_a"] > design_current
    assert math.isclose((8.5 + req["manufacturer_allowance_a"]) * req["margin_factor"], 10.8)
    assert all(row["within_75_percent_of_1w_shunt_allocation"] for row in scenarios), "Laptop current scenario exceeds shunt allocation"
    assert worst_normal["within_allocation"] and worst_low["within_allocation"], "Precision allocation exceeds target"
    assert not sensitivity["trend_28v_half_watt"]["within_allocation"], "Reassess separate trend specification"
    assert main_loss["hot_loop_ohm"] <= a["passive_path"]["hot_added_loop_target_ohm"]

    lines = ["# Calculated budgets", "", "Generated by `python tools/budgets.py` from `analysis/assumptions.json`.", "",
             "**Provisional allocations, not measured performance.** See [method and limitations](../docs/budgets.md).", "",
             f'Current rule: verified OEM maximum + 0.5 A, followed by 20% design margin. **The documented laptop-roster maximum is {req["verified_oem_max_current_a"]:g} A. The selected continuous design target is {analysis_current:g} A; hardware qualification is pending.**', "",
             "## One-second logging DC error allocation", "",
             "| Voltage | Power | Current | Shunt signal | Calculated error bound | Target |", "|---|---|---|---|---|---|"]
    for x in selected:
        if x["mode"] == "logging_1s":
            lines.append(f'| {x["voltage_v"]:g} V | {x["power_w"]:g} W | {x["current_a"]*1000:.3f} mA | {x["shunt_uv"]:.3f} µV | {x["power_error_percent"]:.3f}% | {x["target_percent"]:g}% |')
    lines += ["", f'The sweep evaluates {len(grid):,} points. Largest precision allocation at ≥5 W: **{worst_normal["power_error_percent"]:.3f}%** ({worst_normal["voltage_v"]:g} V, {worst_normal["power_w"]:g} W). Below 5 W: **{worst_low["power_error_percent"]:.3f}%** ({worst_low["voltage_v"]:g} V, {worst_low["power_w"]:g} W).', "",
              "## Timing and noise", "", "| Mode | Sensor window | Fresh updates | Report window | Noise allocation |", "|---|---|---|---|---|"]
    for name, m in modes.items():
        lines.append(f'| {name} | {m["nominal_window_s"]*1000:.3f} ms | {m["nominal_fresh_updates_hz"]:.2f}/s | {m["report_window_s"]:g} s | ±{m["absolute_noise_allocation_uv"]:g} µV |')
    lines += ["", f'Trend-mode allocation at 28 V / 0.5 W: **{sensitivity["trend_28v_half_watt"]["power_error_percent"]:.3f}%**; it does not meet the low-power precision target.', "",
              "Logging mode uses frequent 17.28 ms sensor windows and one-second software aggregation. Its ±1 µV noise allocation applies to the final one-second average and requires bench validation; do not assume correlated errors average away. The older precision mode remains a calibration/diagnostic option. These DC budgets do not bound transient energy error.", "",
              "## Added resistance and losses: captive-pigtail candidate", "",
              "| Current | Shunt drop | Shunt heat | Hot added loop | Hot added drop | Hot passive loss |", "|---|---|---|---|---|---|"]
    for x in loss_rows:
        lines.append(f'| {x["current_a"]:g} A | {x["shunt_nominal_drop_v"]*1000:.2f} mV | {x["shunt_nominal_loss_w"]:.4f} W | {x["hot_loop_ohm"]*1000:.3f} mΩ | {x["hot_drop_v"]*1000:.2f} mV | {x["hot_passive_loss_w"]:.3f} W |')
    lines += ["", "These are sizing scenarios, not qualified cable ratings or instructions to overload generic USB connectors.", "",
              f'Inline supply allocation at 28 V: **{main_loss["meter_supply_power_at_28v_w"]:.3f} W**, including about {main_loss["regulator_heat_at_28v_w"]:.3f} W in the linear regulator. Add this to passive losses when estimating total heat; it is excluded from the forward shunt reading.', "",
              "## Manufacturer-current rule sensitivity", "", "| Hypothetical OEM max | Hypothetical rating | Design current | Shunt heat at design current | Within 75% of 1 W allocation? |", "|---|---|---|---|---|"]
    for x in scenarios:
        lines.append(f'| {x["hypothetical_oem_max_a"]:g} A | {x["hypothetical_rating_a"]:g} A | {x["design_current_a"]:g} A | {x["high_resistance_shunt_heat_at_design_current_w"]:.3f} W | {"Yes" if x["within_75_percent_of_1w_shunt_allocation"] else "No — change shunt"} |')
    lines += ["", "The 75% allocation is an engineering derating target assuming the resistor remains within its 70°C full-power condition. It does not replace thermal qualification.", "",
              "## Range and calibration sensitivity", "",
              f'- ADC current range with 5 mΩ: ±{nominal_limit:.3f} A nominal, ±{summary["high_resistance_current_adc_limit_a"]:.3f} A at the modeled high resistance.',
              f'- Retaining an additional 0.5% shunt tolerance raises the 28 V / 5 W allocation to {sensitivity["retain_shunt_tolerance_28v_5w"]["power_error_percent"]:.3f}%; per-unit calibration is a real requirement.',
              "- Connector qualification, thermal gradients, transient response, and long-term drift remain outside this calculator.", ""]
    csv_buffer = io.StringIO(newline="")
    fields = ["mode", "voltage_v", "power_w", "current_a", "shunt_uv", "current_error_percent", "voltage_error_percent", "output_burden_w", "power_error_percent", "target_percent", "within_allocation"]
    writer = csv.DictWriter(csv_buffer, fieldnames=fields, extrasaction="ignore", lineterminator="\n")
    writer.writeheader()
    writer.writerows(selected)
    outputs = {ROOT / "analysis/results.json": json.dumps(summary, indent=2) + "\n",
               ROOT / "analysis/accuracy.csv": csv_buffer.getvalue(),
               ROOT / "analysis/results.md": "\n".join(lines)}
    for path, content in outputs.items():
        if args.check:
            if not path.exists() or path.read_text() != content:
                raise SystemExit(f"Stale result: {path.relative_to(ROOT)}")
        else:
            path.write_text(content)
    print(f'{"Checked" if args.check else "Wrote"} {len(outputs)} outputs; {analysis_current:g} A scenario; {len(grid):,} points; precision worst {worst_normal["power_error_percent"]:.3f}% / {worst_low["power_error_percent"]:.3f}%; hot loop {main_loss["hot_loop_ohm"]*1000:.3f} mΩ.')


if __name__ == "__main__":
    main()

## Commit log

2026-09-10 Initialize power monitor brief and topology decision
2026-09-10 Document charging feasibility gates and preliminary sensing architecture
2026-09-10 Apply OEM current headroom rule and checkpoint reproducible design plan
    [accuracy.csv]
2026-09-10 Set laptop current envelope and captive connector bench baseline
2026-09-10 Capture full firmware bench circuit and one-second energy logging design
    [01-inline.kicad_sch, 02-sensing.kicad_sch, 03-supplies.kicad_sch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]
2026-09-10 Route the firmware bench PCB and record clean native KiCad checks
    [01-inline.kicad_sch, 02-sensing.kicad_sch, 03-supplies.kicad_sch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]
2026-09-10 Surface PCB and circuit previews in READMEs and refresh design status
2026-09-11 Add complete single-sheet schematic and lead README with it
2026-09-11 Document reusable schematic prompt and original inspiration
2026-09-11 Label schematic mockup and require canonical native design in prompt
2026-09-11 Make single-sheet layout the canonical KiCad schematic and export README from it
    [01-inline.kicad_sch, 02-sensing.kicad_sch, 03-supplies.kicad_sch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]
2026-09-11 Clear schematic lettering and check native rendered text overlaps
    [power-widget-bench.kicad_sch]
